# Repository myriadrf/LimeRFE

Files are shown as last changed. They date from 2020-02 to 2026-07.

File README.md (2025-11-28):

# LimeRFE

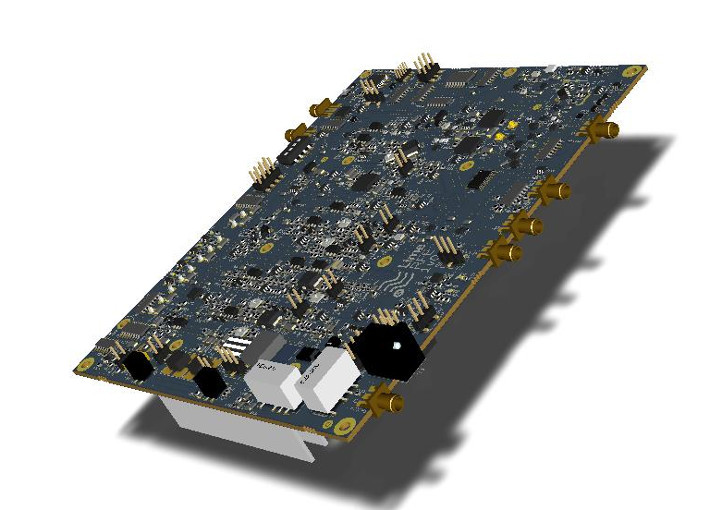
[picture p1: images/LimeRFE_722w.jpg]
LimeRFE board


The [LimeRFE](https://www.crowdsupply.com/lime-micro/limerfe) is an open hardware power amplifier (PA) module with appropriate filtering and support circuitry to augment the LimeSDR, LimeSDR Mini, and LimeNET Micro platforms, providing a complete solution that addresses real life applications ranging from HAM radio to standards-compliant cellular network implementations.

## Contents

The directory structure is as follows:

      /archived/<version>/           - Archived versions
          firmware/                  - Corresponding firmware
                                     - Remaining structure as below

      /firmware/                     - Firmware sources

      /hardware/<version>/
          docs/                      - Documentation
          hardware/
              BOM/                   - Bill of materials
              Gerbers/               - Manufacturing files
              KiCAD/                 - KiCAD schematic and layout files
              PDF/                   - Schematic and layout PDFs

## Notes on hardware versions

The resources for all production builds will be located in versioned folders in the repository root. The files located under `/archived/` correspond to pre-production designs used in validation and with the beta tester community.

### Production boards

* 1v31. This is the first version to go into full production.

### Pre-production boards

Pre-production boards are not officially supported. However, design materials and firmware sources are made available in the hope that this will assist those who may wish to make their own modifications and repairs etc. 

* 1v2. This features a number of minor improvements to the 1v0 design, mainly in
connection with cellular bands.
* 1v0. This design featured the full complement of bands following [update of the specifications](https://www.crowdsupply.com/lime-micro/limerfe/updates/performance-of-the-final-production-board). A small number of boards were made available to application developers to facilitate software integration.
* 0v3. This version was the first made available to the beta tester community and it has a reduced number of branches/bands, which corresponds to the original published specifications. 

## Software

Software support is provided by [Lime Suite](https://github.com/myriadrf/LimeSuite).

## Licensing

The hardware designs are licensed under Solderpad Hardware License v2.1.

Hardware designs 0v3, 1v0 and 1v2 are also available under a Creative Commons
Attribution 3.0 Unported licence.

Firmware sources are licensed under the Apache License Version 2.0.

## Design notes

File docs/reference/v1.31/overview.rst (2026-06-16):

Overview
########

The scope of this chapter is in detailed explanation of the block diagram of the LimeRFE board. The above mentioned block diagram is shown in Figure 3. Please keep in mind that this block diagram depicts only RF part of the board. 

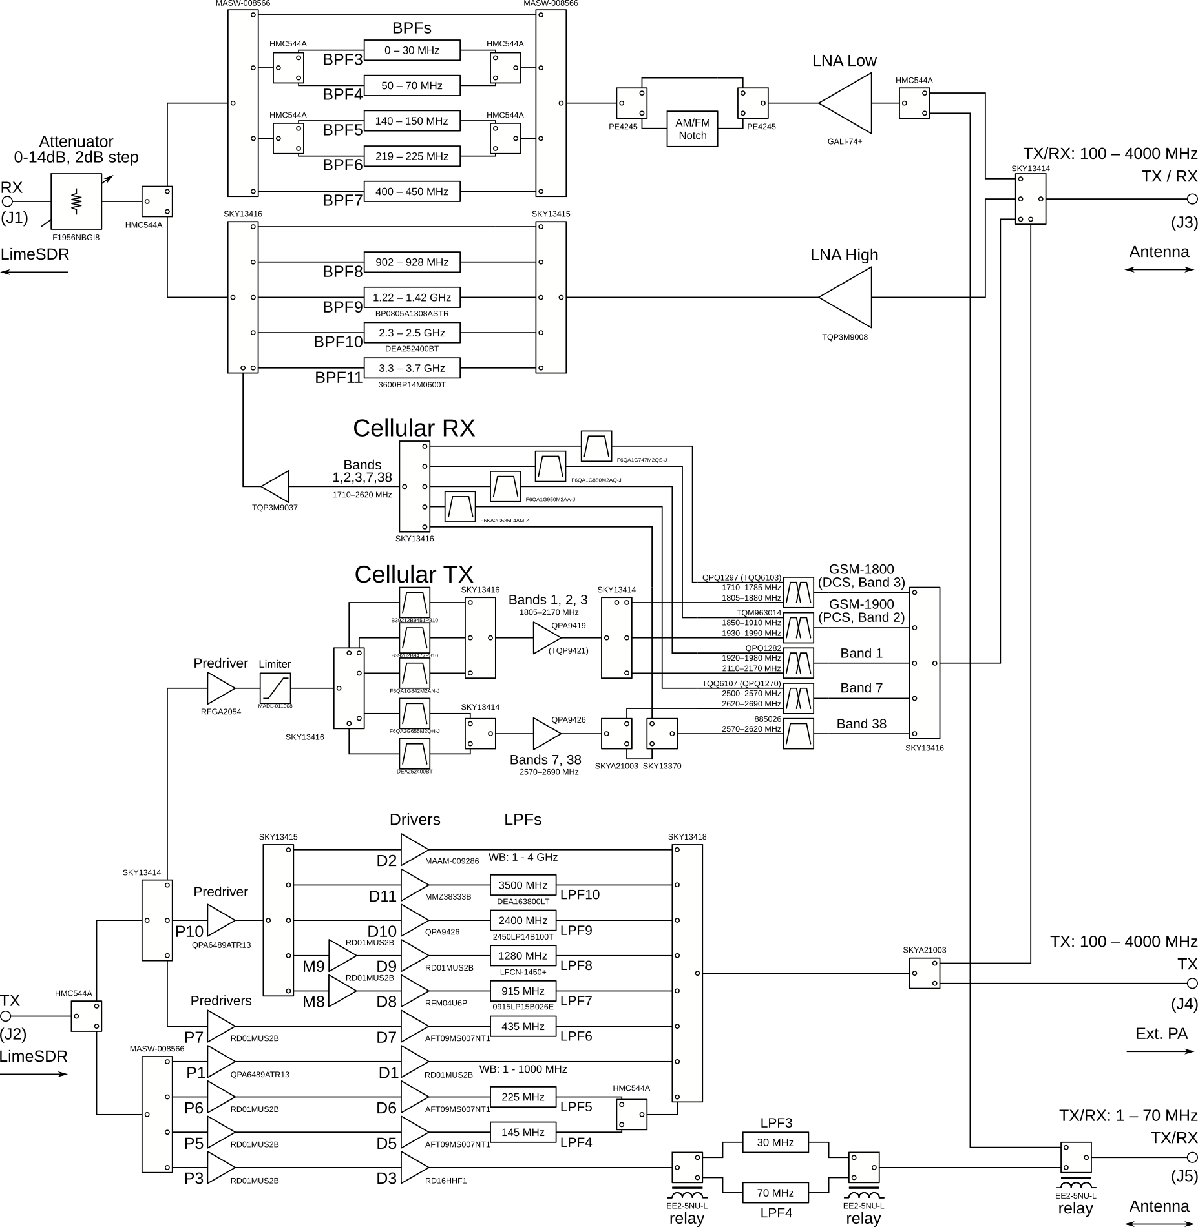
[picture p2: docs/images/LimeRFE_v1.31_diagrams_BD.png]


  Figure 3: LimeRFE v1.31 board block diagram

Basically, the board comprises receiver and transmitter blocks, where both of them have Wideband, HAM and Cellular sub-blocks. These sub-blocks are not strictly divided and separated, for example HAM and Wideband have been realised under the same hardware. Photo of the LimeRFE board, with marked most important RF blocks is shown in Figure 4 and in Figure 5. 

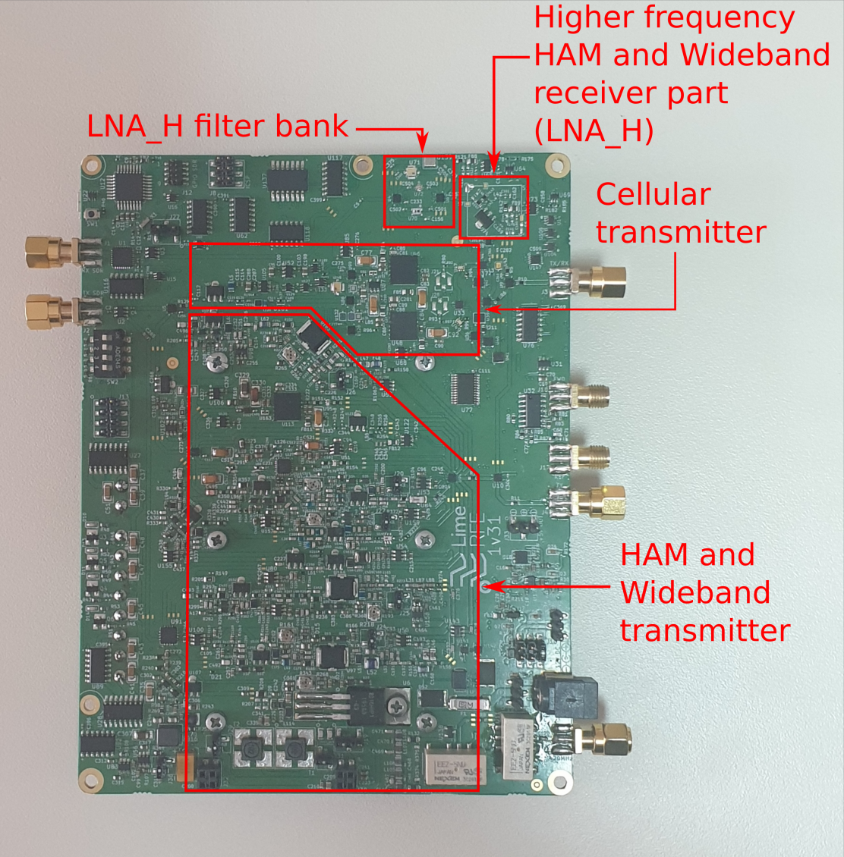
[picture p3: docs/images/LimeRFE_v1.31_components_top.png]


  Figure 4: Receiver and transmitter sub-blocks – Top view

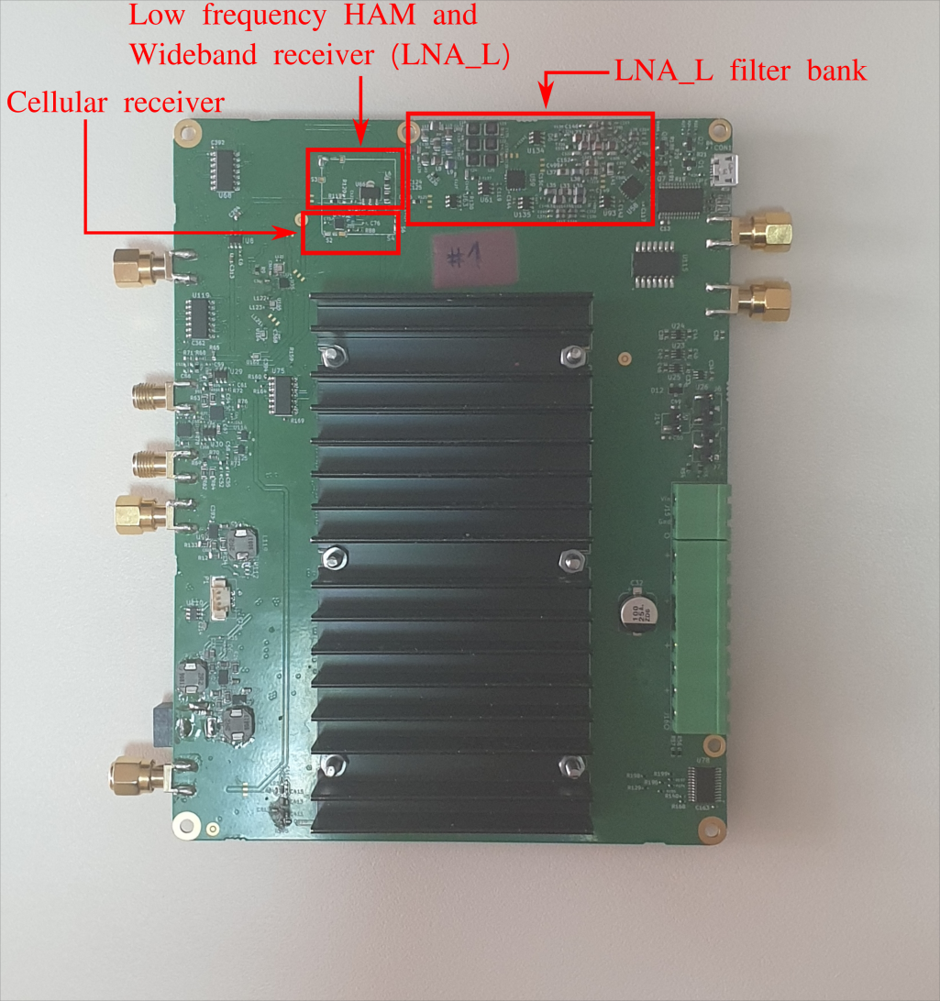
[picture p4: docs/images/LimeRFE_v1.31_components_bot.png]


  Figure 5: Receiver and transmitter sub-blocks – Bottom view
    
.. table:: Table 1. Board components

  +-----------------------+--------------------------------------+-----------------------------------------------------------------------------------------------------+
  | **Board Reference**   | **Type**                             | **Description**                                                                                     |
  +=======================+======================================+=====================================================================================================+
  | **DC Supply Block**                                                                                                                                                |
  +-----------------------+--------------------------------------+-----------------------------------------------------------------------------------------------------+
  | J9                    | 3 pin header                         | 12V DC input                                                                                        |
  +-----------------------+--------------------------------------+-----------------------------------------------------------------------------------------------------+
  | J23                   | Power Barrel Connector Jack          | 12V DC input                                                                                        |
  +-----------------------+--------------------------------------+-----------------------------------------------------------------------------------------------------+
  | J10                   | 3 pin header                         | 5V DC input                                                                                         |
  +-----------------------+--------------------------------------+-----------------------------------------------------------------------------------------------------+
  | J11                   | 3x2 pin header                       | 5V input selector                                                                                   |
  +-----------------------+--------------------------------------+-----------------------------------------------------------------------------------------------------+
  | J33                   | 3 pin header                         | 5V DC output                                                                                        |
  +-----------------------+--------------------------------------+-----------------------------------------------------------------------------------------------------+
  | U17                   | LDO 3V                               | Provides a stable 3V DC                                                                             |
  +-----------------------+--------------------------------------+-----------------------------------------------------------------------------------------------------+
  | U18                   | LDO 2.5V                             | Provides a stable 2.5V DC                                                                           |
  +-----------------------+--------------------------------------+-----------------------------------------------------------------------------------------------------+
  | U19                   | DC-DC converter                      | Converts 12V to internal 5V                                                                         |
  +-----------------------+--------------------------------------+-----------------------------------------------------------------------------------------------------+
  | U20                   | 5V input protection                  | Monitors and protects 5V input                                                                      |
  +-----------------------+--------------------------------------+-----------------------------------------------------------------------------------------------------+
  | U21                   | DC-DC converter                      | Converts 12V to internal 7.5V                                                                       |
  +-----------------------+--------------------------------------+-----------------------------------------------------------------------------------------------------+
  | U90                   | DC-DC converter                      | Converts 12V to external 5V                                                                         |
  +-----------------------+--------------------------------------+-----------------------------------------------------------------------------------------------------+
  | U112                  | LDO 2.5V                             | Provides a stable 2.5V DC                                                                           |
  +-----------------------+--------------------------------------+-----------------------------------------------------------------------------------------------------+
  | D3                    | LED                                  | +3V indicator                                                                                       |
  +-----------------------+--------------------------------------+-----------------------------------------------------------------------------------------------------+
  | D7                    | LED                                  | +5V indicator                                                                                       |
  +-----------------------+--------------------------------------+-----------------------------------------------------------------------------------------------------+
  | D8                    | LED                                  | +5V_MCU indicator                                                                                   |
  +-----------------------+--------------------------------------+-----------------------------------------------------------------------------------------------------+
  | D9                    | LED                                  | +7.5V indicator                                                                                     |
  +-----------------------+--------------------------------------+-----------------------------------------------------------------------------------------------------+
  | D36                   | LED                                  | +2.5V indicator                                                                                     |
  +-----------------------+--------------------------------------+-----------------------------------------------------------------------------------------------------+
  | U110                  | Power switch                         | Switches +5V DC voltage for external fan.                                                           |
  +-----------------------+--------------------------------------+-----------------------------------------------------------------------------------------------------+
  | U83                   | Power switch                         | Switches +12V supply for the DA (driver) for HAM30 and HAM70                                        |
  +-----------------------+--------------------------------------+-----------------------------------------------------------------------------------------------------+
  | U56                   | Power switch                         | Switches +12V supply for the PA (power amplifier) for HAM30 and HAM70                               |
  +-----------------------+--------------------------------------+-----------------------------------------------------------------------------------------------------+
  | U100                  | Power switch                         | Switches +7.5V supply for the DA for HAM145                                                         |
  +-----------------------+--------------------------------------+-----------------------------------------------------------------------------------------------------+
  | U50                   | Power switch                         | Switches +7.5V supply for the PA for HAM145                                                         |
  +-----------------------+--------------------------------------+-----------------------------------------------------------------------------------------------------+
  | U153                  | Power switch                         | Switches +7.5V supply for the DA for HAM220                                                         |
  +-----------------------+--------------------------------------+-----------------------------------------------------------------------------------------------------+
  | U158                  | Power switch                         | Switches +7.5V supply for the PA for HAM220                                                         |
  +-----------------------+--------------------------------------+-----------------------------------------------------------------------------------------------------+
  | U80                   | Power switch                         | Switches +5V supply for the DA for WB1000                                                           |
  +-----------------------+--------------------------------------+-----------------------------------------------------------------------------------------------------+
  | U54                   | Power switch                         | Switches +5V supply for the PA for WB1000                                                           |
  +-----------------------+--------------------------------------+-----------------------------------------------------------------------------------------------------+
  | U155                  | Power switch                         | Switches +12V supply for the DA for HAM920                                                          |
  +-----------------------+--------------------------------------+-----------------------------------------------------------------------------------------------------+
  | U159                  | Power switch                         | Switches +7.5V supply for the PA for HAM920                                                         |
  +-----------------------+--------------------------------------+-----------------------------------------------------------------------------------------------------+
  | U157                  | Power switch                         | Switches +12V supply for the DA for HAM1280                                                         |
  +-----------------------+--------------------------------------+-----------------------------------------------------------------------------------------------------+
  | U53                   | Power switch                         | Switches +12V supply for the PA for HAM1280                                                         |
  +-----------------------+--------------------------------------+-----------------------------------------------------------------------------------------------------+
  | U51                   | Power switch                         | Switches +5V supply for the PA for HAM3500                                                          |
  +-----------------------+--------------------------------------+-----------------------------------------------------------------------------------------------------+
  | U122                  | Power switch                         | Switches +5V supply for the PA for WB4000                                                           |
  +-----------------------+--------------------------------------+-----------------------------------------------------------------------------------------------------+
  | U120                  | Power switch                         | Switches +5V supply for the PA for HAM2400                                                          |
  +-----------------------+--------------------------------------+-----------------------------------------------------------------------------------------------------+
  | U106                  | LDO 2.8V                             | LDO for PA supply for the HAM2400, (U113)                                                           |
  +-----------------------+--------------------------------------+-----------------------------------------------------------------------------------------------------+
  | U96                   | Power switch                         | Switches +7.5V supply for the DA for HAM435                                                         |
  +-----------------------+--------------------------------------+-----------------------------------------------------------------------------------------------------+
  | U55                   | Power switch                         | Switches +7.5V supply for the PA for HAM435                                                         |
  +-----------------------+--------------------------------------+-----------------------------------------------------------------------------------------------------+
  | U102                  | Power switch                         | Switches +7.5V supply for the DA for HAM920, HAM1280, HAM3500, HAM2400 and WB4000                   |
  +-----------------------+--------------------------------------+-----------------------------------------------------------------------------------------------------+
  | U105                  | Power switch                         | Switches +5V supply for the DA for Cellular bands 1, 2, 3, 7 and 38                                 |
  +-----------------------+--------------------------------------+-----------------------------------------------------------------------------------------------------+
  | U87                   | LDO 2.8V                             | LDO for PA supply for the Cellular bands 1, 2 and 3, (U48)                                          |
  +-----------------------+--------------------------------------+-----------------------------------------------------------------------------------------------------+
  | U88                   | Power switch                         | Switches +5V supply for the PA Cellular bands 1, 2 and 3 (U48)                                      |
  +-----------------------+--------------------------------------+-----------------------------------------------------------------------------------------------------+
  | U52                   | LDO 2.8V                             | LDO for PA supply for the Cellular bands 7 and 38, (U46)                                            |
  +-----------------------+--------------------------------------+-----------------------------------------------------------------------------------------------------+
  | U85                   | Power switch                         | Switches +5V supply for the PA Cellular bands 7 and 38 (U46)                                        |
  +-----------------------+--------------------------------------+-----------------------------------------------------------------------------------------------------+
  | U130                  | DC switch                            | Switches +3V supply for the PA Cellular bands 7 and 38 (U46)                                        |
  +-----------------------+--------------------------------------+-----------------------------------------------------------------------------------------------------+
  | U133                  | Buffer                               | Switches +3V supply for the PA Cellular bands 7 and 38 (U46)                                        |
  +-----------------------+--------------------------------------+-----------------------------------------------------------------------------------------------------+
  | U73                   | Power switch                         | Switches +5V supply for the LNA for higher frequency bands (HAM1280, HAM3500,                       |
  |                       |                                      |                                                                                                     |
  |                       |                                      | HAM2400, HAM920 and WB4000)                                                                         |
  +-----------------------+--------------------------------------+-----------------------------------------------------------------------------------------------------+
  | U65                   | Power switch                         | Switches +5V supply for the LNA for lower frequency bands (HAM30, HAM70, HAM145,                    |
  |                       |                                      |                                                                                                     |
  |                       |                                      | HAM220, HAM435 and WB1000)                                                                          |
  +-----------------------+--------------------------------------+-----------------------------------------------------------------------------------------------------+
  | U31                   | Power switch                         | Switches +5V supply for the SWR section                                                             |
  +-----------------------+--------------------------------------+-----------------------------------------------------------------------------------------------------+
  | **MCU and Digital Block**                                                                                                                                          |
  +-----------------------+--------------------------------------+-----------------------------------------------------------------------------------------------------+
  | U12                   | MCU                                  | ATMEGA 328P microcontroller                                                                         |
  +-----------------------+--------------------------------------+-----------------------------------------------------------------------------------------------------+
  | U13                   | USB-to-serial chip                   | Converts USB to MCU serial communication and vice versa                                             |
  +-----------------------+--------------------------------------+-----------------------------------------------------------------------------------------------------+
  | J8                    | ICSP connector                       | SPI bus to MCU                                                                                      |
  +-----------------------+--------------------------------------+-----------------------------------------------------------------------------------------------------+
  | D1, D2                | LED                                  | USB to Serial communication indicator                                                               |
  +-----------------------+--------------------------------------+-----------------------------------------------------------------------------------------------------+
  | CON1                  | USB mini-B connector                 | USB connector for the LimeRFE board                                                                 |
  +-----------------------+--------------------------------------+-----------------------------------------------------------------------------------------------------+
  | U22                   | USB protection                       | Protects USB lines from over-voltages                                                               |
  +-----------------------+--------------------------------------+-----------------------------------------------------------------------------------------------------+
  | U60, U62, U68, U75,   | Shift registers                      | Saves the current state of the LimeRFE                                                              |
  |                       |                                      |                                                                                                     |
  | U76, U89, U92, U116,  |                                      |                                                                                                     |
  |                       |                                      |                                                                                                     |
  | U117, U118, U119      |                                      |                                                                                                     |
  +-----------------------+--------------------------------------+-----------------------------------------------------------------------------------------------------+
  | J12                   | GPIO and I2C connector               | PINS:                                                                                               |
  |                       |                                      |                                                                                                     |
  |                       |                                      | GPIO0, GPIO1, GPIO2, GPIO3_CONN, GPIO4,                                                             |
  |                       |                                      |                                                                                                     |
  |                       |                                      | GPIO5, SCL, SDA, GND, VDD_CON                                                                       |
  +-----------------------+--------------------------------------+-----------------------------------------------------------------------------------------------------+
  | J13                   | Level Shifted GPIO and ADC connector | PINS:                                                                                               |
  |                       |                                      |                                                                                                     |
  |                       |                                      | GPIO0_LS, GPIO2_LS, ADC1, GND,                                                                      |
  |                       |                                      |                                                                                                     |
  |                       |                                      | VDDA, ADC2, GPIO3_LS, GPIO1_LS                                                                      |
  +-----------------------+--------------------------------------+-----------------------------------------------------------------------------------------------------+
  | U23, U24, U25, U26    | Level Shifters                       | Converts voltage levels of GPIO signals;                                                            |
  |                       |                                      |                                                                                                     |
  |                       |                                      | between VDD_CON (GPIO) and VDDA (GPIO_LS)                                                           |
  +-----------------------+--------------------------------------+-----------------------------------------------------------------------------------------------------+
  | SW2                   | Switch                               | Sets directions of U23-26, for GPIO signals (between GPIO and GPIO_LS)                              |
  +-----------------------+--------------------------------------+-----------------------------------------------------------------------------------------------------+
  | J14                   | 2 pin header                         | In a case VDD_CON = VDDA connects these two voltages                                                |
  +-----------------------+--------------------------------------+-----------------------------------------------------------------------------------------------------+
  | J22                   | 3 pin header                         | Selects GPIO3 source, either GPIO3_CONN or GPIO5                                                    |
  +-----------------------+--------------------------------------+-----------------------------------------------------------------------------------------------------+
  | D10, D11, D12, D13    | LED                                  | Indicators for GPIO0, GPIO2, GPIO1, GPIO3 respectively                                              |
  +-----------------------+--------------------------------------+-----------------------------------------------------------------------------------------------------+
  | Q3, Q4, Q5, Q6        | BJT NPN                              | Drivers for D10-13, for GPIO0, GPIO2, GPIO1, GPIO3 respectively                                     |
  +-----------------------+--------------------------------------+-----------------------------------------------------------------------------------------------------+
  | U27, U28              | Relay drivers                        | Drivers for RELAY_0, RELAY_1, RELAY_2, RELAY_3 signals                                              |
  +-----------------------+--------------------------------------+-----------------------------------------------------------------------------------------------------+
  | J16                   | 8 position header                    | Connects LimeRFE to the external relays                                                             |
  +-----------------------+--------------------------------------+-----------------------------------------------------------------------------------------------------+
  | J15                   | 2 position header                    | DC voltage for drivers for relays                                                                   |
  +-----------------------+--------------------------------------+-----------------------------------------------------------------------------------------------------+
  | U115                  | Inverter                             | It is used as 2.5V – 3.0V level shifter for digital signals obtained from U116 and U117,            |
  |                       |                                      |                                                                                                     |
  |                       |                                      | from the LimeRFE shift register                                                                     |
  +-----------------------+--------------------------------------+-----------------------------------------------------------------------------------------------------+
  | U77, U78              | Level shifter                        | Level shifter for digital signals which control TX HAM and WB sub-blocks                            |
  +-----------------------+--------------------------------------+-----------------------------------------------------------------------------------------------------+
  | U127, U129            | Inverter                             | Controls digital signals for TDD TX/RX RF switch (U128 )                                            |
  +-----------------------+--------------------------------------+-----------------------------------------------------------------------------------------------------+
  | U141, U142            | Inverter                             | Controls digital signals for RF switch for TX HAM145 and HAM220 (U143)                              |
  +-----------------------+--------------------------------------+-----------------------------------------------------------------------------------------------------+
  | U69                   | Logical AND                          | Generates control signals for LNA_EN for LNA in higher frequency bands (HAM1280,                    |
  |                       |                                      |                                                                                                     |
  |                       |                                      | HAM3500, HAM2400, HAM920 and WB4000)                                                                |
  +-----------------------+--------------------------------------+-----------------------------------------------------------------------------------------------------+
  | U137                  | Inverter                             | Generates control signals for RF switches in RX lower frequency section.                            |
  |                       |                                      |                                                                                                     |
  |                       |                                      | (U38, U134, U93 and U135)                                                                           |
  +-----------------------+--------------------------------------+-----------------------------------------------------------------------------------------------------+
  | U64                   | Logical AND                          | Generates control signals for LNA_EN for LNA for lower frequency bands                              |
  |                       |                                      |                                                                                                     |
  |                       |                                      | (HAM30, HAM70, HAM435, HAM220, HAM145, WB1000)                                                      |
  +-----------------------+--------------------------------------+-----------------------------------------------------------------------------------------------------+
  | U7                    | Relay driver                         | Generates control signal for RF switch U11                                                          |
  +-----------------------+--------------------------------------+-----------------------------------------------------------------------------------------------------+
  | U114, U125            | Inverter                             | Generates control signal for RF switches U29 and U30 in SWR section.                                |
  +-----------------------+--------------------------------------+-----------------------------------------------------------------------------------------------------+
  | U32                   | OP amp                               | Operational amplifier in SWR section                                                                |
  +-----------------------+--------------------------------------+-----------------------------------------------------------------------------------------------------+
  | **RF Block**                                                                                                                                                       |
  +-----------------------+--------------------------------------+-----------------------------------------------------------------------------------------------------+
  | J1                    | SMA                                  | RX connector                                                                                        |
  +-----------------------+--------------------------------------+-----------------------------------------------------------------------------------------------------+
  | J2                    | SMA                                  | TX connector                                                                                        |
  +-----------------------+--------------------------------------+-----------------------------------------------------------------------------------------------------+
  | J3                    | SMA                                  | TX/RX antenna connector                                                                             |
  +-----------------------+--------------------------------------+-----------------------------------------------------------------------------------------------------+
  | J4                    | SMA                                  | TX antenna connector                                                                                |
  +-----------------------+--------------------------------------+-----------------------------------------------------------------------------------------------------+
  | J5                    | SMA                                  | Mostly for TX/RX antenna connector for 30 MHz and 70 MHz bands.                                     |
  +-----------------------+--------------------------------------+-----------------------------------------------------------------------------------------------------+
  | J17                   | SMA                                  | Reverse power RF input (for SWR operation)                                                          |
  +-----------------------+--------------------------------------+-----------------------------------------------------------------------------------------------------+
  | J18                   | SMA                                  | Forward power RF input (for SWR operation)                                                          |
  +-----------------------+--------------------------------------+-----------------------------------------------------------------------------------------------------+
  | U11                   | RF switch – relay                    | TX/RX switch for HAM30 and HAM70 bands                                                              |
  +-----------------------+--------------------------------------+-----------------------------------------------------------------------------------------------------+
  | U1                    | Digital step attenuator              | Attenuates RX RF signal going to J1                                                                 |
  +-----------------------+--------------------------------------+-----------------------------------------------------------------------------------------------------+
  | U2                    | RF switch                            | RF switch in TX path                                                                                |
  +-----------------------+--------------------------------------+-----------------------------------------------------------------------------------------------------+
  | U3                    | RF switch                            | RF switch in RX path                                                                                |
  +-----------------------+--------------------------------------+-----------------------------------------------------------------------------------------------------+
  | U4                    | RF switch                            | RF switch in RX path                                                                                |
  +-----------------------+--------------------------------------+-----------------------------------------------------------------------------------------------------+
  | U5                    | RF switch                            | RF switch in TX path                                                                                |
  +-----------------------+--------------------------------------+-----------------------------------------------------------------------------------------------------+
  | U8                    | RF switch                            | RF switch in RX path                                                                                |
  +-----------------------+--------------------------------------+-----------------------------------------------------------------------------------------------------+
  | U9                    | RF switch                            | RF switch in TX/RX path                                                                             |
  +-----------------------+--------------------------------------+-----------------------------------------------------------------------------------------------------+
  | U10                   | RF switch                            | RF switch in TX/RX path                                                                             |
  +-----------------------+--------------------------------------+-----------------------------------------------------------------------------------------------------+
  | U91                   | RF switch                            | RF switch for TX lower frequency bands (HAM30, HAM70, HAM145, HAM220, WB1000)                       |
  +-----------------------+--------------------------------------+-----------------------------------------------------------------------------------------------------+
  | U94                   | RF switch                            | RF switch for TX                                                                                    |
  +-----------------------+--------------------------------------+-----------------------------------------------------------------------------------------------------+
  | U140                  | RF switch                            | RF switch for TX higher frequency bands (HAM920, HAM1280, HAM3500, HAM2400,                         |
  |                       |                                      |                                                                                                     |
  |                       |                                      | HAM435 and WB4000)                                                                                  |
  +-----------------------+--------------------------------------+-----------------------------------------------------------------------------------------------------+
  | U143                  | RF switch                            | RF switch for TX bands HAM145 and HAM220                                                            |
  +-----------------------+--------------------------------------+-----------------------------------------------------------------------------------------------------+
  | U160                  | RF limiter                           | RF limiter in TX Cellular section                                                                   |
  +-----------------------+--------------------------------------+-----------------------------------------------------------------------------------------------------+
  | U161                  | RF attenuator                        | RF attenuator in TX Cellular section                                                                |
  +-----------------------+--------------------------------------+-----------------------------------------------------------------------------------------------------+
  | U86, U36              | RF switch                            | RF switch for TX Cellular section, for bands 1, 2, 3, 7 and 38                                      |
  +-----------------------+--------------------------------------+-----------------------------------------------------------------------------------------------------+
  | U99, U37              | RF switch                            | RF switch for TX Cellular section, for bands 7 and 38                                               |
  +-----------------------+--------------------------------------+-----------------------------------------------------------------------------------------------------+
  | U126                  | RF switch                            | RF switch for TX Cellular section, for bands 1, 2 and 3                                             |
  +-----------------------+--------------------------------------+-----------------------------------------------------------------------------------------------------+
  | U44                   | RF switch                            | RF switch for TX/RX Cellular section, for bands 1, 2, 3, 7 and 38                                   |
  +-----------------------+--------------------------------------+-----------------------------------------------------------------------------------------------------+
  | U35                   | RF switch                            | RF switch for RX Cellular section, for bands 1, 2, 3, 7 and 38                                      |
  +-----------------------+--------------------------------------+-----------------------------------------------------------------------------------------------------+
  | U33                   | RF switch                            | RF switch in TX Cellular section for bands 1, 2, 3, 7 and 38, for RF signals coupled to amplifiers  |
  |                       |                                      |                                                                                                     |
  |                       |                                      | outputs.                                                                                            |
  +-----------------------+--------------------------------------+-----------------------------------------------------------------------------------------------------+
  | U128                  | RF switch                            | TX/RX RF switch for TDD band 38                                                                     |
  +-----------------------+--------------------------------------+-----------------------------------------------------------------------------------------------------+
  | U132                  | RF filter                            | RF filter for TX Cellular section, band 1, downlink                                                 |
  +-----------------------+--------------------------------------+-----------------------------------------------------------------------------------------------------+
  | U34                   | RF filter                            | RF filter for TX Cellular section, band 2, downlink                                                 |
  +-----------------------+--------------------------------------+-----------------------------------------------------------------------------------------------------+
  | U31                   | RF filter                            | RF filter for TX Cellular section, band 3, downlink                                                 |
  +-----------------------+--------------------------------------+-----------------------------------------------------------------------------------------------------+
  | U136                  | RF filter                            | RF filter for TX Cellular section, band 7, downlink                                                 |
  +-----------------------+--------------------------------------+-----------------------------------------------------------------------------------------------------+
  | U41                   | RF diplexer                          | RF diplexer for TX/RX Cellular section, band 1                                                      |
  +-----------------------+--------------------------------------+-----------------------------------------------------------------------------------------------------+
  | U40                   | RF diplexer                          | RF diplexer for TX/RX Cellular section, band 2                                                      |
  +-----------------------+--------------------------------------+-----------------------------------------------------------------------------------------------------+
  | U39                   | RF diplexer                          | RF diplexer for TX/RX Cellular section, band 3                                                      |
  +-----------------------+--------------------------------------+-----------------------------------------------------------------------------------------------------+
  | U42                   | RF diplexer                          | RF diplexer for TX/RX Cellular section, band 7                                                      |
  +-----------------------+--------------------------------------+-----------------------------------------------------------------------------------------------------+
  | U43                   | RF filter                            | RF filter for TX/RX Cellular section, band 38                                                       |
  +-----------------------+--------------------------------------+-----------------------------------------------------------------------------------------------------+
  | U67                   | RF switch                            | RF switch for RX higher frequency bands (HAM920, HAM1280, HAM3500, HAM2400 and                      |
  |                       |                                      |                                                                                                     |
  |                       |                                      | WB4000)                                                                                             |
  +-----------------------+--------------------------------------+-----------------------------------------------------------------------------------------------------+
  | U59, U58              | RF switch                            | RF switches for RX lower frequency bands (HAM145, HAM220, HAM435, HAM30, HAM70 and                  |
  |                       |                                      |                                                                                                     |
  |                       |                                      | WB1000)                                                                                             |
  +-----------------------+--------------------------------------+-----------------------------------------------------------------------------------------------------+
  | U38, U134             | RF switch                            | RF switches for RX lower frequency bands (HAM30 and HAM70)                                          |
  +-----------------------+--------------------------------------+-----------------------------------------------------------------------------------------------------+
  | U93, U135             | RF switch                            | RF switches for RX lower frequency bands (HAM145 and HAM220)                                        |
  +-----------------------+--------------------------------------+-----------------------------------------------------------------------------------------------------+
  | U61, U63              | RF switch                            | RF switches for RX lower frequency bands (HAM920, HAM1280, HAM3500, HAM2400 and                     |
  |                       |                                      |                                                                                                     |
  |                       |                                      | WB4000) for notch filter which suppresses FM bands                                                  |
  +-----------------------+--------------------------------------+-----------------------------------------------------------------------------------------------------+
  | U107                  | RF transistor                        | DA (driver) for HAM30 and HAM70                                                                     |
  +-----------------------+--------------------------------------+-----------------------------------------------------------------------------------------------------+
  | U6                    | RF transistor                        | PA (power amplifier) for HAM30 and HAM70                                                            |
  +-----------------------+--------------------------------------+-----------------------------------------------------------------------------------------------------+
  | U111                  | RF transistor                        | DA for HAM145                                                                                       |
  +-----------------------+--------------------------------------+-----------------------------------------------------------------------------------------------------+
  | U97                   | RF transistor                        | PA for HAM145                                                                                       |
  +-----------------------+--------------------------------------+-----------------------------------------------------------------------------------------------------+
  | U152                  | RF transistor                        | DA for HAM220                                                                                       |
  +-----------------------+--------------------------------------+-----------------------------------------------------------------------------------------------------+
  | U144                  | RF transistor                        | PA for HAM220                                                                                       |
  +-----------------------+--------------------------------------+-----------------------------------------------------------------------------------------------------+
  | U79                   | RF transistor                        | DA for WB1000                                                                                       |
  +-----------------------+--------------------------------------+-----------------------------------------------------------------------------------------------------+
  | U101                  | RF transistor                        | PA for WB1000                                                                                       |
  +-----------------------+--------------------------------------+-----------------------------------------------------------------------------------------------------+
  | U154                  | RF transistor                        | DA for HAM920                                                                                       |
  +-----------------------+--------------------------------------+-----------------------------------------------------------------------------------------------------+
  | U145                  | RF transistor                        | PA for HAM920                                                                                       |
  +-----------------------+--------------------------------------+-----------------------------------------------------------------------------------------------------+
  | U156                  | RF transistor                        | DA for HAM1280                                                                                      |
  +-----------------------+--------------------------------------+-----------------------------------------------------------------------------------------------------+
  | U124                  | RF transistor                        | PA for HAM1280                                                                                      |
  +-----------------------+--------------------------------------+-----------------------------------------------------------------------------------------------------+
  | U82                   | RF chip                              | PA for HAM3500                                                                                      |
  +-----------------------+--------------------------------------+-----------------------------------------------------------------------------------------------------+
  | U123                  | RF chip                              | PA for WB4000                                                                                       |
  +-----------------------+--------------------------------------+-----------------------------------------------------------------------------------------------------+
  | U113                  | RF chip                              | PA for HAM2400                                                                                      |
  +-----------------------+--------------------------------------+-----------------------------------------------------------------------------------------------------+
  | U162                  | RF limiter                           | RF limiter for HAM2400                                                                              |
  +-----------------------+--------------------------------------+-----------------------------------------------------------------------------------------------------+
  | U163                  | RF attenuator                        | RF attenuator for HAM2400                                                                           |
  +-----------------------+--------------------------------------+-----------------------------------------------------------------------------------------------------+
  | U109                  | RF transistor                        | DA for HAM435                                                                                       |
  +-----------------------+--------------------------------------+-----------------------------------------------------------------------------------------------------+
  | U103                  | RF transistor                        | PA for HAM435                                                                                       |
  +-----------------------+--------------------------------------+-----------------------------------------------------------------------------------------------------+
  | U81                   | RF chip                              | DA for HAM920, HAM1280, HAM3500, HAM2400 and WB4000                                                 |
  +-----------------------+--------------------------------------+-----------------------------------------------------------------------------------------------------+
  | U57                   | RF chip                              | DA for Cellular bands 1, 2, 3, 7 and 38                                                             |
  +-----------------------+--------------------------------------+-----------------------------------------------------------------------------------------------------+
  | U48                   | RF chip                              | PA for Cellular bands 1, 2 and 3                                                                    |
  +-----------------------+--------------------------------------+-----------------------------------------------------------------------------------------------------+
  | U49                   | RF coupler                           | Couples the output of the PA in Cellular bands 1, 2 and 3, (U48)                                    |
  +-----------------------+--------------------------------------+-----------------------------------------------------------------------------------------------------+
  | U46                   | RF chip                              | PA for Cellular bands 7 and 38                                                                      |
  +-----------------------+--------------------------------------+-----------------------------------------------------------------------------------------------------+
  | U47                   | RF coupler                           | Couples the output of the PA in Cellular bands 7 and 38, (U46)                                      |
  +-----------------------+--------------------------------------+-----------------------------------------------------------------------------------------------------+
  | U45                   | RF chip                              | LNA for Cellular bands 1, 2, 3, 7 and 38                                                            |
  +-----------------------+--------------------------------------+-----------------------------------------------------------------------------------------------------+
  | U74                   | RF chip                              | LNA for higher frequency bands (HAM1280, HAM3500, HAM2400, HAM920 and WB4000)                       |
  +-----------------------+--------------------------------------+-----------------------------------------------------------------------------------------------------+
  | U66                   | RF chip                              | LNA for lower frequency bands (HAM30, HAM70, HAM145, HAM220, HAM435 and WB1000)                     |
  +-----------------------+--------------------------------------+-----------------------------------------------------------------------------------------------------+
  | U29                   | RF switch                            | RF switch for forward RF signal in SWR section                                                      |
  +-----------------------+--------------------------------------+-----------------------------------------------------------------------------------------------------+
  | U30                   | RF switch                            | RF switch for reflected RF signal in SWR section                                                    |
  +-----------------------+--------------------------------------+-----------------------------------------------------------------------------------------------------+
  | IC1                   | RF detector                          | RF detector in forward RF signal in SWR section                                                     |
  +-----------------------+--------------------------------------+-----------------------------------------------------------------------------------------------------+
  | IC2                   | RF detector                          | RF detector in reflected RF signal in SWR section                                                   |
  +-----------------------+--------------------------------------+-----------------------------------------------------------------------------------------------------+
  | U70                   | RF filter                            | RF filter in RX higher frequency band HAM1280 band                                                  |
  +-----------------------+--------------------------------------+-----------------------------------------------------------------------------------------------------+
  | U72                   | RF filter                            | RF filter in RX higher frequency band HAM3500 band                                                  |
  +-----------------------+--------------------------------------+-----------------------------------------------------------------------------------------------------+
  | U71                   | RF filter                            | RF filter in RX higher frequency band HAM2400 band                                                  |
  +-----------------------+--------------------------------------+-----------------------------------------------------------------------------------------------------+
  | U139                  | RF filter                            | RF filter in RX higher frequency band HAM920 band                                                   |
  +-----------------------+--------------------------------------+-----------------------------------------------------------------------------------------------------+
  | U95                   | RF filter                            | RF filter in TX higher frequency band HAM2400 band                                                  |
  +-----------------------+--------------------------------------+-----------------------------------------------------------------------------------------------------+
  | U96                   | RF filter                            | RF filter in TX higher frequency band HAM3500 band                                                  |
  +-----------------------+--------------------------------------+-----------------------------------------------------------------------------------------------------+
  | U84                   | RF filter                            | RF filter in TX higher frequency band HAM1280 band                                                  |
  +-----------------------+--------------------------------------+-----------------------------------------------------------------------------------------------------+
  | U146                  | RF filter                            | RF filter in TX higher frequency band HAM920 band                                                   |
  +-----------------------+--------------------------------------+-----------------------------------------------------------------------------------------------------+
  | **Mechanical Block**                                                                                                                                               |
  +-----------------------+--------------------------------------+-----------------------------------------------------------------------------------------------------+
  | H1                    | Heat sink                            | Aluminum black anodized heat sink                                                                   |
  +-----------------------+--------------------------------------+-----------------------------------------------------------------------------------------------------+
  | P1                    | 3 pin FAN connector                  | Connects an external fan                                                                            |
  +-----------------------+--------------------------------------+-----------------------------------------------------------------------------------------------------+

A more detailed description is provided in the following sections.

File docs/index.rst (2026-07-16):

Introduction
############

.. toctree::
   :maxdepth: 3
   :hidden:
   
   Introduction <self>
   user/index
   reference/index
   developer/index
   advanced/index



Lime RF Front-End (LimeRFE) is an open hardware RF front-end module with support circuitry to augment the LimeSDR family of boards and LimeNET Micro, providing a complete solution that addresses applications ranging from amateur radio to standards-compliant cellular networks.

A single LimeRFE covers three very different sets of bands: cellular, amateur radio and wideband. The exact band used at any given time is software selectable. By making the RF front-end definable in software, LimeRFE is the next step in the evolution of software-defined radio.

LimeRFE provides not only transmit and receive amplification, but also band-specific filtering and integrates duplexers for cellular band FDD operation. In addition to which it provides power and VSWR (requires external directional coupler) metering, and configuration is possible via either USB or direct connection to a LimeSDR board.

Specifications
**************

RX
==
.. table:: Maximum input signals for RX
      
   +------------------+-------------------------+------------------------------------+------------------------------------+-------------+
   | **Channel**      | **Channel Description** | **RF Input Power [dBm]**           | **RF Input Power [dBm]**           | **Comment** |
   |                  |                         |                                    |                                    |             |  
   |                  |                         | **LimeRFE 1v0**                    | **LimeRFE 1v31**                   |             |
   +==================+=========================+====================================+====================================+=============+
   | HAM 30           | HF                      | 10                                 | 10                                 |             |
   +------------------+-------------------------+                                    |                                    |             |
   | HAM 50 and 70    | 6 and 4 m               |                                    |                                    |             |
   +------------------+-------------------------+                                    |                                    |             |
   | HAM 145          | 2 m                     |                                    |                                    |             |
   +------------------+-------------------------+                                    |                                    |             |
   | HAM 220          | 1.25 m                  |                                    |                                    |             |
   +------------------+-------------------------+                                    |                                    |             |
   | HAM 435          | 70 cm                   |                                    |                                    |             |
   +------------------+-------------------------+                                    |                                    |             |
   | Wideband 1000    | 1 – 1000 MHz            |                                    |                                    |             |
   +------------------+-------------------------+------------------------------------+------------------------------------+-------------+
   | HAM 915          | 33 cm                   | 20                                 | 20                                 |             |
   +------------------+-------------------------+                                    |                                    |             |
   | HAM 1280         | 23 cm                   |                                    |                                    |             |
   +------------------+-------------------------+                                    |                                    |             |
   | HAM 2400         | 13 cm                   |                                    |                                    |             |
   +------------------+-------------------------+                                    |                                    |             |
   | HAM 3500         | /                       |                                    |                                    |             |
   +------------------+-------------------------+                                    |                                    |             |
   | Wideband 4000    | 1 – 4 GHz               |                                    |                                    |             |
   +------------------+-------------------------+------------------------------------+------------------------------------+-------------+
   | Cellular Band 1  | LTE Band 1              | 20                                 | 20                                 |             |
   +------------------+-------------------------+                                    |                                    |             |
   | Cellular Band 2  | LTE Band 2/ PCS-1900    |                                    |                                    |             |
   +------------------+-------------------------+                                    |                                    |             |
   | Cellular Band 3  | LTE Band 3/ DCS-1800    |                                    |                                    |             |
   +------------------+-------------------------+                                    |                                    |             |
   | Cellular Band 7  | LTE Band 7              |                                    |                                    |             |
   +------------------+-------------------------+                                    |                                    |             |
   | Cellular Band 38 | LTE Band 38             |                                    |                                    |             |
   +------------------+-------------------------+------------------------------------+------------------------------------+-------------+

.. note::
   The received signal will be amplified at the connector SDR RX (J1), care must be taken about that the maximum input RF power of the SDR connected is not exceeded.

TX
==

.. table:: Maximum input signals for TX

   +------------------+-------------------------+----------------------------------+------------------------------------+-------------+
   | **Channel**      | **Channel Description** | **RF Input Power [dBm]**         | **RF Input Power [dBm]**           | **Comment** |
   |                  |                         |                                  |                                    |             |
   |                  |                         | **LimeRFE 1v0**                  | **LimeRFE 1v31**                   |             |
   +==================+=========================+==================================+====================================+=============+
   | HAM 30           | HF                      | 13                               | 13                                 |             |
   +------------------+-------------------------+----------------------------------+------------------------------------+-------------+
   | HAM 50 and 70    | 6 and 4 m               | 13                               | 13                                 |             |
   +------------------+-------------------------+----------------------------------+------------------------------------+-------------+
   | HAM 145          | 2 m                     | 15                               | 15                                 |             |
   +------------------+-------------------------+----------------------------------+------------------------------------+-------------+
   | HAM 435          | 70 cm                   | 13                               | 13                                 |             |
   +------------------+-------------------------+----------------------------------+------------------------------------+-------------+
   | Wideband 1000    | 1 – 1000 MHz            | 0                                | 0                                  |             |
   +------------------+-------------------------+----------------------------------+------------------------------------+-------------+
   | HAM 1280         | 23 cm                   | 5                                | 5                                  |             |
   +------------------+-------------------------+----------------------------------+------------------------------------+-------------+
   | HAM 2400         | 13 cm                   | 10                               | -10                                |             |
   +------------------+-------------------------+----------------------------------+------------------------------------+-------------+
   | HAM 3500         | 9 cm                    | 5                                | -10                                |             |
   +------------------+-------------------------+----------------------------------+------------------------------------+-------------+
   | Wideband 4000    | 1 – 4 GHz               | 5                                | 5                                  |             |
   +------------------+-------------------------+----------------------------------+------------------------------------+-------------+
   | Cellular Band 1  | LTE Band 1              | 10                               | 10                                 |             |
   +------------------+-------------------------+----------------------------------+------------------------------------+-------------+
   | Cellular Band 2  | LTE Band 2/             | 10                               | 10                                 |             |
   |                  | PCS-1900                |                                  |                                    |             |
   +------------------+-------------------------+----------------------------------+------------------------------------+-------------+
   | Cellular Band 3  | LTE Band 3/             | 10                               | 10                                 |             |
   |                  | DCS-1800                |                                  |                                    |             |
   +------------------+-------------------------+----------------------------------+------------------------------------+-------------+
   | Cellular Band 7  | LTE Band 7              | 10                               | 10                                 |             |
   +------------------+-------------------------+----------------------------------+------------------------------------+-------------+
   | Cellular Band 38 | LTE Band 38             | 10                               | 10                                 |             |
   +------------------+-------------------------+----------------------------------+------------------------------------+-------------+

Digital Interface
=================

I2C, USB 2.0

Power Supply
============

.. list-table::
   :header-rows: 1
   
   * - Connector
     - Description
     - Max. recommended value
   * - J9
     - External 12 V connection – GND (PINs 1, 3), 12 V (PIN 2)
     - 14 V
   * - J10
     - External 5 V connection – GND (PINs 1, 3), 5 V (PIN 2)
     - 5.5 V
   * - J11
     - 5 V source selection:
       
       5 V is obtained from DC-DC connector supplied from external 12 V (PIN connection 1-2, jumper position – right);
       
       5 V is obtained from USB (PIN connection 3-4, jumper position – center);
       
       5 V is obtained from external 5 V supply unit (PIN connection 5-6, jumper position – left).
     - 
   * - J23
     - External 12 V connection
     - 14 V

Environmental
=============

.. list-table:: 
   :header-rows: 1
   :stub-columns: 1

   * - Parameter
     - Value
     - Notes
   * - Operating Temperature
     - -20 °C to +70 °C
     - Commercial-grade
   * - Storage Temperature
     - -40 °C to +85 °C
     - N/A
   * - Operating Humidity
     - 10% to 90% RH  
     - Non-condensing

Mechanical
==========

Board size 125.12mm x 162.51mm and weight 260g

Features
********

Devices
=======
* Cellular transmit power amplifiers:
 
  * TQP9421 (bands: 1, 2, 3) 
  * QPA9421 (bands: 7, 38) 
  
* Cellular receive low noise amplifier TQP3M9037
* Wideband transmit amplifiers:
  
  * RD01MUS2B (1 - 1000 MHz)
  * MMZ38333 (1000 - 4000 MHz)

* HAM transmit power amplifiers:

  * RD16HHF1 (30 MHz, 50 - 70 MHZ)
  * AFT09MS007NT1 (145 MHz, 225 MHz , 435 MHz)
  * RFM04U6P (915 MHz)
  * RD01MUS2B (1280 MHz)
  * QPA9426 (2400 MHz)

* Wideband/HAM receive low noise amplifiers:
  
  * GALI-74+ (up to 1000 MHz)
  * TQP3M9008 (up to 4000 MHz)

* ATMEGA328P-AU	Microcontroller
* FT232RL	USB controller

Integrated filtering and switching
==================================

* Cellular bands filter bank
* HAM low pass filter bank
* AM/FM Notch filter
* Integrated ferrite core output matching network with option to bypass it

Integrated SWR meter
====================

* Transmitted cellular signal power measurements
* External RF signal direct and reflected power measurements
* Possibility to correct calculated values.

General user inputs/outputs
===========================

* 3x Headers with GPIOs, I2C, ADC input and controls for external relays
* 4x general purpose LEDs

Connectors
===========

* USB Mini-B socket
* ICSP header for MCU SPI
* 2-pin and 4-pin FAN headers (5V default or 3.3V or VCC_INT voltage)
* 7x SMAs for RF front-end:
  
  * 2x for SDR RF (RX and TX) 
  * 2x for external antennas (TDD)
  * 1x for TX output
  * 2x for SWR measurements operation
  
Purchasing
**********

Please see the  `Lime Micro website`_ for purchasing options.

Regulatory
**********

RoHS
====

This product is RoHS compliant and does not contain hazardous substances as defined by Directive 2011/65/EU.

WEEE
====

This product must be disposed of properly according to local regulations. Do not dispose of with general household waste.

RF Transmission Notice
======================

.. warning::
   Operating RF transmitting equipment may require appropriate licensing. Users are responsible for ensuring compliance with local regulations. Unauthorised transmission may result in legal penalties.

.. _Lime Micro Website: https://limemicro.com/sdr/limerfe/

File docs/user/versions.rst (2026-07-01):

Board Versions
##############

There are currently two versions of the LimeRFE board: v1.0 and v1.31. 

v1.0 and v1.31 boards should be treated the same in terms of hardware functionality and software support. 

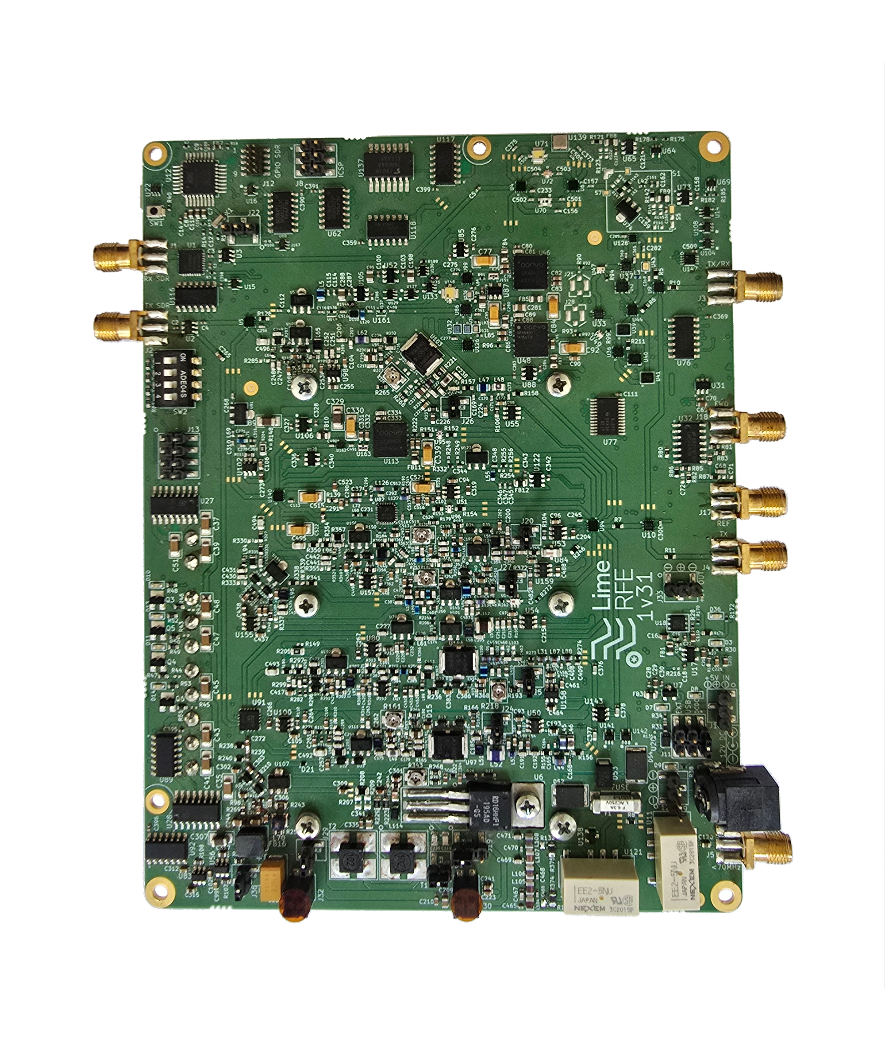
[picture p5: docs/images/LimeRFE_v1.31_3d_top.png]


  Figure 1: LimeRFE v1.31 board top view



  Figure 2: LimeRFE v1.0 board top view

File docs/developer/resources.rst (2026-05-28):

Resources
#########

Please refer to the following projects for the PCB design and manufacturing files and host software for LimeRFE:

* `Hardware Design`_ (Altium project and Gerbers etc.)
* :external+suite:ref:`Classic Lime Suite <index:introduction>` (host driver, plug-ins and engineering GUI)

.. _Hardware Design: https://github.com/myriadrf/LimeRFE

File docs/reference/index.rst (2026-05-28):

Hardware Reference
##################

The LimeRFE Hardware Reference manual is organised into separate sections for each board revision. 

Please ensure to select the correct version for your hardware and see the changelog for details of changes between revisions.

.. toctree::
   :maxdepth: 1

   v1.31 <v1.31/index>
   v1.0 <v1.0/index>
   changelog

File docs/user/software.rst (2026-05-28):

Software
########

Installing
**********

LimeRFE is supported by the :external+suite:ref:`Classic Lime Suite software <index:introduction>`, which provides drivers, command line utilities, plug-ins for popular ecosystem applications, and a graphical user interface (GUI) application for advanced engineering/debugging tasks.

.. warning::
   LimeRFE is not supported by LimeSuite NG

For a guide to getting up and running with Lime Suite, please refer to the :external+quickstart:ref:`SDR Quick Start <index:introduction>`.

Basic Setup
***********

1. Open Lime Suite GUI and then go to Modules/LimeRFE, Figure 6. 

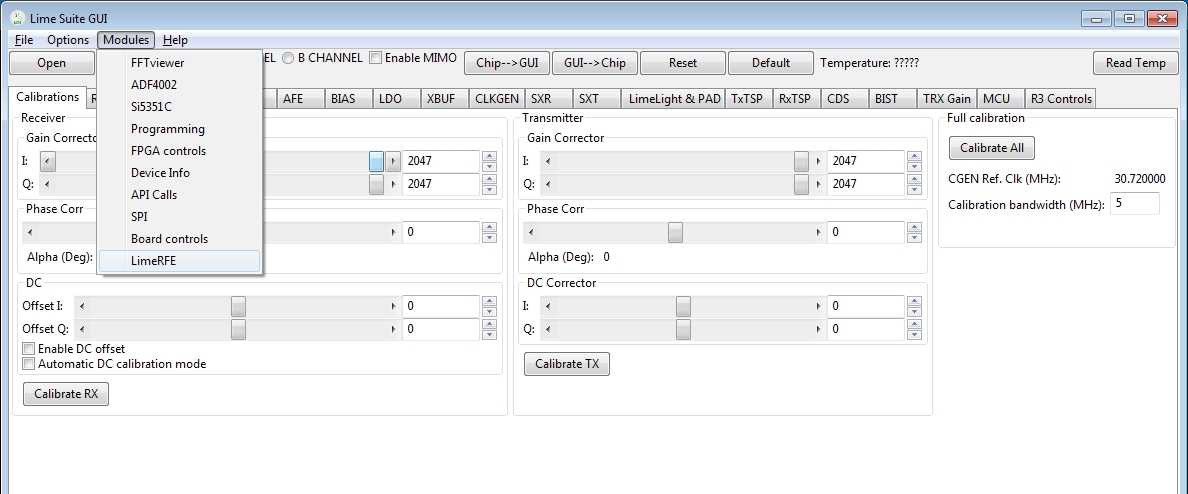
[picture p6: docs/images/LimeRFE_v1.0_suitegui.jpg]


  Figure 4: Lime Suite GUI window

2. LimeRFE Controls window should appear, Figure 7. This window consists of several panels: Communication, Configuration, Synchronize, RX Channel, TX Channel, Mode, SWR (to display this pannel go to View/Power Meter) and Message Display panel.

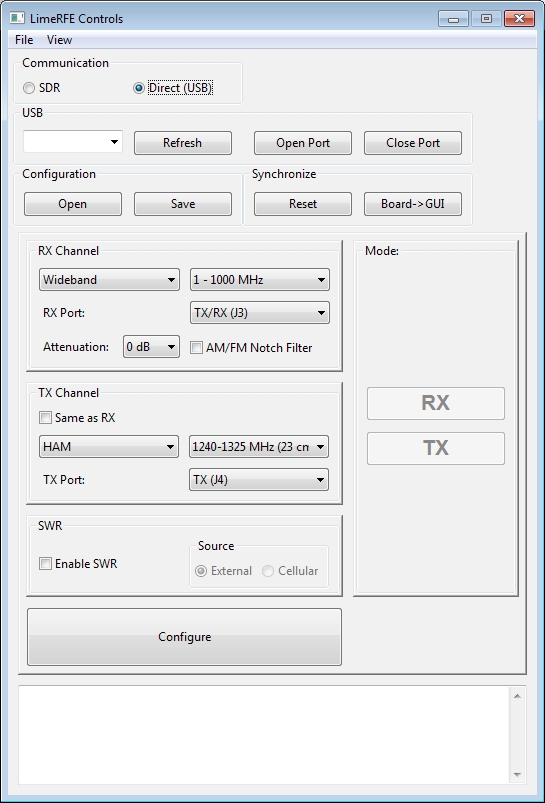
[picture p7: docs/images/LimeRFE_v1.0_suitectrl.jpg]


  Figure 5: LimeRFE Controls window (To display SWR pannel go to View/Power Meter)

3. In Communication panels, chose one of two possible options, SDR (this is standard I2C communication) or USB. 
   Keep in mind that for SDR (I2C) communication, an additional LimeSDR board must be connected. For SDR (I2C), a default LimeRFE board address is 0x51. If any other device on SDR (I2C) bus has the same address one of these two devices should change its address. LimeRFE address can be changed in its firmware. After connection the board on I2C bus, button Open Port enables communication. Button Close Port terminates SDR (I2C) communication.
   For  USB communication an appropriate COM port should be chosen. In USB panel, by clicking Refresh button, LimeRFE Controls software will automatically display available COM ports. Also, all available COM ports (under Windows OS) can be checked in the Windows Device Manager tool.

4. From a drop menu select appropriate COM port and click Open Port button to open communication between the LimeRFE board and PC. Text message in Message Display panel will be shown after a successful port opening. 
5. In Configuration panel, current configuration can be saved into the `*`.ini file (Save button) and previously saved configuration can be loaded from the `*`.ini file (Open button).
6. In Synchronize panel, any current configuration can be changed to default, by clicking Reset button. Button Board→GUI is used to sinhronize Lime RFE Controls  software parameters with current board configuration.
7. In RX Channel panel, in Type sub-panel there are three different options (in Figure 7 an option “Wideband” is shown) . 
   
   Depending of selected type, different Channel/Band options will appear (in Figure 7 an option “1 – 1000 MHz” is shown). 

   The third sub-panel shows selected input port for receiver mode (in Figure 7 an option “TX/RX (J3)” is shown). RX signal get out from the board at connector J1.

   All possible states are given in Table 3 bellow. 

   In the same panel, from Attenuation drop menu, attenuation level can be changed for signal in receive mode. Given attenuation values are: 0, 2, 4, 6, 8, 10, 12 and 14 dB (in Figure 7, 0 dB is selected attenuation level).

   In the same panel, AM/FM Notch filter can be enabled or bypassed in check in box. (in Figure 7 this AM/FM Notch filter has been bypassed, box is not checked). 

   Keep in mind that after choosing one of options, button Configure must be pressed to apply all changes in configuration.
8. In TX Channel panel, in Type sub-panel there are three different options (in Figure 7 an option “HAM” is shown). 

   Depending of selected type, different Channel/Band options will appear (in Figure 7 an option “1240 – 1325 MHz” is shown). 

   The third sub-panel shows selected input port for receiver mode (in Figure 7 an option “TX (J4)” is shown). TX signal get in into the board at connector J2.

   All possible states are given in Table 3, bellow. 

   In the same panel, check in box same as RX can be checked. If it is checked than Type and Channel/Band options will be the same as it was chosen in RX menu, but TX must be selected manually.

   Keep in mind that after choosing one of options, button Configure must be pressed to apply all changes in configuration.
9. In Mode panel the board can be configured to operates in RX or TX mode, but for some bands it can be in both modes at the same time or both modes turned off at the same time. All possible states are given in table bellow.

.. table:: Table 3. All possible states of the LimeSDR board (Type, Band/Channel, Rx and Tx connectors, Modes)

   +----------+------------------+-------------------------+-------------------------+---------------------+
   | **Type** | **Channel/Band** | **RX Port**             | **TX port**             | **Mode**            |
   +==========+==================+=========================+=========================+=====================+
   | Wideband | 1 – 1000 MHz     | TX/RX (J3)              | TX/RX (J3)              | None, RX, TX        |
   |          |                  |                         +-------------------------+---------------------+
   |          |                  |                         | TX (J4)                 | None, RX, TX, RX&TX |
   |          |                  +-------------------------+-------------------------+---------------------+
   |          |                  | TX to 30 MHz TX/RX (J5) | TX/RX (J3)              | None, RX, TX, RX&TX |
   |          |                  |                         +-------------------------+---------------------+
   |          |                  |                         | TX (J4)                 | None, RX, TX, RX&TX |
   |          +------------------+-------------------------+-------------------------+---------------------+
   |          | 1000 – 4000 MHz  | TX/RX (J3)              | TX/RX (J3)              | None, RX, TX        |
   |          |                  |                         +-------------------------+---------------------+
   |          |                  |                         | TX (J4)                 | None, RX, TX, RX&TX |
   +----------+------------------+-------------------------+-------------------------+---------------------+
   | HAM      | 30 MHz (HF)      | TX/RX (J3)              | TX to 30 MHz TX/RX (J5) | None, RX, TX, RX&TX |
   |          |                  +-------------------------+                         +---------------------+
   |          |                  | TX to 30 MHz TX/RX (J5) |                         | None, RX, TX        |
   |          +------------------+-------------------------+-------------------------+---------------------+
   |          | 50 – 70 MHz      | TX/RX (J3)              | TX to 30 MHz TX/RX (J5) | None, RX, TX, RX&TX |
   |          |                  +-------------------------+                         +---------------------+
   |          | (6 & 4m)         | TX to 30 MHz TX/RX (J5) |                         | None, RX, TX        |
   |          +------------------+-------------------------+-------------------------+---------------------+
   |          | 144 – 146 MHz    | TX/RX (J3)              | TX/RX (J3)              | None, RX, TX        |
   |          |                  |                         +-------------------------+---------------------+
   |          | (2m)             |                         | TX (J4)                 | None, RX, TX, RX&TX |
   |          |                  +-------------------------+-------------------------+---------------------+
   |          |                  | TX to 30 MHz TX/RX (J5) | TX/RX (J3)              | None, RX, TX, RX&TX |
   |          |                  |                         +-------------------------+---------------------+
   |          |                  |                         | TX (J4)                 | None, RX, TX, RX&TX |
   |          +------------------+-------------------------+-------------------------+---------------------+
   |          | 220 – 225 MHz    | TX to 30 MHz TX/RX (J5) | TX/RX (J3)              | None, RX, TX, RX&TX |
   |          |                  |                         +-------------------------+---------------------+
   |          | (1.25m)          |                         | TX (J4)                 | None, RX, TX, RX&TX |
   |          |                  +-------------------------+-------------------------+---------------------+
   |          |                  | TX/RX (J3)              | TX/RX (J3)              | None, RX, TX        |
   |          |                  |                         +-------------------------+---------------------+
   |          |                  |                         | TX (J4)                 | None, RX, TX, RX&TX |
   |          +------------------+-------------------------+-------------------------+---------------------+
   |          | 430 – 440 MHz    | TX to 30 MHz TX/RX (J5) | TX/RX (J3)              | None, RX, TX, RX&TX |
   |          |                  |                         +-------------------------+---------------------+
   |          | (70cm)           |                         | TX (J4)                 | None, RX, TX, RX&TX |
   |          |                  +-------------------------+-------------------------+---------------------+
   |          |                  | TX/RX (J3)              | TX/RX (J3)              | None, RX, TX        |
   |          |                  |                         +-------------------------+---------------------+
   |          |                  |                         | TX (J4)                 | None, RX, TX, RX&TX |
   |          +------------------+-------------------------+-------------------------+---------------------+
   |          | 902 – 928 MHz    | TX/RX (J3)              | TX/RX (J3)              | None, RX, TX        |
   |          |                  |                         +-------------------------+---------------------+
   |          | (33cm)           |                         | TX (J4)                 | None, RX, TX, RX&TX |
   |          +------------------+-------------------------+-------------------------+---------------------+
   |          | 1240 – 1325 MHz  | TX/RX (J3)              | TX/RX (J3)              | None, RX, TX        |
   |          |                  |                         +-------------------------+---------------------+
   |          | (23cm)           |                         | TX (J4)                 | None, RX, TX, RX&TX |
   |          +------------------+-------------------------+-------------------------+---------------------+
   |          | 2300 – 2450 MHz  | TX/RX (J3)              | TX/RX (J3)              | None, RX, TX        |
   |          |                  |                         +-------------------------+---------------------+
   |          | (13cm)           |                         | TX (J4)                 | None, RX, TX, RX&TX |
   |          +------------------+-------------------------+-------------------------+---------------------+
   |          | 3300 – 3500 MHz  | TX/RX (J3)              | TX/RX (J3)              | None, RX, TX        |
   |          |                  |                         +-------------------------+---------------------+
   |          |                  |                         | TX (J4)                 | None, RX, TX, RX&TX |
   +----------+------------------+-------------------------+-------------------------+---------------------+
   | Cellular | Band 1           | TX/RX (J3)              | TX/RX (J3)              | RX&TX               |
   |          +------------------+-------------------------+-------------------------+---------------------+
   |          | Band 2/          | TX/RX (J3)              | TX/RX (J3)              | RX&TX               |
   |          |                  |                         |                         |                     |
   |          | PCS – 1900       |                         |                         |                     |
   |          +------------------+-------------------------+-------------------------+---------------------+
   |          | Band3/           | TX/RX (J3)              | TX/RX (J3)              | RX&TX               |
   |          |                  |                         |                         |                     |
   |          | DCS – 1800       |                         |                         |                     |
   |          +------------------+-------------------------+-------------------------+---------------------+
   |          | Band 7           | TX/RX (J3)              | TX/RX (J3)              | RX&TX               |
   |          +------------------+-------------------------+-------------------------+---------------------+
   |          | Band 38          | TX/RX (J3)              | TX/RX (J3)              | RX, TX              |
   +----------+------------------+-------------------------+-------------------------+---------------------+

10. When the LimeRFE Controls GUI is opened, its default view doesn’t show SWR panel. To display SWR panel go to View/Power Meter. 
      
    In its basic configuration, SWR panel gives signal powers measured at SMA connectors J17 and J18. Source sub-panel gives two options. Cellular option enables ability to measure forward power at the output of currently active power amplifier, from cellular block of the board. In External option, RF output of LimeRFE board (conectors J3, J4 or J5) can be connected to antenna or other amplifier device through a directional coupler. Forward and reverse ports of the directional coupler are connected back to LimeSDR board to connectors J18 (forward) and J17 (reverse), where RF powers are measured and displayed in the Power Meter panel.

    It is possible to correct the values by a constant coefficient, by performing calibration. Namely, if the exact value for the power and/or reflection coefficient (gamma) is known, it can be entered in the fields Calibration Power and Calibration Gamma. By clicking Calibrate button, coefficients are calculated, and will be used in subsequent calculations. These coefficients are included in the configuration file, and can be saved/loaded.
11. Message Display panel prints all important information related to the communication with the LimeRFE board (displays info massages if port is opened, closed, if the board is configured for specific band, if there was an error in communication…)
    
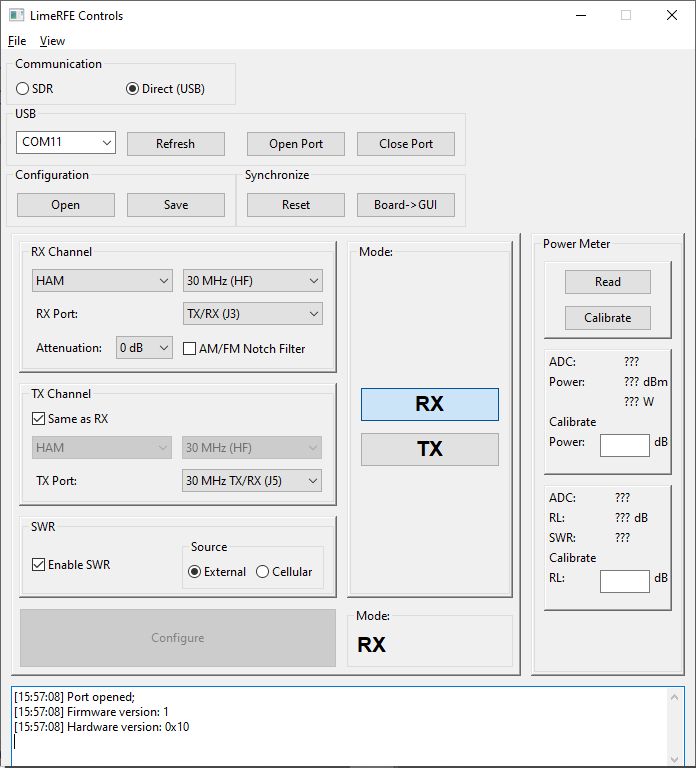
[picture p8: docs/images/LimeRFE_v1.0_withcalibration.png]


  Figure 6: LimeRFE Controls window with opened SWR pannel and enabled SWR

.. note::
   It is important to keep the impedance controlled on all output connectors (J3, J4, and J5, see the next Section for detailed description of the connectors). In the very unlikely situations that the impedance on those ports is very reflective, the power amplifier oscillations might occur, which may damage the board. Hence, it is recommended to connect  50 Ω matched loads/sources, and to terminate the unused ports with 50 Ω terminations.

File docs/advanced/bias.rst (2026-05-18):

PA Biasing
##########

All LimeRFE boards arrive in already preset power amplifier bias currents. Some deviation in bias currents might be possible due to different ambient temperature, some minor changes during the transport, etc.

However, it is possible to change bias current of four power amplifiers on LimeRFE board. The user must pay attention for any further change of these values and do it on his/her own responsibility. The list of these amplifiers with their default bias currents is given in Table 8.

.. list-table:: Default power amplifier bias currents which can be changed
   :header-rows: 1

   * - Channel/Band
     - Bias current
     - Jumper
     - Trimmer
   * - 30 MHz (HF) and 50 – 70 MHz (6 & 4 m)
     - 500 mA
     - J36 *
     - R343
   * - 144 – 146 MHz (2 m)
     - 200 mA
     - J24
     - R161
   * - 220 – 225 MHz (1.25 m)
     - 200 mA
     - J25
     - R218
   * - 430 – 440 MHz (70 cm)
     - 200 mA
     - J26
     - R226
   * - 902 – 928 MHz (33 cm)
     - 100 mA
     - J27
     - R253
   * - 1240 – 1325 MHz (23 cm)
     - 40 mA
     - J20
     - R176

`*` Jumpers on connectors J29, J31 and J19 (J32 and J30) must be properly placed (for detail description about all these jumpers look at in Table 5)

Figure 5 shows possitions of all connectors and trimmers necessary to change power amplifier bias currents.

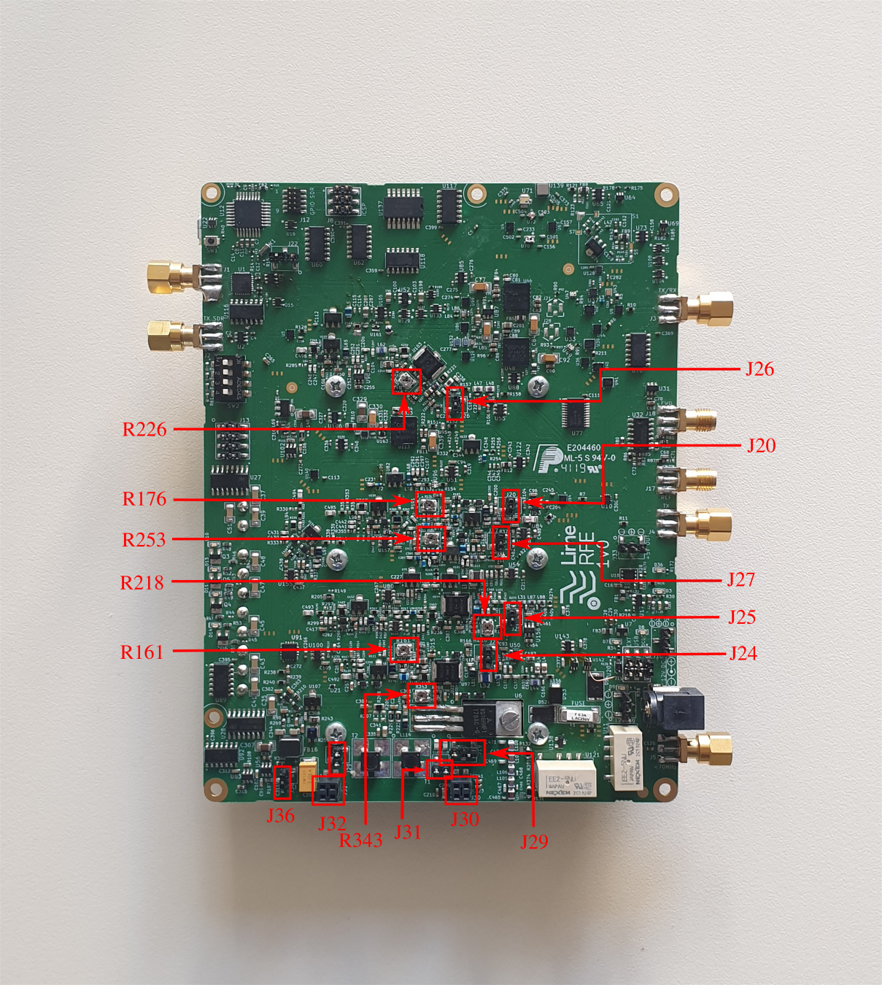
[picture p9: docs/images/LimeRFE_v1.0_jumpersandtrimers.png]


  Figure 5: Positions of all necessary connectors and trimmers for bias currents changes

HAM 30 MHz (HF) and 50-70 MHz (6 & 4m)
**************************************

1. Choose external DC power supply of 12 V and 5 V from on board DC-DC convertor by connecting pin 1 and pin 2 of connector J11 on the board (jumper position – right). Connect external DC supply unit to J9, but do not turn on 12 V from DC supply unit.
2. Terminate J1, J2, J3 and J4 SMA connectors with 50 Ohm terminations
3. J5 SMA connector (30 MHz out) connect to termination or high attenuation (> 10 dB) capable to endure  10 W of RF power (in our setup we used 40 dB / 10 W attenuator)
4. Connect USB cable from computer to the LimeRFE board
5. Before external DC supply is turned on, turn around all of trimmers, which are not already set, in counter clockwise directions (R161, R176, R218, R226, R253, R343).
6. Connect J36 connector pins through ammeter (set 10 A range in ammeter)
7. Also, jumpers on connectors J29, J31 and J19 (J32 and J30) must be properly placed (for all these jumpers look at Table 5 for more detail description)
8. Turn on 12 V from external DC supply unit (setup maximum current of 800 mA in external DC supply unit if desired bias current is 500 mA)
9. In software, setup the board for HAM, 30 MHz (HF) band.
10. Turn off Receiver/Turn on Transmitter mode.
11. Turn around trimmer R343 in clockwise direction until ammeter shows 0.5 A

HAM 144-146 MHz (2 m)
*********************

1. Choose external DC power supply of 12 V and 5 V from on board DC-DC convertor by connecting pin 1 and pin 2 of connector J11 on the board  (jumper position – right). Connect external DC supply unit to J9, but do not turn on 12 V from DC supply unit.
2. Terminate J1, J2, J3 and J5 SMA connectors with 50 Ohm terminations
3. J4 SMA connector connect to termination or high attenuation (> 10 dB) capable to endure 5 W of RF power (in our setup we used 40 dB / 50 W attenuator)
4. Connect USB cable from computer to the LimeRFE board
5. Before external DC supply is turned on, turn around all of trimmers, which are not already set, in counter clockwise directions (R161, R176, R218, R226, R253, R343) 
6. Connect J24 connector pins through ammeter (set 10 A range in ammeter)
7. Turn on 12 V from external DC supply unit (setup maximum current of 400 mA in external DC supply unit if desired bias current is 200 mA)
8. In software, setup the board for HAM, 144 – 146 MHz (2 m) band, with TX (J4).
9. Turn off Receiver and Turn on Transmitter
10. Turn around trimmer R161 in clockwise direction until ammeter shows 0.2 A

HAM 220-225 MHz (1.25 m)
************************

1. Choose external DC power supply of 12 V and 5 V from on board DC-DC convertor by connecting pin 1 and pin 2 of connector J11 on the board  (jumper position – right). Connect external DC supply unit to J9, but do not turn on 12 V from DC supply unit.
2. Terminate J1, J2, J3 and J5 SMA connectors with 50 Ohm terminations
3. J4 SMA connector connect to termination or high attenuation (> 10 dB) capable to endure 5 W of RF power (in our setup we used 40 dB / 50 W attenuator)
4. Connect USB cable from computer to the LimeRFE board
5. Before external DC supply is turned on, turn around all of trimmers, which are not already set, in counter clockwise directions (R161, R176, R218, R226, R253, R343) 
6. Connect J25 connector pins through ammeter (set 10 A range in ammeter)
7. Turn on 12 V from external DC supply unit (setup maximum current of 400 mA in external DC supply unit if desired bias current is 200 mA)
8. In software, setup the board for HAM, 220 – 225 MHz (1.25 m) band, with TX Connector (J4).
9. Turn off Receiver and Turn on Transmitter
10. Turn around trimmer R218 in clockwise direction until ammeter shows 0.2 A

HAM 430-440 MHz (70 cm)
***********************

1. Choose external DC power supply of 12 V and 5 V from on board DC-DC convertor by connecting pin 1 and pin 2 of connector J11 on the board (jumper position – right). Connect external DC supply unit to J9, but do not turn on 12 V from DC supply unit.
2. Terminate J1, J2, J3 and J5 SMA connectors with 50 Ohm terminations.
3. J4 SMA connector connect to termination or high attenuation (> 10 dB) capable to endure 5 W of RF power (in our setup we used 40 dB / 50 W attenuator).
4. Connect USB cable from computer to the LimeRFE board.
5. Before external DC supply is turned on, turn around all of trimmers, which are not already set, in counter clockwise directions (R161, R176, R218, R226, R253, R343).
6. Connect J26 connector pins through ammeter (set 10 A range in ammeter).
7. Turn on 12 V from external DC supply unit (setup maximum current of 400 mA in external DC supply unit if desired bias current is 200mA).
8. In software, setup the board for HAM, 430 – 440 MHz (70 cm) band, with TX Connector (J4).
9. Turn off Receiver and Turn on Transmitter.
10. Turn around trimmer R226 in clockwise direction until ammeter shows 0.2 A.
  
HAM 902-928 MHz (33 cm)
***********************
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

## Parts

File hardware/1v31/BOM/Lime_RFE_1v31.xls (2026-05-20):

Lime_RFE_1v31
Component | QTY | Reference | Footprint | Supplier | Supplier Part Number | Manufacturer | Manu Part Number | Description | Assemble | Comment
47nF | 14 | C1, C2, C3, C4, C5, C6, C59, C61, C62, C63, C64, C65, C66, C117 | SMD0402 | Mouser | 81-GCM155R71H473KE2D | Murata Electronics | GCM155R71H473KE02D | Multilayer Ceramic Capacitors MLCC - SMD/SMT 0402 0.047uF 50volts X7R 10%
1uF | 33 | C7, C10, C11, C13, C33, C34, C36, C38, C40, C42, C44, C46, C49, C50, C193, C203, C204, C215, C226, C255, C266, C267, C273, C315, C317, C319, C427, C438, C449, C450, C455, C464, C488 | SMD0603 | Mouser | 963-TMK107BJ105KA-T | Taiyo Yuden | TMK107BJ105KA-T | Multilayer Ceramic Capacitors MLCC - SMD/SMT 1uF 25V X5R +/-10% 0603 Gen Purp
4.7uF | 1 | C8 | SMD0402 | Mouser | 81-GRM155R60J475ME8D | Murata Electronics | GRM155R60J475ME87D | Multilayer Ceramic Capacitors MLCC - SMD/SMT 0402 4.7uF 6.3volts *Derate Voltage/Temp
100nF | 32 | C9, C12, C14, C27, C28, C107, C111, C121, C123, C125, C158, C160, C161, C163, C189, C232, C316, C342, C343, C345, C359, C362, C369, C390, C391, C392, C394, C395, C396, C398, C399, C509 | SMD0402 | Mouser | 81-GRM155R71C104KA8J | Murata Electronics | GRM155R71C104KA88J | Multilayer Ceramic Capacitors MLCC - SMD/SMT 0.1uF 16 volts 10%
1uF | 3 | C15, C18, C30 | SMD0402 | Mouser | 603-CC402ZRY5V5BB105 | Yageo | CC0402ZRY5V5BB105 | Multilayer Ceramic Capacitors MLCC - SMD/SMT 1.0uF 6.3V Y5V -20/+80%
10uF | 11 | C16, C20, C21, C23, C25, C26, C29, C69, C110, C507, C508 | SMD0603 | Mouser | 81-GRM188R61E106KA3J | Murata Electronics | GRM188R61E106KA73J | Multilayer Ceramic Capacitors MLCC - SMD/SMT
2.2nF | 3 | C17, C24, C393 | SMD0402 | Mouser | 81-GRM155R71E222KA1D | Murata Electronics | GRM155R71E222KA01D | Multilayer Ceramic Capacitors MLCC - SMD/SMT RECOMMENDED ALT 81-GRM033R71E222KA2D
0.1uF | 20 | C19, C22, C70, C73, C75, C76, C100, C103, C275, C276, C279, C280, C283, C284, C286, C287, C327, C328, C336, C340 | SMD0402 | Mouser | 81-GRM155R71C104JA8J | Murata Electronics | GRM155R71C104JA88J | Multilayer Ceramic Capacitors MLCC - SMD/SMT .1uF 16Volts 5%
3.9nF | 1 | C31 | SMD0402 | Mouser | 581-04025C392JAT2A | AVX | 04025C392JAT2A | Multilayer Ceramic Capacitors MLCC - SMD/SMT 50V 3900pF X7R 0402 5%
100uF | 1 | C32 | EEE-HC1E101P | Mouser | 667-EEE-1EA101UP | Panasonic | EEE-1EA101UP | Aluminium Electrolytic Capacitors - SMD 100UF 25V VS SMD
100nF | 9 | C35, C37, C39, C41, C43, C45, C47, C48, C51 | SMD1206 | Mouser | 80-C1206C104K5R7800 | KEMET | C1206C104K5RAC7800 | MLCC - SMD/SMT 50V 0.1uF X7R 1206 10%
NF | 8 | C52, C53, C54, C55, C56, C57, C71, C72 | SMD0603 |  |  |  |  |  | NF
1uF | 17 | C58, C60, C74, C118, C119, C122, C124, C126, C141, C142, C143, C144, C358, C497, C498, C499, C500 | SMD0402 | Mouser | 81-GCM155C71A105KE8D | Murata Electronics | GCM155C71A105KE38D | Multilayer Ceramic Capacitors MLCC - SMD/SMT 0402 1uF 10volts X7S 10%
1nF | 2 | C67, C68 | SMD0603 | Mouser | 81-GRM1885C1H102JA1J | Murata | GRM1885C1H102JA01J | Multilayer Ceramic Capacitors MLCC - SMD/SMT 1000pF 50Volts 5%
10uF | 9 | C77, C84, C85, C92, C330, C339, C515, C521, C522 | SMD1206_TANTAL | Mouser | 80-T491A106K016 | Kemet | T491A106K016AT | Tantalum Capacitors - Solid SMD 16V 10uF 1206 10% ESR=3Ohms
0.1uF | 6 | C78, C83, C86, C91, C331, C338 | SMD0603 | Mouser | 81-GCM188R91E104JA7D | Murata Electronics | GCM188R91E104JA37D | Multilayer Ceramic Capacitors MLCC - SMD/SMT 0603 0.1uF 25volts X8R 5%
1nF | 6 | C79, C82, C87, C90, C332, C337 | SMD0603 | Mouser | 81-GCJ188R71H102KA1D | Murata | GCJ188R71H102KA01D | Multilayer Ceramic Capacitors MLCC - SMD/SMT 0603 50volts 1000pF X7R 10% Soft Term
0.01uF | 3 | C80, C88, C333 | SMD0402 | Mouser | 81-GRM155R71H103KA8D | Murata Electronics | GRM155R71H103KA88D | Multilayer Ceramic Capacitors MLCC - SMD/SMT 0402 0.01uF 50volts X7R 10%
100pF | 3 | C81, C89, C334 | SMD0603 | Mouser | 81-GCM1885C2A101FA6D | Murata Electronics | GCM1885C2A101FA16D | Multilayer Ceramic Capacitors MLCC - SMD/SMT 0603 100pF 100volts C0G 1%
1nF | 33 | C93, C94, C96, C97, C98, C99, C101, C102, C104, C105, C106, C187, C202, C213, C214, C224, C225, C228, C253, C264, C297, C311, C312, C425, C426, C436, C437, C447, C448, C458, C461, C482, C486 | SMD0603 | Mouser | 581-06035C102K | AVX | 06035C102KAT2A | Multilayer Ceramic Capacitors MLCC - SMD/SMT 50V 1nF X7R 0603 10%TOL
10uF | 4 | C95, C198, C278, C281 | SMD0805 | Mouser | 963-TMK212BBJ106KG-T | Taiyo Yuden | TMK212BBJ106KG-T | Multilayer Ceramic Capacitors MLCC - SMD/SMT 10uF 25V X5R +/-10% 0805 Gen Purp
100nF | 47 | C108, C109, C177, C180, C184, C194, C195, C199, C210, C216, C221, C223, C241, C242, C246, C250, C257, C261, C265, C272, C294, C299, C301, C302, C303, C304, C305, C308, C309, C313, C335, C383, C386, C388, C397, C402, C417, C418, C421, C428, C429, C432, C439, C440, C443, C454, C477 | SMD0603 | Mouser | 80-C0603C104M5R | KEMET | C0603C104M5RACTU | Multilayer Ceramic Capacitors MLCC - SMD/SMT 50V 0.1uF 0603 X7R 20%
1nF | 6 | C112, C114, C116, C282, C285, C360 | SMD0402 | Mouser | 81-GCM1555C1H102JA6J | Murata Electronics | GCM1555C1H102JA16J | Multilayer Ceramic Capacitors MLCC - SMD/SMT 0402 1000pF 50volts C0G 5%
100pF | 21 | C113, C233, C245, C256, C274, C277, C300, C318, C361, C363, C364, C365, C368, C489, C490, C491, C510, C511, C370, C115, C346 | SMD0402 | Mouser | 81-GCM1555C1H101JA6D | Murata Electronics | GCM1555C1H101JA16D | Multilayer Ceramic Capacitors MLCC - SMD/SMT 0402 100pF 50volts C0G 5%
1uF | 1 | C120 | SMD0603 | Mouser | 603-CC603KRX7R9BB105 | Yageo | CC0603KRX7R9BB105 | Multilayer Ceramic Capacitors MLCC - SMD/SMT 1uF 10% 50V
15pF | 2 | C127, C133 | SMD0402 | Mouser | 81-GJM1555C1H150FB1D | Murata | GJM1555C1H150FB01D | Multilayer Ceramic Capacitors MLCC - SMD/SMT 0402 15pF 50Volts C0G 1%
56pF | 2 | C128, C132 | SMD0402 | Mouser | 81-GRM1555C1H560GA1D | Murata | GRM1555C1H560GA01D | Multilayer Ceramic Capacitors MLCC - SMD/SMT 0402 56pF 50volts C0G 2%
27pF | 2 | C129, C131 | SMD0402 | Mouser | 581-04025U270GAT2A | Murata | 04025U270GAT2A | Multilayer Ceramic Capacitors MLCC - SMD/SMT 50V 27pF C0G 0402 2% Tol
51pF | 1 | C130 | SMD0402 | Mouser | 81-GRM1555C1H510JA1D | Murata | GRM1555C1H510JA01D | Multilayer Ceramic Capacitors MLCC - SMD/SMT 0402 51pF 50volts C0G 5%
2200pF | 1 | C134 | SMD0603 | Mouser | 81-GRM1885C1H222GA1D | Murata | GRM1885C1H222GA01D | Multilayer Ceramic Capacitors MLCC - SMD/SMT 2200pF 50Volts 2%
4700pF | 1 | C135 | SMD0603 | Mouser | 81-GRM1887U1H472JA1D | Murata | GRM1887U1H472JA01D | Multilayer Ceramic Capacitors MLCC - SMD/SMT 0603 4700pF 50volts 5%
1000pF | 11 | C136, C138, C156, C157, C159, C501, C502, C503, C504, C505, C506 | SMD0402 | Mouser | 81-GRM1555C1H102GA1D | Murata | GRM1555C1H102GA01D | Multilayer Ceramic Capacitors MLCC - SMD/SMT 0.001uF 50Volts 2%
3300pF | 1 | C137 | SMD0402 | Mouser | 81-GRM155R71H332JA1D | Murata | GRM155R71H332JA01D | Multilayer Ceramic Capacitors MLCC - SMD/SMT 0402 50volts 3300pF X7R 5%
15000pF | 1 | C139 | SMD0603 | Mouser | 581-06035C153K | AVX Corporation | 06035C153KAT2A | Multilayer Ceramic Capacitors MLCC - SMD/SMT 50V .015uF X7R 0603 10%
1500pF | 8 | C140, C192, C306, C376, C377, C378, C451, C456 | SMD0603 | Mouser | 81-GRM1885C1H152JA01 | Murata | GRM1885C1H152JA01D | Multilayer Ceramic Capacitors MLCC - SMD/SMT 0603 1500pF 50volts C0G 5%
6.4pF | 1 | C145 | SMD0402 | Mouser | 81-GRM1555C1H6R4BA1D | Murata | GRM1555C1H6R4BA01D | Multilayer Ceramic Capacitors MLCC - SMD/SMT 0402 6.4pF 50volts C0G +/-0.1pF
33pF | 2 | C146, C254 | SMD0402 | Mouser | 81-GCM1555C1H330FA6J | Murata Electronics | GCM1555C1H330FA16J | Multilayer Ceramic Capacitors MLCC - SMD/SMT 0402 33pF 50volts C0G 1%
120pF | 1 | C147 | SMD0402 | Mouser | 81-GCM1555C1H121FA6D | Murata Electronics | GCM1555C1H121FA16D | Multilayer Ceramic Capacitors MLCC - SMD/SMT 0402 120pF 50volts C0G 1%
3.6pF | 3 | C148, C151, C167 | SMD0402 | Mouser | 81-GJM1555C1H3R6WB1D | Murata | GJM1555C1H3R6WB01D | Multilayer Ceramic Capacitors MLCC - SMD/SMT 0402 3.6pF 50Volts C0G +/-0.05pF
43pF | 1 | C149 | SMD0402 | Mouser | 81-GRM1555C1H430GA1D | Murata | GRM1555C1H430GA01D | Multilayer Ceramic Capacitors MLCC - SMD/SMT 0402 43pF 50volts C0G 2%
22pF | 2 | C150, C353 | SMD0402 | Mouser | 81-GCM1555C1H220GA6D | Murata | GCM1555C1H220GA16D | Multilayer Ceramic Capacitors MLCC - SMD/SMT 0402 22pF 50volts C0G 2%
18pF | 1 | C152 | SMD0402 | Mouser | 81-GRM1555C1H180JA1D | Murata Electronics | GRM1555C1H180JA01D | Multilayer Ceramic Capacitors MLCC - SMD/SMT RECOMMENDED ALT 81-GRM0335C1H180JA1D
6.7pF | 1 | C153 | SMD0402 | Mouser | 81-GRM1555C1H6R7DA1D | Murata Electronics | GRM1555C1H6R7DA01D | Multilayer Ceramic Capacitors MLCC - SMD/SMT 0402 6.7pF 50volts C0G
6.6pF | 1 | C154 | SMD0402 | Mouser | 81-GRM1555C1H6R6BA1D | Murata Electronics | GRM1555C1H6R6BA01D | Multilayer Ceramic Capacitors MLCC - SMD/SMT 0402 6.6pF 50volts C0G
33pF | 1 | C155 | SMD0402 | Mouser | 81-GRM1555C1H330GA1J | Murata | GRM1555C1H330GA01J | Multilayer Ceramic Capacitors MLCC - SMD/SMT 0402 33pF 50volts C0G 2%
30pF | 1 | C162 | SMD0402 | Mouser | 81-GJM1555C1H300FB1D | Murata Electronics North America | GJM1555C1H300FB01D | Multilayer Ceramic Capacitors MLCC - SMD/SMT
7pF | 1 | C164 | SMD0402 | Mouser | 81-GJM1555C1H7R0WB1D | Murata | GJM1555C1H7R0WB01D | Multilayer Ceramic Capacitors MLCC - SMD/SMT 0402 7.0pF 50Volts C0G +/-0.05pF
12pF | 2 | C165, C168 | SMD0402 | Mouser | 81-GCQ1555C1H120GB1D | Murata | GCQ1555C1H120GB01D | Multilayer Ceramic Capacitors MLCC - SMD/SMT 0402 50VDC 12pF 2% AEC-Q200
20pF | 1 | C166 | SMD0402 | Mouser | 81-GJM1555C1H200FB1D | Murata | GJM1555C1H200FB01D | Multilayer Ceramic Capacitors MLCC - SMD/SMT 0402 20pF 50Volts C0G 1%
3pF | 1 | C169 | SMD0402 | Mouser | 81-GJM1555C1H3R0BB01 | Murata | GJM1555C1H3R0BB01D | Multilayer Ceramic Capacitors MLCC - SMD/SMT 0402 3.0pF 50Volts C0G +/-0.1pF |  | basket
4.7pF | 2 | C170, C173 | SMD0402 | Mouser | 81-GJM1555C1H4R7CB1D | Murata | GJM1555C1H4R7CB01D | Multilayer Ceramic Capacitors MLCC - SMD/SMT 0402 4.7pF 50Volts C0G +/-0.25pF |  | basket
8pF | 1 | C171 | SMD0402 | Mouser | 81-GCM1555C1H8R0BA6D | Murata | GCM1555C1H8R0BA16D | Multilayer Ceramic Capacitors MLCC - SMD/SMT 0402 8.0pF 50volts C0G 0.1pF
1.5pF | 1 | C172 | SMD0402 | Mouser | 81-GJM1555C1H1R5CB01 | Murata | GJM1555C1H1R5CB01D | Multilayer Ceramic Capacitors MLCC - SMD/SMT 0402 1.5pF 50Volts C0G +/-0.25pF
100pF | 6 | C174, C205, C227, C229, C230, C234 | SMD0603 | Mouser | 81-GRM39C101J50J | Murata Electronics | GRM1885C1H101JA01J | Multilayer Ceramic Capacitors MLCC - SMD/SMT RECOMMENDED ALT 81-GRM0335C1H101JA1J
82pF | 3 | C175, C326, C471 | SMD0603 | Mouser | 81-GRM39C820J50 | Murata Electronics | GRM1885C1H820JA01D | Multilayer Ceramic Capacitors MLCC - SMD/SMT 0603 82pF 50volts C0G 5%
15pF | 7 | C176, C206, C207, C239, C240, C384, C401 | SMD0603 | Mouser | 80-C0603C150J5G | KEMET | C0603C150J5GACTU | Multilayer Ceramic Capacitors MLCC - SMD/SMT 50V 15pF 0603 C0G 0.05
10pF | 1 | C178 | SMD0603 | Mouser | 81-GRM185C1H100JA01J | Murata Electronics | GRM1885C1H100JA01J | Multilayer Ceramic Capacitors MLCC - SMD/SMT 0603 10pF 50volts C0G 5%
27pF | 15 | C179, C197, C201, C212, C238, C248, C252, C259, C263, C420, C424, C431, C435, C442, C446 | SMD0603 | Mouser | 80-C0603C270J5GAC | Kemet | C0603C270J5GAC | Multilayer Ceramic Capacitors MLCC - SMD/SMT 50V 27pF 0603 C0G 5%
100pF | 17 | C181, C185, C196, C200, C211, C218, C222, C247, C251, C258, C262, C419, C423, C430, C434, C441, C445 | SMD0603 | Mouser | 81-GRM1885C2A101JA01 | Murata Electronics | GRM1885C2A101JA01D | Multilayer Ceramic Capacitors MLCC - SMD/SMT RECOMMENDED ALT 81-GRM0335C2A101JA1D
470nF | 4 | C182, C186, C235, C237 | SMD0805 | Mouser | 963-UMK212B7474KG-T | Taiyo Yuden | UMK212B7474KG-T | MLCC-SMD/SMT 0805 50V 0.47uF 10% X7R
47pF | 6 | C183, C249, C260, C422, C433, C444 | SMD0603 | Mouser | 81-GRM1885C2A470JA1J | Murata Electronics | GRM1885C2A470JA01J | Multilayer Ceramic Capacitors MLCC - SMD/SMT 47pF 100Volts C0G 5%
68pF | 2 | C188, C191 | SMD0603 | Mouser | 81-GRM39C680J50 | Murata Electronics | GRM1885C1H680JA01D | Multilayer Ceramic Capacitors MLCC - SMD/SMT RECOMMENDED ALT 81-GRM0335C1H680JA1D
39pF | 1 | C190 | SMD0603 | Mouser | 81-GRM39C390J50 | Murata Electronics | GRM1885C1H390JA01D | Multilayer Ceramic Capacitors MLCC - SMD/SMT 0603 39pF 50volts C0G 5%
100uF | 1 | C208 | TAJE107M025SNJV | Mouser | 581-TAJE107M025SNJV | AVX | TAJE107M025SNJV | Tantalum Capacitors - Solid SMD 25V 100uF 20% 2917 ESR = .3 Ohms
1uF | 4 | C209, C244, C298, C341 | SMD0805 | Mouser | 77-VJ805Y105KXXTW1BC | Vishay / Vitramon | VJ0805Y105KXXTW1BC | Multilayer Ceramic Capacitors MLCC - SMD/SMT 1uF 25volts 10%
NF_100nF | 1 | C217 | SMD0603 | Mouser | 80-C0603C104M5R | KEMET | C0603C104M5RACTU | Multilayer Ceramic Capacitors MLCC - SMD/SMT 50V 0.1uF 0603 X7R 20% | NF
91pF | 2 | C219, C220 | SMD0805 | Mouser | 80-C0805C910K4HACTU | KEMET | C0805C910K4HACTU | Multilayer Ceramic Capacitors MLCC - SMD/SMT 16V 91pF X8R 0805 10%
5.6pF | 3 | C231, C512, C520 | SMD0402 | Mouser | 581-04023J5R6BBW | AVX | 04023J5R6BBWTR | Silicon RF Capacitors / Thin Film 25V 5.6pF .1pFTol ThinFilm 0402
47pF | 1 | C236 | SMD0603 | Mouser | 80-C0603C470J5G | KEMET | C0603C470J5GACTU | Multilayer Ceramic Capacitors MLCC - SMD/SMT 50V 47pF 0603 C0G 5%
100nF | 1 | C243 | SMD0805 | Mouser | 581-08055C104K | AVX | 08055C104KAT2A | Multilayer Ceramic Capacitors MLCC - SMD/SMT 50V .1uF X7R 0805 10%TOL
56pF | 4 | C268, C269, C310, C412 | SMD0402 | Mouser | 81-GCM1555C1H560JA6D | Yageo | GCM1555C1H560JA16D | CAP CER, 56PF, 50V, 5%, NPO, 0402,
22pF | 3 | C270, C411, C371 | SMD0402 | Mouser | 603-CC402JRNPO9BN220 | Yageo | CC0402JRNPO9BN220 | CAP CER, 22PF, 50V, 5%, NPO, 0402,
500fF | 1 | C271 | SMD0402 | Mouser | 81-GRM1555C2AR50BA1D | Murata_Electronics | GRM1555C2AR50BA01D | CAP CER 0.5PF 100V C0G/NP0 0402
10uF | 1 | C288 | SMD0805 | Mouser | 963-TMK212BBJ106MG-T | Taiyo Yuden | TMK212BBJ106MG-T | Multilayer Ceramic Capacitors MLCC - SMD/SMT 10uF 25V X5R 20% 0805
10uF | 3 | C289, C307, C329 | SMD1206 | Mouser | 963-TMK316BJ106KL-T | Taiyo Yuden | TMK316BJ106KL-T | Multilayer Ceramic Capacitors MLCC - SMD/SMT 10uF 25V X5R +/-10% 1206 Gen Purp
1nF | 4 | C290, C296, C513, C517 | SMD0402 | Mouser | 603-CC402KRX7R9BB102 | Yageo | CC0402KRX7R9BB102 | CAP CER 1000PF 50V 10% X7R 0402
10nF | 1 | C291 | SMD0603 | Mouser | 80-C0603C103J5RAC | KEMET | C0603C103J5RAC | Multilayer Ceramic Capacitors MLCC - SMD/SMT 50V 0.01uF 0603 X7R 0.05
1uF | 2 | C293, C374 | SMD0603 | Digi-Key | 490-3897-1-ND | Murata | GRM188R61E105KA12D | CAP_CER_1UF_25V_X5R_0603
18pF | 1 | C295 | SMD0402 | Mouser | 81-GCQ1555C1H180FB1D | Murata Electronics | GCQ1555C1H180FB01D | Multilayer Ceramic Capacitors MLCC - SMD/SMT 0402 50VDC 18pF 1%
330pF | 1 | C314 | SMD0402 | Mouser | 81-GCM1555C1H331FA6D | Murata Electronics | GCM1555C1H331FA16D | Multilayer Ceramic Capacitors MLCC - SMD/SMT 0402 330pF 50volts C0G 1%
68pF | 2 | C320, C465 | SMD0402 | Mouser | 81-GCM1555C1H680JA6J | Murata Electronics | GCM1555C1H680JA16J | Multilayer Ceramic Capacitors MLCC - SMD/SMT 0402 68pF 50volts C0G 5%
15pF | 2 | C321, C466 | SMD0402 | Mouser | 81-GJM1555C1H150JB1D | Murata Electronics | GJM1555C1H150JB01D | Multilayer Ceramic Capacitors MLCC - SMD/SMT 0402 15pF 50Volts C0G 5%
120pF | 4 | C322, C324, C467, C469 | SMD0603 | Mouser | 81-GRM1885C2A121JA01 | Murata Electronics | GRM1885C2A121JA01D | Multilayer Ceramic Capacitors MLCC - SMD/SMT 0603 120pF 100volts C0G 5%
20pF | 2 | C323, C468 | SMD0402 | Mouser | 81-GJM1555C1H200GB01 | Murata Electronics | GJM1555C1H200GB01D | Multilayer Ceramic Capacitors MLCC - SMD/SMT 0402 20pF 50Volts C0G 2%
4.3pF | 2 | C325, C470 | SMD0402 | Mouser | 81-GCM1555C1H4R3CA6D | Murata Electronics | GCM1555C1H4R3CA16D | Multilayer Ceramic Capacitors MLCC - SMD/SMT 0402 4.3pF 50volts C0G
15pF | 3 | C344, C347, C348 | SMD0402 | Mouser | 81-GCM1555C1H150JA6J | Murata Electronics | GCM1555C1H150JA16J | Multilayer Ceramic Capacitors MLCC - SMD/SMT 0402 15pF 50volts C0G 5%
2.7pF | 1 | C349 | SMD0603 | Mouser | 80-CBR06C279B5G | KEMET | CBR06C279B5GAC | Multilayer Ceramic Capacitors MLCC - SMD/SMT 50V 2.7pF C0G 0603 0.1pF
3.9pF | 2 | C350, C352 | SMD0603 | Mouser | 80-CBR06C399B5G | KEMET | CBR06C399B5GAC | Multilayer Ceramic Capacitors MLCC - SMD/SMT 50V 3.9pF C0G 0603 0.1pF
120pF | 2 | C351, C381 | SMD0603 | Mouser | 80-C0603C121J5G | KEMET | C0603C121J5GACTU | Multilayer Ceramic Capacitors MLCC - SMD/SMT 50V 120pF 0603 C0G 5%
1.5pF | 1 | C354 | SMD0603 | Mouser | 80-CBR06C159B5G | KEMET | CBR06C159B5GAC | Multilayer Ceramic Capacitors MLCC - SMD/SMT 50V 1.5pF C0G 0603 0.1pF
330pF | 1 | C355 | SMD0603 | Mouser | 81-GCM1885C2A331FA6D | Murata Electronics | GCM1885C2A331FA16D | Multilayer Ceramic Capacitors MLCC - SMD/SMT 0603 330pF 100volts C0G 1%
5.6pF | 1 | C356 | SMD0603 | Mouser | 80-CBR06C569D5GAC | KEMET | CBR06C569D5GAC | Multilayer Ceramic Capacitors MLCC - SMD/SMT 50V 5.6pF C0G 0603 0.5pF
1pF | 1 | C357 | SMD0603 | Mouser | 80-CBR06C109B5GAC | KEMET | CBR06C109B5GAC | Multilayer Ceramic Capacitors MLCC - SMD/SMT 50V 1pF C0G 0603 0.1pF
56pF | 1 | C366 | SMD0402 | Mouser | 81-GCM1555C1H560FA6D | Murata Electronics | GCM1555C1H560FA16D | Multilayer Ceramic Capacitors MLCC - SMD/SMT 0402 56pF 50volts C0G 1%
27pF | 3 | C367, C410, C413 | SMD0402 | Mouser | 81-GCM1555C1H270FA6D | Murata Electronics | GCM1555C1H270FA16D | Multilayer Ceramic Capacitors MLCC - SMD/SMT 0402 27pF 50volts C0G 1%
7.3pF | 1 | C372 | SMD0402 | Mouser | 81-GJM1555C1H7R3BB1D | Murata | GJM1555C1H7R3BB01D | Multilayer Ceramic Capacitors MLCC - SMD/SMT 0402 7.4pF 50volts C0G +/-0.1pF
1000pF | 2 | C373, C375 | SMD0402 | Mouser | 81-GRM1555C1H102FA1D | Murata Electronics | GRM1555C1H102FA01D | Multilayer Ceramic Capacitors MLCC - SMD/SMT 0.001uF 50Volts 1%
47nF | 4 | C379, C380, C473, C479 | SMD0603 | Mouser | 80-C0603C473J3R | KEMET | C0603C473J3RACTU | Multilayer Ceramic Capacitors MLCC - SMD/SMT 25V 0.047uF 0603 X7R 5%
18pF | 1 | C382 | SMD0603_gap05 | Mouser | 80-C0603C180J5G | KEMET | C0603C180J5GACTU | Multilayer Ceramic Capacitors MLCC - SMD/SMT 50V 18pF 0603 C0G 5%
8.2pF | 1 | C385 | SMD0603_gap05 | Mouser | 80-CBR06C829D5GAC | Kemet | CBR06C829D5GAC | Multilayer Ceramic Capacitors MLCC - SMD/SMT 50V 8.2pF C0G 0603 0.5pF
4pF | 1 | C387 | SMD0603_gap05 | Mouser | 80-CBR06C409B5GAC | KEMET | CBR06C409B5GAC | Multilayer Ceramic Capacitors MLCC - SMD/SMT 50V 4pF C0G 0603 0.1pF
3.1pF | 1 | C389 | SMD0603_gap05 | Mouser | 80-CBR06C319B5GAC | KEMET | CBR06C319B5GAC | Multilayer Ceramic Capacitors MLCC - SMD/SMT 50V 3.1pF C0G 0603 0.1pF
7pF | 1 | C400 | SMD0603 | Mouser | 80-CBR06C709C5GAC | KEMET | CBR06C709C5GAC | Multilayer Ceramic Capacitors MLCC - SMD/SMT 50V 7pF C0G 0603 0.25pF
9.2pF | 1 | C403 | SMD0402 | Mouser | 81-GJM1555C1H9R2BB1D | Murata Electronics | GJM1555C1H9R2BB01D | Multilayer Ceramic Capacitors MLCC - SMD/SMT 0402 9.2pF 50Volts C0G +/-0.1pF
5.7pF | 1 | C404 | SMD0402 | Mouser | 81-GRM1555C1H5R7BA1D | Murata Electronics | GRM1555C1H5R7BA01D | Multilayer Ceramic Capacitors MLCC - SMD/SMT 0402 5.7pF 50volts C0G +/-0.1pF
12pF | 1 | C405 | SMD0402 | Mouser | 81-GCQ1555C1H120FB1D | Murata Electronics | GCQ1555C1H120FB01D | Multilayer Ceramic Capacitors MLCC - SMD/SMT 0402 50VDC 12pF 1% AEC-Q200
7.8pF | 1 | C406 | SMD0402 | Mouser | 81-GRM0225C1E7R8DA3L | Murata Electronics | GRM0225C1E7R8DA03L | Multilayer Ceramic Capacitors MLCC - SMD/SMT 7.8PF 25V .5PF 01005
15pF | 1 | C407 | SMD0402 | Mouser | 81-GCQ1555C1H150FB1D | Murata Electronics | GCQ1555C1H150FB01D | Multilayer Ceramic Capacitors MLCC - SMD/SMT 0402 50VDC 15pF 1% AEC-Q200
1pF | 1 | C408 | SMD0402 | Mouser | 81-GCQ1555C1H1R0BB1D | Murata Electronics | 81-GCQ1555C1H1R0BB1D | Multilayer Ceramic Capacitors MLCC - SMD/SMT 0402 50VDC 1.0pF 0.1pF AEC-Q200
9.6pF | 1 | C409 | SMD0402 | Mouser | 81-GCQ1555C1H9R6BB1D | Murata Electronics | GCQ1555C1H9R6BB01D | Multilayer Ceramic Capacitors MLCC - SMD/SMT 0402 50VDC 9.6pF 0.1pF AEC-Q200
68pF | 1 | C414 | SMD0402 | Mouser | 81-GCM1555C1H680FA6J | Murata Electronics | GCM1555C1H680FA16J | Multilayer Ceramic Capacitors MLCC - SMD/SMT 0402 68pF 50volts C0G 1%
8.1pF | 1 | C415 | SMD0402 | Mouser | 81-GJM1555C1H8R1BB1D | Murata Electronics | GJM1555C1H8R1BB01D | Multilayer Ceramic Capacitors MLCC - SMD/SMT 0402 8.1pF 50Volts C0G +/-0.1pF
47pF | 1 | C416 | SMD0402 | Mouser | 81-GCQ1555C1H470JB1D | Murata Electronics | GCQ1555C1H470JB01D | Multilayer Ceramic Capacitors MLCC - SMD/SMT 0402 50VDC 47pF 5% AEC-Q200
100pF | 4 | C452, C457, C474, C480 | SMD0603_gap05 | Mouser | 80-C0603C101J1G | Murata Electronics North America | C0603C101J1GACTU | Multilayer Ceramic Capacitors MLCC - SMD/SMT 100V 100pF 0603 C0G 0.05
47pF | 4 | C453, C459, C462, C463 | SMD0603_gap05 | Mouser | 80-C0603C470J4GACTU | KEMET | C0603C470J4GACTU | Multilayer Ceramic Capacitors MLCC - SMD/SMT 16V 47pF 0603 C0G 5%
1pF_NF | 1 | C460 | SMD0603_gap05 | Mouser | 80-CBR06C109B5GAC | KEMET | CBR06C109B5GAC | Multilayer Ceramic Capacitors MLCC - SMD/SMT 50V 1pF C0G 0603 0.1pF | NF
10uF | 2 | C472, C478 | SMD0603_gap05 | Mouser | 81-GRM188R61E106KA3D | Murata Electronics | GRM188R61E106KA73D | Multilayer Ceramic Capacitors MLCC - SMD/SMT
27pF | 3 | C475, C481, C487 | SMD0603_gap05 | Mouser | 80-C0603C270J8G | Kemet | C0603C270J8GACTU | Multilayer Ceramic Capacitors MLCC - SMD/SMT 10V 27pF 0603 C0G 5%
22pF | 2 | C476, C484 | SMD0603_gap05 | Mouser | 80-C0603C220J1G | KEMET | C0603C220J1GACTU | Multilayer Ceramic Capacitors MLCC - SMD/SMT 100V 22pF 0603 C0G 5%
12pF | 1 | C483 | SMD0603 | Mouser | 80-C0603C120J3G | Kemet | C0603C120J3GACTU | Multilayer Ceramic Capacitors MLCC - SMD/SMT 25V 12pF 0603 C0G 0.05
5pF | 1 | C485 | SMD0603_gap05 | Mouser | 80-CBR06C509B5GAC | KEMET | CBR06C509B5GAC | Multilayer Ceramic Capacitors MLCC - SMD/SMT 50V 5pF C0G 0603 0.1pF
150pF | 4 | C492, C493, C494, C495 | SMD0805 | Mouser | C0805C151J5RACTU | KEMET | 80-C0805C151J5RACTU | Multilayer Ceramic Capacitors MLCC - SMD/SMT 50V 150pF X7R 0805 5%
47pF | 1 | C496 | SMD0805 | Mouser | 80-C0805C470J5G | KEMET | C0805C470J5GACTU | Multilayer Ceramic Capacitors MLCC - SMD/SMT 50V 47pF C0G 0805 5%
470pF | 1 | C514 | SMD0402 | Mouser | 81-GRM1555C1H471JA01 | Murata Electronics | GRM1555C1H471JA01D | Multilayer Ceramic Capacitors MLCC - SMD/SMT 0402 470pF 50volts C0G 5%
4.7uF | 2 | C516, C523 | SMD0603 | Mouser | 81-GRM188R61E475ME1J | Murata | GRM188R61E475ME11J | CAP_CER_4.7UF_?V_0603
2pF | 1 | C518 | SMD0402 | Mouser | 81-GRM1555C2A2R0CA1D | Murata Electronics | GRM1555C2A2R0CA01D | Multilayer Ceramic Capacitors MLCC - SMD/SMT 0402 2pF 100volts C0G +/-0.25pF
0.6pF | 1 | C519 | SMD0402 | Mouser | 81-GRM1555C2AR60BA1D | Murata Electronics | GRM1555C2AR60BA01D | Multilayer Ceramic Capacitors MLCC - SMD/SMT 0402 0.6pF 100volts C0G +/-0.1pF
47346-0001 | 1 | CON1 | USB-MINI-B | Mouser | 538-47346-0001 | Manufacturer | 47346-0001 | MICRO USB B RECPT BTTM MOUNT ASSY
SML-D12U1WT86 | 1 | D1 | LED_0603 | Mouser | 755-SML-D12U1WT86 | Rohm Semiconductor | SML-D12U1WT86 | LED RED DIFFUSED 0603 SMD
SML-D12M1WT86 | 10 | D2, D3, D7, D8, D9, D10, D11, D13, D14, D36 | LED_0603 | Mouser | 755-SML-D12M1WT86 | Rohm Semiconductor | SML-D12M1WT86 | LED YLW/GREEN 2.2V DIFFUSED 0603 SMD
NSR20F30NXT5G | 2 | D4, D5 | NSR20F30NXT5G | Mouser | 863-NSR20F30NXT5G | Manufacturer | NSR20F30NXT5G | Schottky Diodes & Rectifiers 0603 FC SCHOTTKY DIODES
NSR20F30NXT5G_NF | 1 | D6 | NSR20F30NXT5G | Mouser | 863-NSR20F30NXT5G | Manufacturer | NSR20F30NXT5G | Schottky Diodes & Rectifiers 0603 FC SCHOTTKY DIODES | NF
GSOT03-E3-08 | 1 | D12 | GSOT03-E3-08 | Mouser | 78-GSOT03-E3-08 | Vishay Semiconductor | GSOT03-E3-08 | ESD Suppressors / TVS Diodes 3.3 Volt 300 Watt Single
5.09V | 11 | D15, D16, D20, D21, D22, D28, D37, D40, D43, D46, D49 | VMN2 | Mouser | 755-CDZFHT2RA5.1B | Rohm Semiconductor | CDZFHT2RA5.1B | Zener Diodes 4.98-5.2V 100mW SOD-923 5mA
Diode_BAS16HT1G | 22 | D17, D19, D23, D26, D27, D29, D30, D31, D32, D33, D34, D35, D38, D39, D41, D42, D44, D45, D47, D48, D50, D51 | BAS16HT1G | Mouser | 863-BAS16HT1G | ON Semiconductor | BAS16HT1G | Diodes - General Purpose, Power, Switching 75V 200mA
NF_5.09V | 1 | D18 | VMN2 | Mouser | 755-CDZFHT2RA5.1B | Rohm Semiconductor | CDZFHT2RA5.1B | Zener Diodes 4.98-5.2V 100mW SOD-923 5mA | NF
NF_Diode_BAS16HT1G | 2 | D24, D25 | BAS16HT1G | Mouser | 863-BAS16HT1G | ON Semiconductor | BAS16HT1G | Diodes - General Purpose, Power, Switching 75V 200mA | NF
0.4V | 2 | D52, D54 | PMEG045V100EPDZ | Mouser | 771-PMEG045V100EPDZ | Nexperia | PMEG045V100EPDZ | Schottky Diodes & Rectifiers 45V 10A low VF MEGA Schottky barrier rec
15.3V | 1 | D53 | P6SMB18CA | Mouser | 652-P6SMB18CA | Bourns | P6SMB18CA | ESD Suppressors / TVS Diodes 18V 600W BiDir
0R | 1 | F1 | 3405.0174.11 | Mouser | 693-3405.0174.11 | Schurter | 3405.0174.11 | Surface Mount Fuses UMF 250, 6.3A 250 VAC, 125 VDC
60 Ohm @100MHz, 1A | 1 | FB1 | SMD0805 | Mouser | 810-MMZ2012Y600BT000 | TDK | MMZ2012Y600BT000 | FERRITE CHIP, BEAD, 60 OHM, SMD,
10uH | 1 | FB2 | SMD0603 | Mouser | 810-MLZ1608E100MT | TDK | MLZ1608E100MT | Fixed Inductors 0603 10uH 20%
600_Ohm_@_100MHz_2A | 10 | FB3, FB4, FB5, FB6, FB7, FB8, FB9, FB10, FB11, FB12 | SMD0805 | Mouser | 810-MPZ2012S601AT000 | TDK | MPZ2012S601AT000 | Ferrite Beads 600ohms 2A 100mOhms 0805 Ferrite Chip
100uF | 1 | FB16 | SMD_1812FS-104JLC | Mouser | 994-1812FS-104JLC | Coilcraft | 1812FS-104JLC | Fixed Inductors 1812FS High L Filter 100uH 5% 2.5Ohms
HEAT_SINK_558-75AB | 1 | H1 | HEAT_SINK_558-75AB | Mouser | 567-558-75AB | Wakefield-Vette | 558-75AB | Heat Sinks Heatsink for DC/DC Converters, Full Brick, 61x116.8x19.1mm, Vertical, 16 Fins | NF
AD5513 | 2 | IC1, IC2 | ADL5513 | Mouser | 584-ADL5513ACPZ-R7 | Analog Devices | ADL5513ACPZ-R7 | RF Detector 1MHz-4GHz 80 dB
SMA_H | 7 | J1, J2, J3, J4, J5, J17, J18 | SMA_v2 | Digi-Key | CON-SMA-EDGE-S-ND | RF Solutions | CON-SMA-EDGE-S | CONN SMA JACK STR EDGE MNT
CONN_HEADER_TSM-103-04-L-SV | 4 | J6, J7, J19, J22 | TSM-103-04-L-SV | Mouser | 200-TSM10304LSV | Samtec | TSM-103-04-L-SV | Headers & Wire Housings .100" Surface Mount Terminal Strip
CONN_HEADER_TSM-103-04-F-DV | 2 | J8, J11 | TSM-103-04-F-DV | Mouser | 200-TSM10304FDV | Samtec | TSM-103-04-F-DV | Headers & Wire Housings .100" Surface Mount Terminal Strip
CONN_HEADER_M20-8770342 | 3 | J9, J10, J33 | M20-8770342 | Mouser | 855-M20-8770342 | FCI | M20-8770342 | CONN HEADER SMD 3POS 2.54MM
PIN_HEADER_2X5_M50-3600542 | 1 | J12 | PIN_HEADER_2X5 | Mouser | 855-M50-3600542 | Harwin | M50-3600542 | Headers & Wire Housings 5+5 DIL PIN HDR SMT Au/Sn
CONN_HEADER_TSM-104-04-T-DV | 1 | J13 | TSM-104-04-T-DV | Mouser | 200-TSM10404TDV | Harwin | TSM-104-04-T-DV | Headers & Wire Housings .100" Surface Mount Terminal Strip
CONN_HEADER_TSM-102-04-T-SV | 9 | J14, J20, J24, J25, J26, J27, J29, J31, J36 | TSM-102-04-T-SV | Mouser | TSM-102-04-T-SV | Samtec | 200-TSM10204TSV | Headers & Wire Housings .100" Surface Mount Terminal Strip
CONN_1757242 | 1 | J15 | CONN_1757242 | Mouser | 651-1757242 | Phoenix Contact | 1757242 | Pluggable Terminal Blocks 2 Pos 5.08mm pitch Through Hole Header
CONN_1757307 | 1 | J16 | CONN_1757307 | Mouser | 651-1757307 | Phoenix Contact | 1757307 | Pluggable Terminal Blocks 8 Pos 5.08mm pitch Through Hole Header
NF_UMC_SMD | 2 | J21, J28 | UMC_SMD | Mouser | 538-73412-0110 | Molex | 734120110 | RF Connectors / Coaxial Connectors MCX V PCB JACK SMT 1.25MM MNT HGT | NF
DC_POWER_CONN_RAPC712X | 1 | J23 | RAPC712X | Mouser | 502-RAPC712X | Switchcraft | RAPC712X | DC Power Connectors R/A POWER JACK
PIN_HEADER_2X2_SSM-102-L-DV-K-TR | 2 | J30, J32 | PIN_HEADER_2X2_SSM-102-L-DV-K-TR | Mouser | 200-SSM102LDVKTR | Samtec | SSM-102-L-DV-K-TR | Headers & Wire Housings .100" (2.54 mm) Tiger Claw Surface Mount Socket Strip
Jumper_SNM-100-BK-T | 13 | J34, J35, J37, J38, J39, J40, J41, J42, J43, J44, J46, J47, J48 | SNM-100-BK-T | Mouser | 200-SNM100BKT | Samtec | SNM-100-BK-T | Headers & Wire Housings .050" x .100" Shunt | NF
2.2uH | 3 | L1, L2, L119 | SPM6530T-2R2M | Mouser | 810-SPM6530T-2R2M | TDK Corporation | SPM6530T-2R2M | Fixed Inductors 2.2uH 0.0173ohms 7.1x6.5x3mm
10nH | 2 | L3, L121 | SMD0402 | Mouser | 81-LQW15AN10NG0ZD | Murata Electronics | LQW15AN10NG0ZD | Fixed Inductors 0402 10nH 0.17ohms 500mA +/-2%
18nH | 2 | L4, L71 | SMD0603 | Mouser | 81-LQW18AN18NG00D | Murata Electronics | LQW18AN18NG00D | Fixed Inductors 0603 18nH 2%, 550mA
82nH | 1 | L5 | SMD0805 | Mouser | 81-LQW2BAS82NJ00L | Murata Electronics | LQW2BAS82NJ00L | Fixed Inductors 0805, 82nH , 300mA SRF 1330MHz, 5%
10uH | 2 | L6, L7 | SMD0805 | Mouser | 810-MLZ2012M100WT000 | TDK Corporation | MLZ2012M100WT000 | FIXED IND 10UH 350MA 470 MOHM
180nH | 4 | L8, L15, L74, L105 | SMD0805 | Mouser | 994-0805HP-181XGRB | COILCRAFT | 0805HP-181XGRB | Fixed Inductors 180nH 2% 0.54A DCR=0.374Ohms
12nH | 3 | L9, L16, L34 | SMD0805 | Mouser | 994-0805HP-12NXGRB | COILCRAFT | 0805HP-12NXGRB | Fixed Inductors 12nH 2% 1.4A DCR=0.039Ohms
47nH | 2 | L10, L14 | SMD0805 | Mouser | 994-0805HP-47NXGRB | COILCRAFT | 0805HP-47NXGRB | Fixed Inductors 47nH 2% 1A DCR=0.093Ohms
100nH | 2 | L11, L13 | SMD0805 | Mouser | 994-0805HP-101XGRB | COILCRAFT | 0805HP-101XGRB | Fixed Inductors 100nH 2% 0.72A DCR=0.22Ohms
56nH | 3 | L12, L75, L106 | SMD0805 | Mouser | 994-0805HP-56NXGRB | COILCRAFT | 0805HP-56NXGRB | Fixed Inductors 56nH 2% 0.95A DCR=0.122Ohms
6.8nH | 1 | L17 | SMD0603_gap05 | Mouser | 81-LQW18AN6N8C80D | Murata Electronics | LQW18AN6N8C80D | Fixed Inductors 1.65x0.99mm 6.8nH 1900mA+/-0.2nH
1.8uH | 3 | L18, L21, L24 | SMD1008_inductor | Mouser | 994-1008LS-182XJLB | COILCRAFT | 1008LS-182XJLB | Fixed Inductors 1008LS AEC-Q200 1.8 uH 5 % 0.6 A
2.2uH | 2 | L19, L22 | SMD1008_inductor | Mouser | 994-1008LS-222XJLB | COILCRAFT | 1008LS-222XJLB | Fixed Inductors 1008LS AEC-Q200 2.2 uH 5 % 0.52 A
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

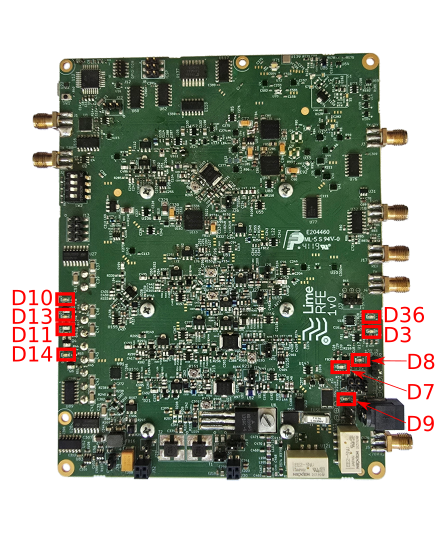
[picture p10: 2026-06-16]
docs/images/LimeRFE_v1.0_components_LEDs_top.png

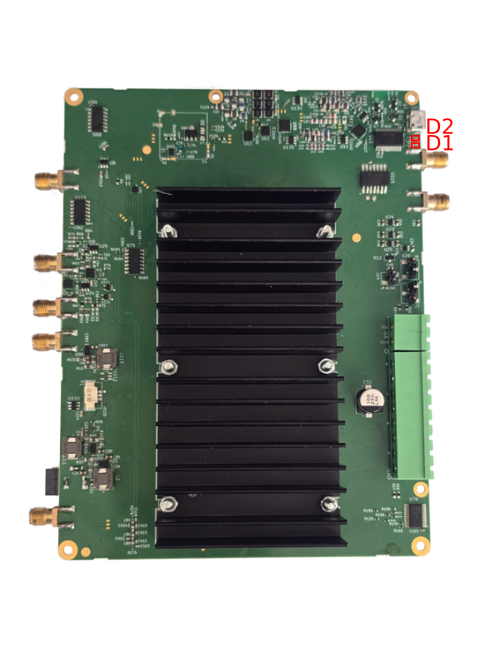
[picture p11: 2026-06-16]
docs/images/LimeRFE_v1.0_components_LEDs_bot.png

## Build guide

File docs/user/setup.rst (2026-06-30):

Hardware Setup
##############

Host Interface
**************

There are 2 possible ways to run the LimeRFE board:  

    * Through SDR board − Communication if established through the LimeSDR board using I2C. In this document this type of communication will be denoted SDR.
    * Directly through USB − Direct communication via USB.

Cooling
*******

The LimeRFE board ships with a pre-installed heatsink. Under normal ambient temperature conditions, passive cooling is sufficient to maintain stable and reliable board operation.

Default heatsink is `Wakefield Thermal 558-75AB`_:

  * Mounting Style:Screw.
  * Heat sink Material:Aluminum.
  * Fin Style:Rectangular Fin.
  * Thermal Resistance:1.8 C/W.
  * Power Dissipation @ Temperature Rise 12.0W @ 40°C.
  * Length:61 mm.
  * Width:116.8 mm.
  * Height:19.1 mm.

In environments with high ambient temperatures, an external 5V fan can be connected to the P1 connector to provide additional cooling.

.. note::
   In the event of errors, instability or reduced performance, check the board temperature to ensure that it is within the specified operating range.

RF Connections
**************


  
  Figure 3: LimeRFE board top with RF connector positions

.. list-table:: Table 1. RF Connectors
   :header-rows: 1

   * - Connector
     - Description
   * - J1
     - RF output – for RX mode (connect to SDR input)
   * - J2
     - RF input – for TX mode (connect to SDR output)
   * - J3
     - RF input – in RX mode, for all frequency bands
       
       RF output – in TX mode, for all frequency bands except 30 MHz (HF) band and 50–70 MHz (6 & 4 m) band
   * - J4
     - RF output – in TX mode, for all frequency bands except 30 MHz (HF) band, 50–70 MHz (6 & 4 m) band, 
      
       and all Cellular bands (Band 1, 2, 3, 7 and 38)
   * - J5
     - RF input – in RX mode, for 30 MHz (HF), 50–70 MHz (6 & 4 m),
       144–146 MHz (2 m), 220–225 MHz (1.25 m) and 430–440 MHz (70 cm) bands
       
       RF output – in TX mode, only for 30 MHz (HF) and 50–70 MHz (6 & 4 m) bands
   * - J17
     - Reverse power RF input (for SWR operation)
   * - J18
     - Forward power RF input (for SWR operation)
   * - J30
     - Connects external ferrite bead output matching circuit for 30 MHz and 70 MHz band transmitter.
   * - J32
     - Connects external ferrite bead output matching circuit for 30 MHz and 70 MHz band transmitter.

.. warning::
   Care should be taken when connecting external RF signals to the RX inputs, to ensure that the maximum safe input power of +10 dBm is not exceeded, as this may cause permanent damage to the device.

.. _Wakefield Thermal 558-75AB: https://wakefieldthermal.com/wakefield-thermal-heatsink-dc-dc-full-brick-558-75ab/

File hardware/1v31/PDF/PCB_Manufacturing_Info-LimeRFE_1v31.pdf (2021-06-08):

## PCB Manufacturing Info

PCB Layer Stack-Up

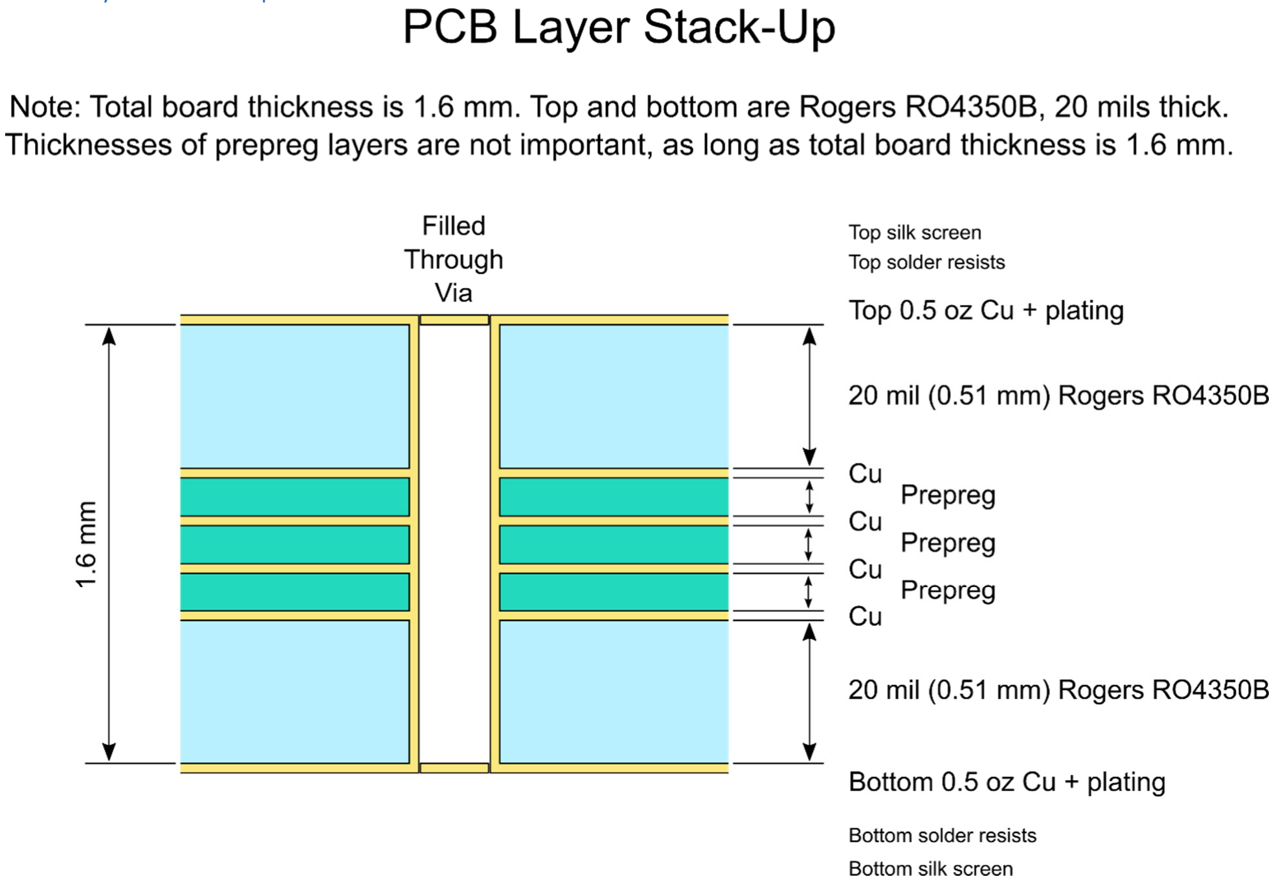
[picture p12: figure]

IMPORTANT: Top and bottom are 20mils Rogers RO4350B

Board Description

Designation: | LimeRFE_1v31
Version: | 1v31
Type: | Lead Free
Size: | 125 mm x 162.5 mm

Size with frame: 141 mm x 178.5 mm

Thickness: 1.6 mm +/- 10 %

Material: | Rogers RO4350B + FR4
Number of layers: | 6 (4 inner)

Top layer copper foil thickness: 0.5 oz (18 um)+plating

Dielectric thickness between Top layer and 2nd layer: 508 um (20 mils) – Rogers RO4350B

Dielectric between Top layer and 2nd layer relative permittivity (Er): 3.66 – Rogers RO4350B

Top layer copper foil thickness: 0.5 oz (18 um)+plating

Dielectric thickness between Bottom layer and 5th layer: 508 um (20 mils) – Rogers RO4350B

Dielectric between Bottom layer and 5th layer relative permittivity (Er): 3.66 – Rogers RO4350B

Minimum finished hole size: | 200 um
Minimum spacing: | 100 um
Minimum track width: | 100 um
Drill diameters: | finished hole
Plating finish (both sides): | Immersion gold
| 0.05-0.10 um of gold over
| 2.50-5.00 um of nickel
Top silkscreen: | Required
Bottom silkscreen: | Required

Board Stack-up

Solder Paste Front: | Lime_RFE-F.Paste.gtp
Silk Screen Front: | Lime_RFE-F.SilkS.gto
Solder Mask Front: | Lime_RFE-F.Mask.gts
1. Front Layer: | Lime_RFE-T.gtl (Top layer of top RO4350B)
2. Inner 1 - (GND): | Lime_RFE-GND.g2 (Bottom layer of top RO4350B)
3. Inner 2 - (SIG1): | Lime_RFE-SIG1.g3 (Top layer of inner FR4)
4. Inner 3 - (SIG2): | Lime_RFE-SIG2.g4 (Bottom layer of inner FR4)
5. Inner 4 - (PWR): | Lime_RFE-PWR.g5 (Top layer of bottom RO4350B)
6. Back Layer: | Lime_RFE-B.gbl (Bottom layer of bottom RO4350B)
Solder Mask Back: | Lime_RFE-B.Mask.gbs
Silk Screen Back: | Lime_RFE-B.SilkS.gbo
Solder Paste Back: | Lime_RFE-B.Paste.gbp

PCB edges: | Lime_RFE-Edge.Cuts.gm1
Drill map: | Lime_RFE-drl_map.gbr
| Lime_RFE-NPTH-drl_map.gbr

Important Notes

All vias must be resin filled with metal cap

DRCs must be run on Gerber files before building boards.

Solder mask: green, both sides, halogen free, glossy finish (NOT matte).

Silkscreen: white epoxy ink, halogen free, both sides. No silkscreen on pads.

Electrical test: 100 % netlist.

Boards are to be individually bagged.

Design software used: | KiCad Version: 4.0.7, release build

Controlled Impedance

- 50 Ohm uncoated RF GCPW lines (Top layer, RF) characteristics:

Track width for GCPW line 0.79 mm, gap 0.25 mm

Rogers 4350, 20.00 mil (between T and GND Layers), metal thickness 0.5 oz (18 um)+plating

- 50 Ohm uncoated RF GCPW lines (Bottom layer, RF) characteristics:

Track width for GCPW line 0.79 mm, gap 0.25 mm

Rogers 4350, 20.00 mil (between B and PWR Layers), metal thickness 0.5 oz (18 um)+plating

Contact Details

Lime Microsystems d.o.o.

Bulevar Mihaila Pupina 10A/I, stan 13

11070 Belgrade

Serbia

Contact person:

Milan Savic

Email: m.savic@limemicro.com

Phone: +381 64 1996 951

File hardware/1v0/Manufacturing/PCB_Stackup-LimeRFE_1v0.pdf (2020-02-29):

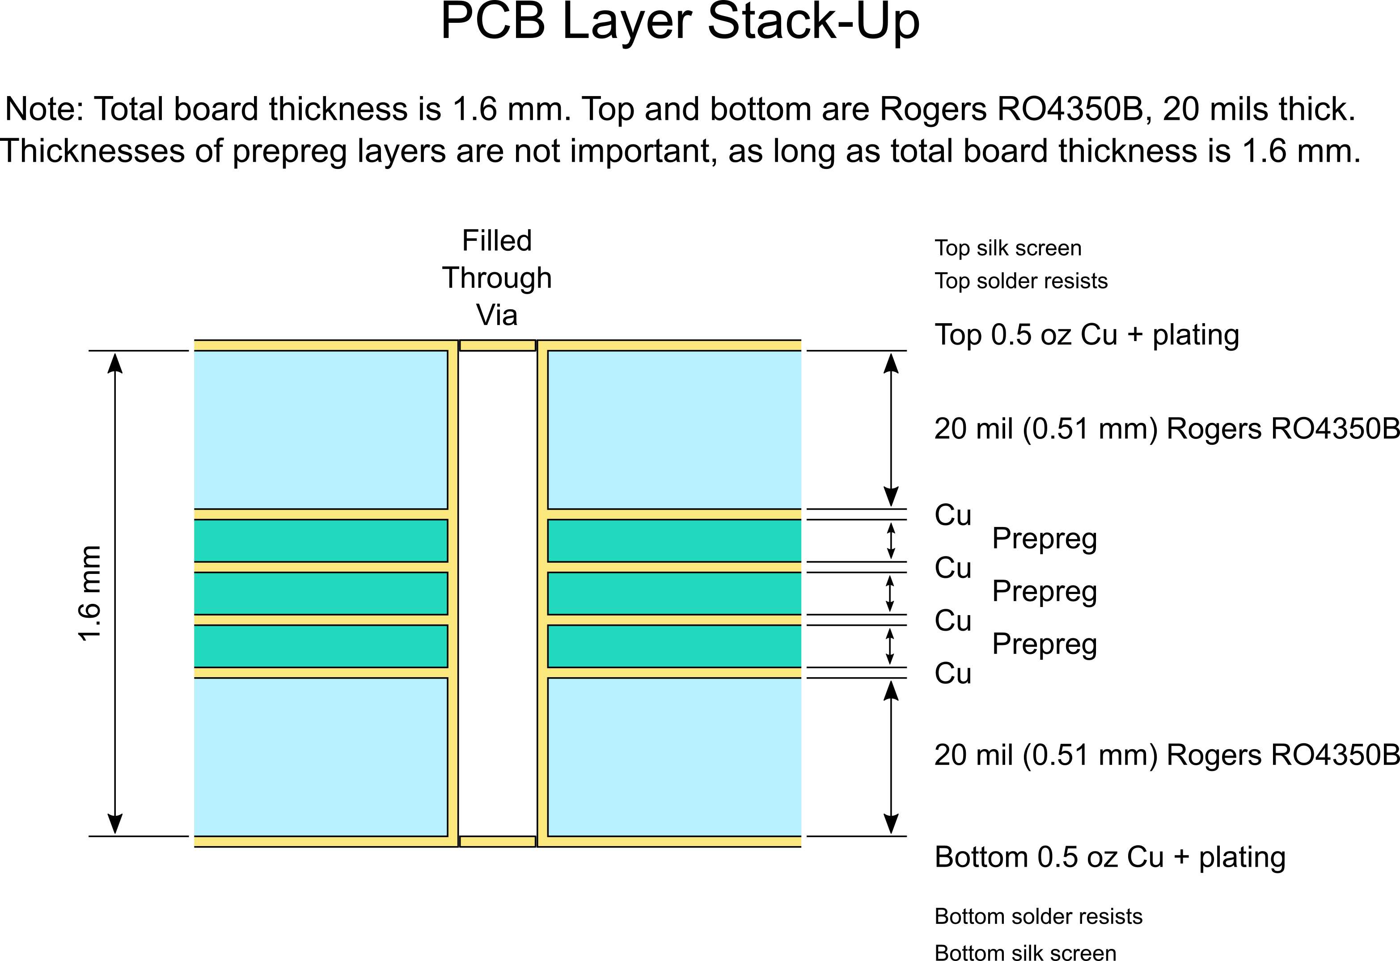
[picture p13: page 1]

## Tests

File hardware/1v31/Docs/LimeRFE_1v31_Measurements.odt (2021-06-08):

LimeRFE 1v31

Measurement Results

Version: 1.0

Revision: 6

Date: 12.03.2021

# LimeRFE 1v31 Performance Summary

Measured results of the several prototype boards are given in the table bellow.

No. | Band | TX | | | | | | RX
| | Gain [dB] | | | OP1dB [dBm] | | | Gain [dB] | | | NF [dB] | | | IIP3 [dBm]
| | Min | Nom | Max | Min | Nom | Max | Min | Nom | Max | Min | Nom | Max | Min | Nom | Max
1 | WB 1000 | 27 | | 45 | 22.5 | | 28.5 | 17 | | 21.8 | 3.4 | | 4.4 | 11.5 | | 18
2 | WB 4000 | 12 | | 33 | 14 | | 24 | 7.8 | | 18.4 | 2.7 | | 5.5 | 10 | | 23
3 | HAM 30
| 5 – 30 MHz | | 38 | | | 33 | | | 21 | | | 6 | | | 15
| 1 – 5 MHz | | | | | | | | | | | / | | 0 | | 14
4 | HAM 50-70 | | 37 | | | 32 | | | 19 | | | 3.5 | | | 14
5 | HAM 145 | | 31 | | | 34 | | | 18 | | | 3.7 | | | 12.6
6 | HAM 220 | | 33 | | | 34 | | | 18 | | | 3.7 | | | 14.8
7 | HAM 435 | | 33 | | | 34 | | | 15 | | | 4 | | | 10
8 | HAM 920 | | 35 | | | 30 | | | 17 | | | 2.8 | | | 16
9 | HAM 1280 | | 31 | | | 31 | | | 16 | | | 2.8 | | | 20
10 | HAM 2400 | | 41 | | | 28.5 | | | 13 | | | 3.8 | | | 15.5
11 | HAM 3500 | | 33 | | | 25 | | | 7.5 | | | 4.5 | | | 12.5
12 | Cell Band 1 | | 37 | | | 28 | | | 11 | | | 6.5 | | | 19
13 | Cell Band 2 | | 40 | | | 30.5 | | | 12 | | | 5.5 | | | 19.5
14 | Cell Band 3 | | 40 | | | 29.5 | | | 13 | | | 6 | | | 19
15 | Cell Band 7 | | 37 | | | 26 | | | 8 | | | 6 | | | 21
16 | Cell Band 38 | | 38 | | | 26 | | | 8 | | | 6 | | | 20

# Setup

Measurements results were corrected by 46 dB to account for the setup.

So, approximately, the additional setup contribution is:

@ 2.0 GHz approx. 0.8 dB

@ 2.5 GHz approx. 1.2 dB

@ 3.5 GHz approx. 1.5 dB

This additional setup contribution was not de-embedded from the results.

Figure 1: Setup gain

Measurement results are from the board #2.

# TX

## Wideband 1 – 1000 MHz

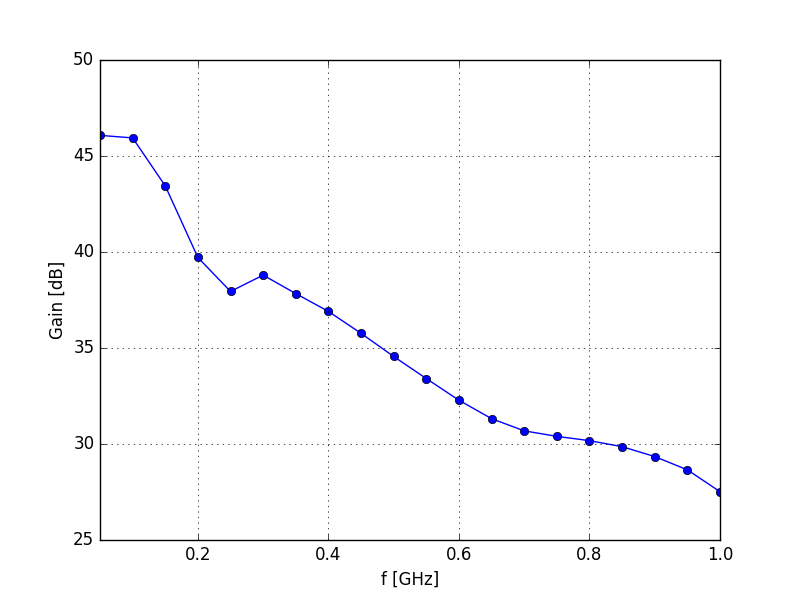
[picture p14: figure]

Figure 2: Gain | Figure 3: Output P1dB

HF Performance

The following graphs present the performance of the Wideband 1 – 1000 MHz channel for HF frequencies.

Figure 4: Gain (HF Band) | Figure 5: Output P1dB (HF Band)

## Wideband 1000 – 4000 MHz

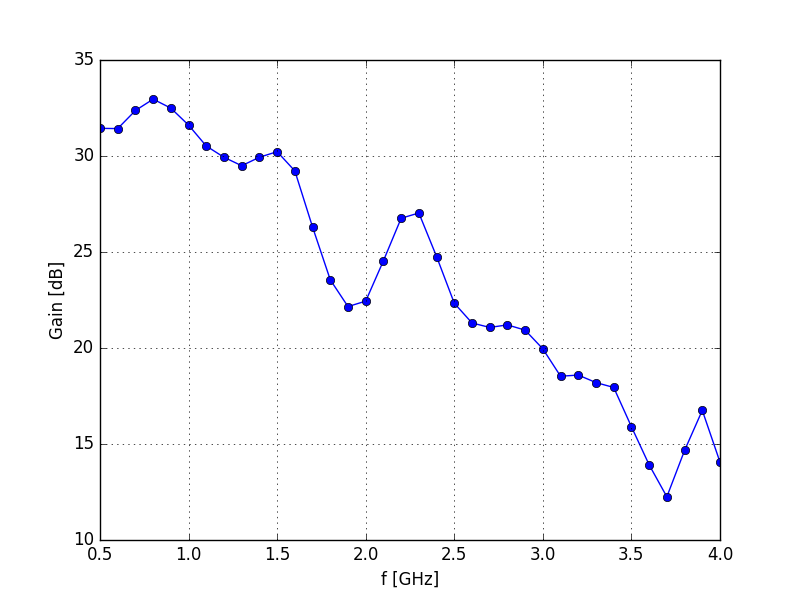
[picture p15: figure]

Figure 6: Gain | Figure 7: Output P1dB

## HAM 30 MHz (HF)

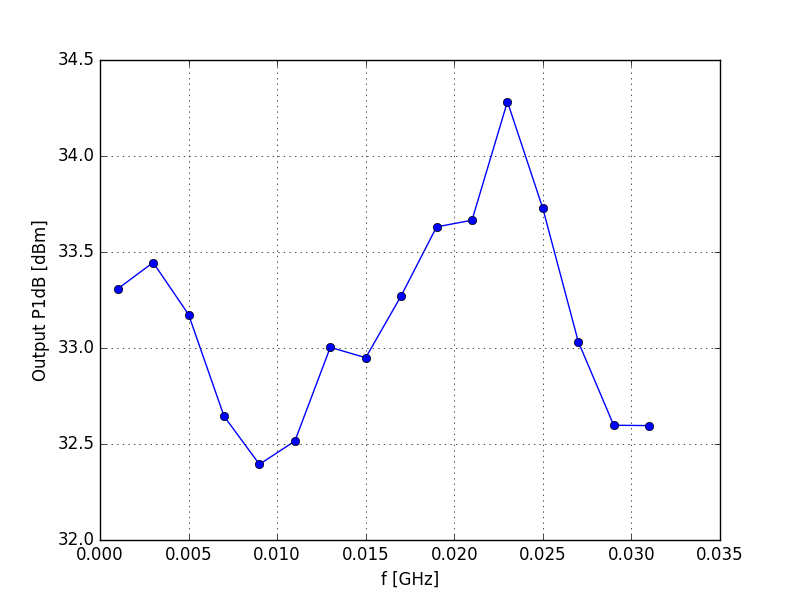
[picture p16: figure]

Figure 8: Gain | Figure 9: Output P1dB

## HAM 50 – 70 MHz (6 & 4 m)

Figure 10: Gain | Figure 11: Output P1dB

## HAM 144 – 146 MHz (2 m)

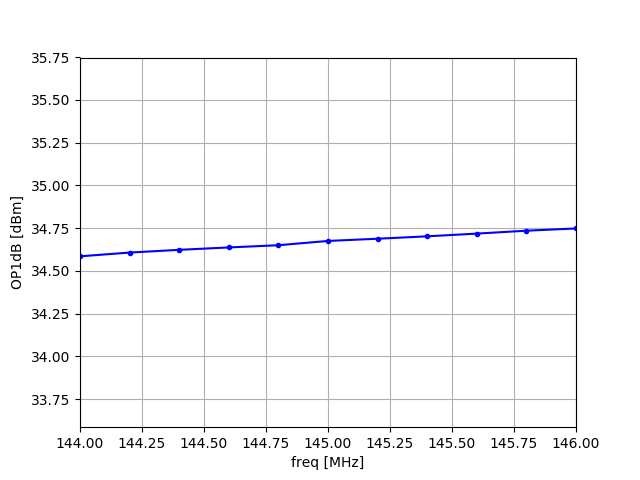
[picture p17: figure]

Figure 12: Gain | Figure 13: Output P1dB

## HAM 220 – 225 MHz (1.25 m)

Figure 14: Gain | Figure 15: Output P1dB

## HAM 430 – 440 MHz (70 cm)

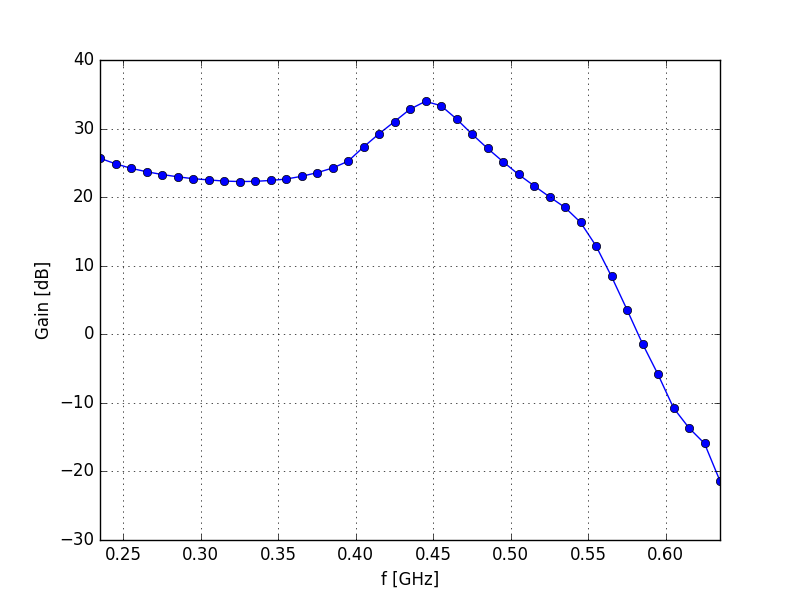
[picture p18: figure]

Figure 16: Gain | Figure 17: Output P1dB

## HAM 902 – 928 MHz (33 cm)

Figure 18: Gain | Figure 19: Output P1dB

## HAM 1240 – 1325 MHz (23 cm)

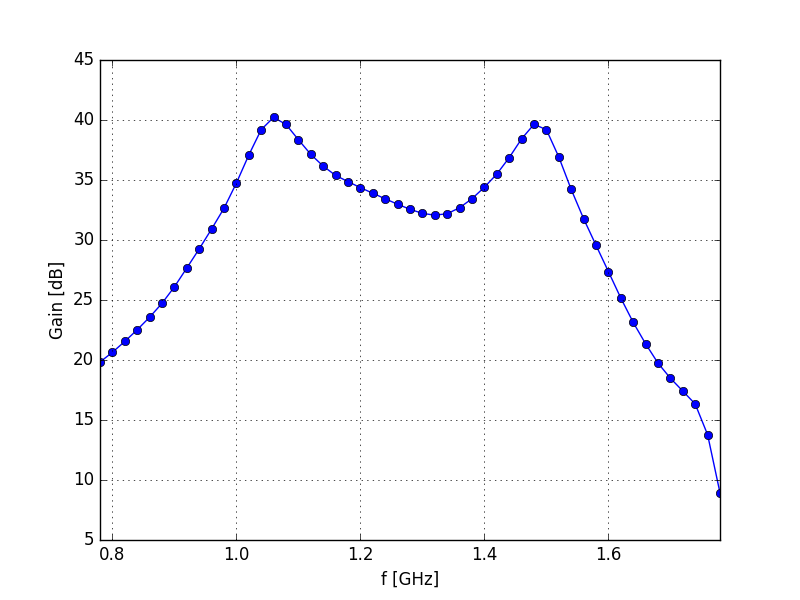
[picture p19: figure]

Figure 20: Gain | Figure 21: Output P1dB

## HAM 2300 – 2450 MHz (13 cm)

Figure 22: Gain | Figure 23: Output P1dB

## HAM 3300 – 3500 MHz (9 cm)

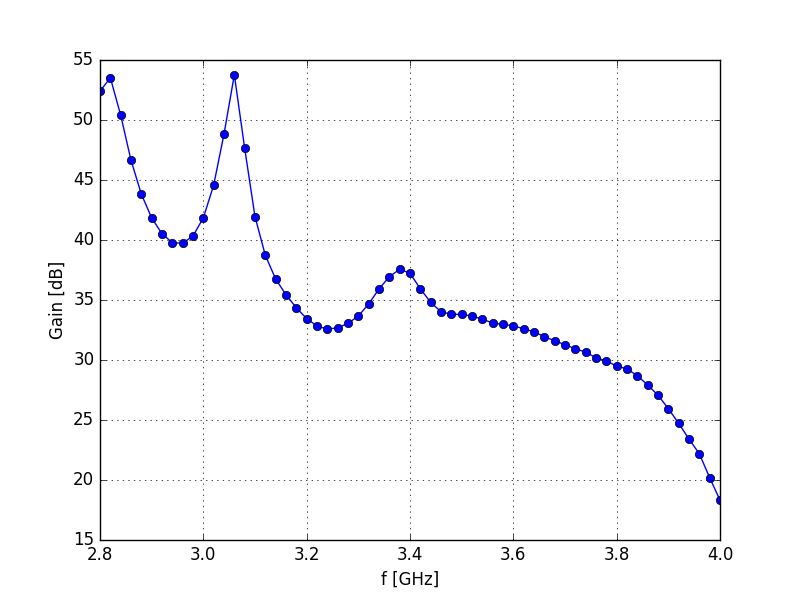
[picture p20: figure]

Figure 24: Gain | Figure 25: Output P1dB

## Cellular Band 1

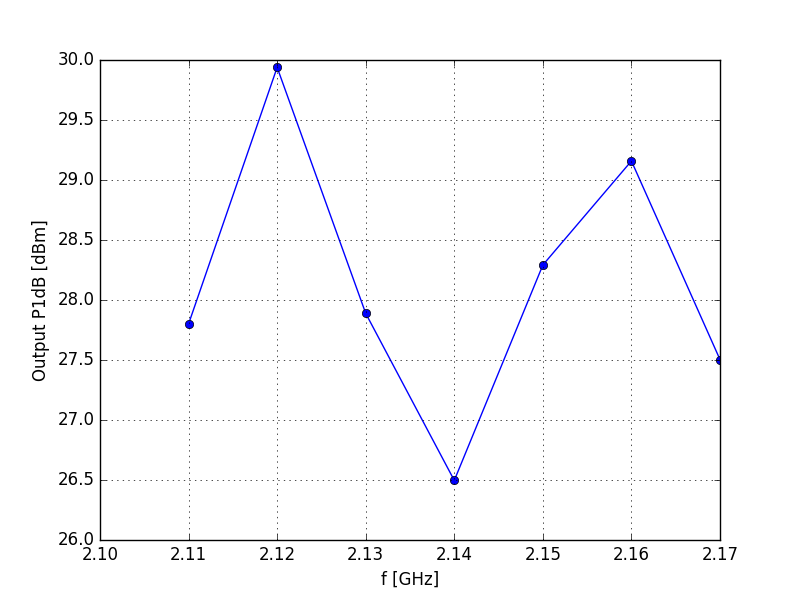
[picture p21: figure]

Figure 26: Gain | Figure 27: Output P1dB

## Cellular Band 2

Figure 28: Gain | Figure 29: Output P1dB

## Cellular Band 3

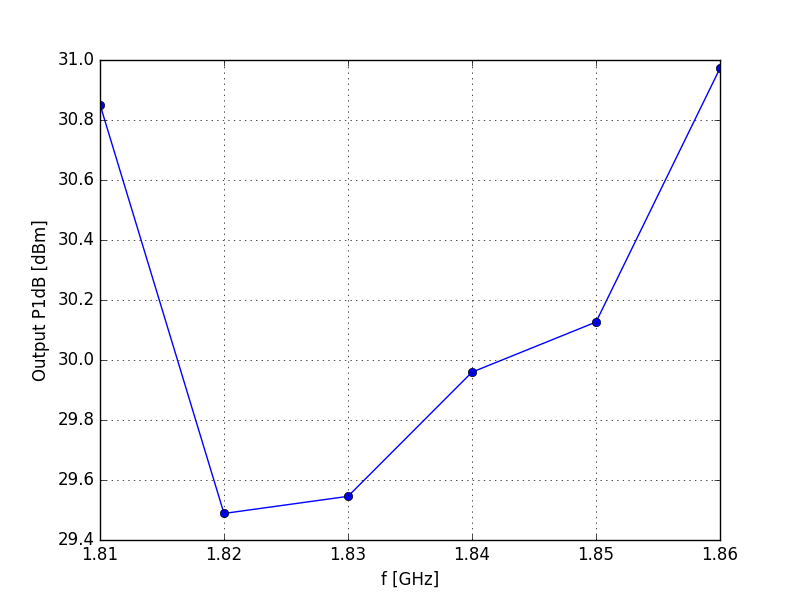
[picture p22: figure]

Figure 30: Gain | Figure 31: Output P1dB

## Cellular Band 7

Figure 32: Gain | Figure 33: Output P1dB

## Cellular Band 38

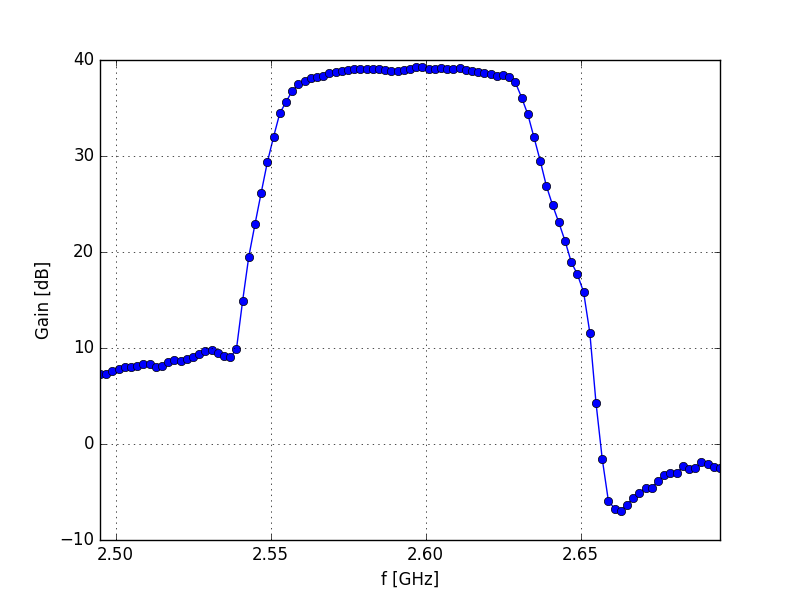
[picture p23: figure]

Figure 34: Gain | Figure 35: Output P1dB

# RX

## Wideband 1 – 1000 MHz

Figure 36: Gain | Figure 37: Noise Figure*

* Note: Extreme NF values resulted from inadequate EM isolation of the measured device. These values have not been taken into account in the Summary.


Figure 38: Input IP3

HF Performance

The following graphs present the performance of the Wideband 1 – 1000 MHz channel for HF frequencies.

Figure 39: Gain (HF Band) | Figure 40: Input IP3 (HF Band)

## Wideband 1000 – 4000 MHz


Figure 41: Gain | Figure 42: Noise Figure

Figure 43: Input IP3

## HAM 30 MHz (HF)


Figure 44: Gain | Figure 45: Noise Figure*

* Note: Extreme NF values resulted from inadequate EM isolation of the measured device. These values have not been taken into account in the Summary. NF measurements below 10 MHz are not valid, since the noise head used was not calibrated at these frequencies.

Figure 46: Input IP3**

** Note: Why does the IP3 deteriorates for frequencies below 5 MHz? This issues will be further investigated.

## HAM 50 – 70 MHz (6 & 4 m)


Figure 47: Gain | Figure 48: Noise Figure *

Figure 49: Input IP3

## HAM 144 – 146 MHz (2 m)

Figure 50: Gain | Figure 51: Noise Figure


Figure 52: Input IP3

## HAM 220 – 225 MHz (1.25 m)

Figure 53: Gain | Figure 54: Noise Figure


Figure 55: Input IP3

## HAM 430 – 440 MHz (70 cm)

Figure 56: Gain | Figure 57: Noise Figure

Figure 58: Input IP3

## HAM 902 – 928 MHz (33 cm)


Figure 59: Gain | Figure 60: Noise Figure

Figure 61: Input IP3

## HAM 1240 – 1325 MHz (23 cm)


Figure 62: Gain | Figure 63: Noise Figure *

* Note: Extreme NF values resulted from inadequate EM isolation of the measured device. These values have not been taken into account in the Summary.

Figure 64: Input IP3

## HAM 2300 – 2450 MHz (13 cm)


Figure 65: Gain | Figure 66: Noise Figure

Figure 67: Input IP3

## HAM 3300 – 3500 MHz (9 cm)

Figure 68: Gain | Figure 69: Noise Figure


Figure 70: Input IP3

## Cellular Band 1

Figure 71: Gain | Figure 72: Noise Figure*

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


Figure 73: Input IP3

## Cellular Band 2

Figure 74: Gain | Figure 75: Noise Figure *

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

Figure 76: Input IP3

## Cellular Band 3


Figure 77: Gain | Figure 78: Noise Figure

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

Figure 79: Input IP3

## Cellular Band 7


Figure 80: Gain | Figure 81: Noise Figure

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

Figure 82: Input IP3

## Cellular Band 38


Figure 83: Gain | Figure 84: Noise Figure *

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

Figure 85: Input IP3

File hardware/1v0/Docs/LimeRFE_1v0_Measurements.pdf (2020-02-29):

# LimeRFE 1v0

### Measurement Results

Version: 1.0
Revision: 5
Date: 28.02.2020

## Table of Contents

## LimeRFE 1v0 Performance Summary

Measured results of the several prototype boards are given in the table bellow.

No. | Band | TX | RX
Gain [dB] | OP1dB [dBm] | Gain [dB] | NF [dB] | IIP3 [dBm]
Min | Nom | Max | Min | Nom | Max | Min | Nom | Max | Min | Nom | Max | Min | Nom | Max
1 | WB 1000 | 26 | | 45 | 22.5 | | 28.5 | 16 | | 20.8 | 3.6 | | 4.3 | 12 | | 17.5
2 | WB 4000 | 10 | | 33 | 14 | | 24 | 7 | | 18 | 3 | | 6.5 | 11 | | 25
3 | HAM 30
| 5 – 30 MHz | | 35 | | | 32.5 | | | 20 | | | 6 | | | 15
| 1 – 5 MHz | | | | | | | | | | | / | | 8 | | 14
4 | HAM 50-70 | | 33 | | | 30 | | | 18 | | | 4 | | | 16
5 | HAM 145 | | 31 | | | 33 | | | 17 | | | 3.8 | | | 13.4
6 | HAM 220 | | 35 | | | 33.2 | | | 17 | | | 3.9 | | | 14.5
7 | HAM 435 | | 36 | | | 33.2 | | | 15 | | | 4.3 | | | 10.9
8 | HAM 920 | | 34 | | | 29.5 | | | 15 | | | 3 | | | 16
9 | HAM 1280 | | 30 | | | 29 | | | 15.5 | | | 3.5 | | | 21
10 | HAM 2400 | | 41 | | | 28.5 | | | 12.5 | | | 4 | | | 14.5
11 | HAM 3500 | | 17.5 | | | 20 | | | 7 | | | 5.5 | | | 12.5
12 | Cell Band 1 | | 37 | | | 28 | | | 11 | | | 5.8 | | | 17
13 | Cell Band 2 | | 40 | | | 30.5 | | | 11 | | | 8 | | | 17
14 | Cell Band 3 | | 40 | | | 28.5 | | | 13 | | | / | | | 16.5
15 | Cell Band 7 | | 37 | | | 26 | | | 8 | | | 6.5 | | | 18
16 | Cell Band 38 | | 38 | | | 26 | | | 7 | | | 6 | | | 18

## Setup

Measurements results were corrected by 46 dB to account for the setup. So, approximately, the additional setup contribution is:
@ 2.0 GHz approx. 0.8 dB
@ 2.5 GHz approx. 1.2 dB
@ 3.5 GHz approx. 1.5 dB
This additional setup contribution was not de-embedded from the results.


Figure 1: Setup gain
Measurement results are from the board #2.

TX

## Wideband 1 – 1000 MHz

Figure 2: Gain | Figure 3: Output P1dB

HF Performance
The following graphs present the performance of the Wideband 1 – 1000 MHz channel for HF frequencies.
Figure 4: Gain (HF Band) | Figure 5: Output P1dB (HF Band)

## Wideband 1000 – 4000 MHz


Figure 6: Gain | Figure 7: Output P1dB

## HAM 30 MHz (HF)

Figure 8: Gain | Figure 9: Output P1dB

## HAM 50 – 70 MHz (6 & 4 m)

Figure 10: Gain | Figure 11: Output P1dB

## HAM 144 – 146 MHz (2 m)


Figure 12: Gain | Figure 13: Output P1dB

## HAM 220 – 225 MHz (1.25 m)

Figure 14: Gain | Figure 15: Output P1dB

## HAM 430 – 440 MHz (70 cm)


Figure 16: Gain | Figure 17: Output P1dB

## HAM 902 – 928 MHz (33 cm)

Figure 18: Gain | Figure 19: Output P1dB

## HAM 1240 – 1325 MHz (23 cm)


Figure 20: Gain | Figure 21: Output P1dB

## HAM 2300 – 2450 MHz (13 cm)

Figure 22: Gain | Figure 23: Output P1dB

## HAM 3300 – 3500 MHz (9 cm)


Figure 24: Gain | Figure 25: Output P1dB

## Cellular Band 1

Figure 26: Gain | Figure 27: Output P1dB

## Cellular Band 2

Figure 28: Gain | Figure 29: Output P1dB

## Cellular Band 3

Figure 30: Gain | Figure 31: Output P1dB

## Cellular Band 7

Figure 32: Gain | Figure 33: Output P1dB

## Cellular Band 38


Figure 34: Gain | Figure 35: Output P1dB

RX

## Wideband 1 – 1000 MHz


Figure 36: Gain | Figure 37: Noise Figure*
* Note: Extreme NF values resulted from inadequate EM isolation of the measured device. These values have not been taken into account in the Summary.


Figure 38: Input IP3

HF Performance
The following graphs present the performance of the Wideband 1 – 1000 MHz channel for HF frequencies.


Figure 39: Gain (HF Band) | Figure 40: Input IP3 (HF Band)

## Wideband 1000 – 4000 MHz

Figure 41: Gain | Figure 42: Noise Figure


Figure 43: Input IP3

## HAM 30 MHz (HF)

Figure 44: Gain | Figure 45: Noise Figure*
* Note: Extreme NF values resulted from inadequate EM isolation of the measured device. These values have not been taken into account in the Summary. NF measurements below 10 MHz are not valid, since the noise head used was not calibrated at these frequencies.


Figure 46: Input IP3**
** Note: Why does the IP3 deteriorates for frequencies below 5 MHz? This issues will be further investigated.

## HAM 50 – 70 MHz (6 & 4 m)

Figure 47: Gain | Figure 48: Noise Figure *

Figure 49: Input IP3

## HAM 144 – 146 MHz (2 m)

Figure 50: Gain | Figure 51: Noise Figure


Figure 52: Input IP3

## HAM 220 – 225 MHz (1.25 m)

Figure 53: Gain | Figure 54: Noise Figure


Figure 55: Input IP3

## HAM 430 – 440 MHz (70 cm)

Figure 56: Gain | Figure 57: Noise Figure

Figure 58: Input IP3

## HAM 902 – 928 MHz (33 cm)

Figure 59: Gain | Figure 60: Noise Figure


Figure 61: Input IP3

## HAM 1240 – 1325 MHz (23 cm)

Figure 62: Gain | Figure 63: Noise Figure *
* Note: Extreme NF values resulted from inadequate EM isolation of the measured device. These values have not been taken into account in the Summary.


Figure 64: Input IP3

## HAM 2300 – 2450 MHz (13 cm)

Figure 65: Gain | Figure 66: Noise Figure


Figure 67: Input IP3

## HAM 3300 – 3500 MHz (9 cm)

Figure 68: Gain | Figure 69: Noise Figure

Figure 70: Input IP3

## Cellular Band 1

Figure 71: Gain | Figure 72: Noise Figure*
* Note: Extreme NF values resulted from inadequate EM isolation of the measured device. These values have not been taken into account in the Summary.


Figure 73: Input IP3

## Cellular Band 2

Figure 74: Gain | Figure 75: Noise Figure *
* Note: Extreme NF values resulted from inadequate EM isolation of the measured device. These values have not been taken into account in the Summary.


Figure 76: Input IP3

## Cellular Band 3

Figure 77: Gain | Figure 78: Noise Figure
* Note: Extreme NF values resulted from inadequate EM isolation of the measured device. These values have not been taken into account in the Summary.


Figure 79: Input IP3

## Cellular Band 7

Figure 80: Gain | Figure 81: Noise Figure

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

Figure 82: Input IP3

## Cellular Band 38

Figure 83: Gain | Figure 84: Noise Figure *
* Note: Extreme NF values resulted from inadequate EM isolation of the measured device. These values have not been taken into account in the Summary.


Figure 85: Input IP3

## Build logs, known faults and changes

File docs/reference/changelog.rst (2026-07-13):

Changelog
#########

The first production LimeRFE was revision v1.0 and so this changelog starts with changes from that point.

.. note::
   Details of internal-only versions which were never released are not included here.

v1.31
*****

Updates from LimeRFE v1.0 to LimeRFE v1.31

MCU 
===

GPIO pins have been modified so that GPIO0 and GPIO1 now support Arduino interrupt routines (IR).

LNA_EN and PA_ENn have been moved at the MCU from pins 1 and 32 to pins 14 and 13, respectively.

GPIO1_MCU and GPIO0_MCU are now connected to MCU interrupt pins INT1 and INT0 (pins 1 and 32), respectively.

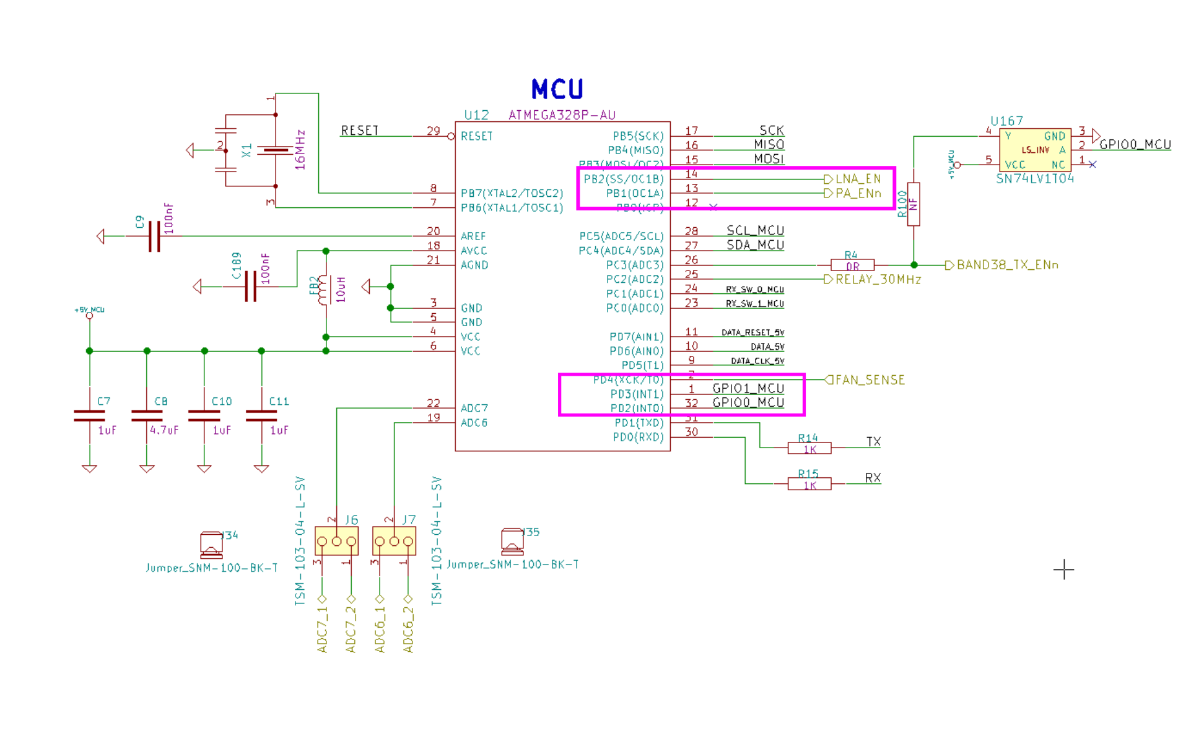
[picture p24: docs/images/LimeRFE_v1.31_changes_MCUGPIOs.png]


  Figure 1. MCU GPIO changes

To support TDD operation without an interrupt routine (IR), U167 has been added.
   
An inverter was also added to make BAND38_TX_ENn active low.

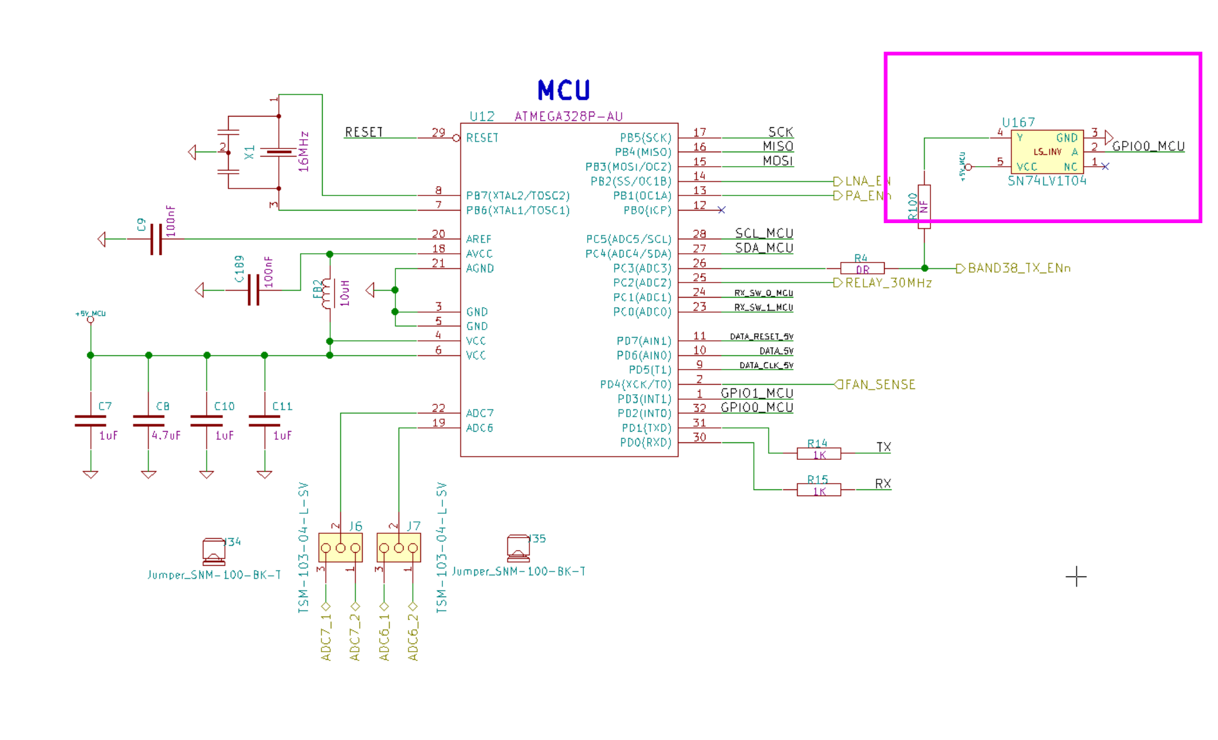
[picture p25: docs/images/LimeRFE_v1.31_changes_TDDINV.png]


  Figure 2. New TDD control inverter

R138 has been added so that the ICSP is directly connected to +5V_MCU node.

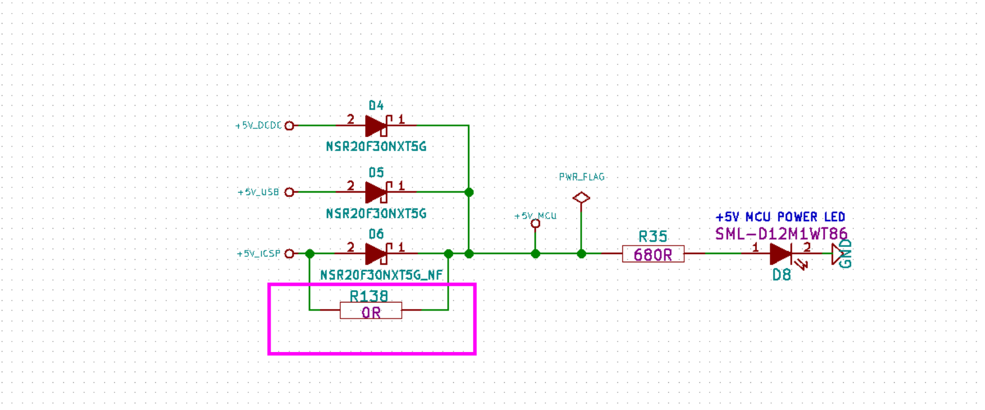
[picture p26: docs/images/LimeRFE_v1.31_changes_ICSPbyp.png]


  Figure 3. ICSP bypass

Cellular RF
===========

Additional SAW filters with matching networks have been added:

* Cell Band 01: U160
* Cell Band 02: U164, L121
* Cell Band 03: U165, L122, L123
* Cell Band 07: U166, L124, L125

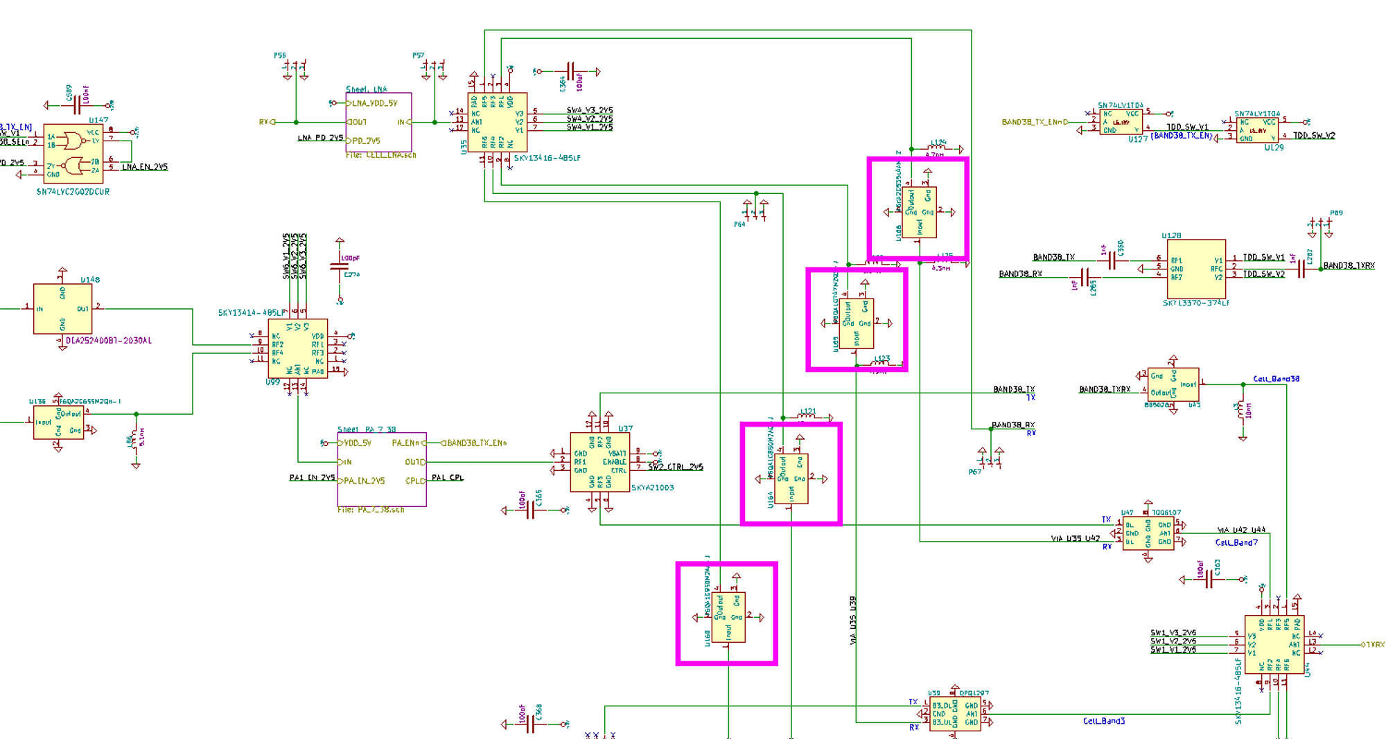
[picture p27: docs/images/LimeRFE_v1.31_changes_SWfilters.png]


  Figure 4. New band filters

The section between U57 (cellular predriver) and U86 (RF switch) has been changed from:

* MADL-011021-14150T (U160, limiter) 
* PAT1220-C-3DB-T5 (U161, attenuator)

to:

* PAT1220-C-3DB-T5 (U149, not fitted, attenuator)
* MADL-011008-14120T (U150, limiter)
* PAT1220-C-5DB-T5 (U161, not fitted, attenuator)
* Additionally, C150, C151, and L120 have been added.

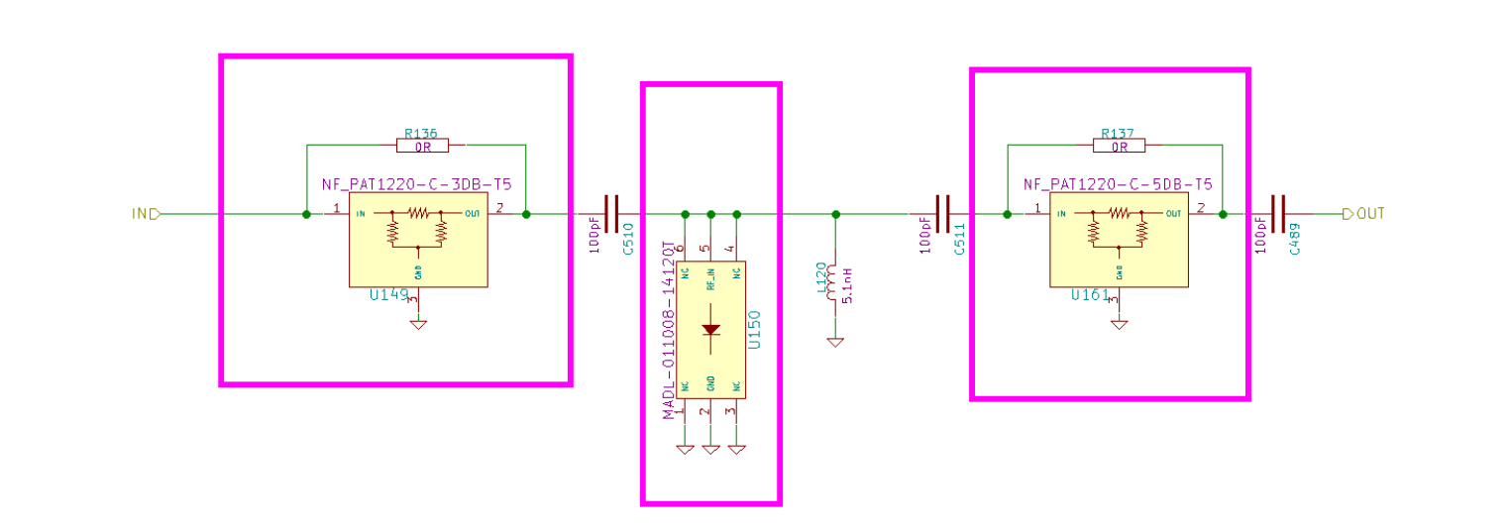
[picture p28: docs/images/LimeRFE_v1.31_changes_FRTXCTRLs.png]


  Figure 5. RF TX power controls

RF switch U86:

CELL band 7 connected RF4 changed to RF2

CELL band 38 connected to RF2 changed to RF6

Additionally, U99 swapped CELL band 7 and CELL band 38 on its pins RF2 and RF4

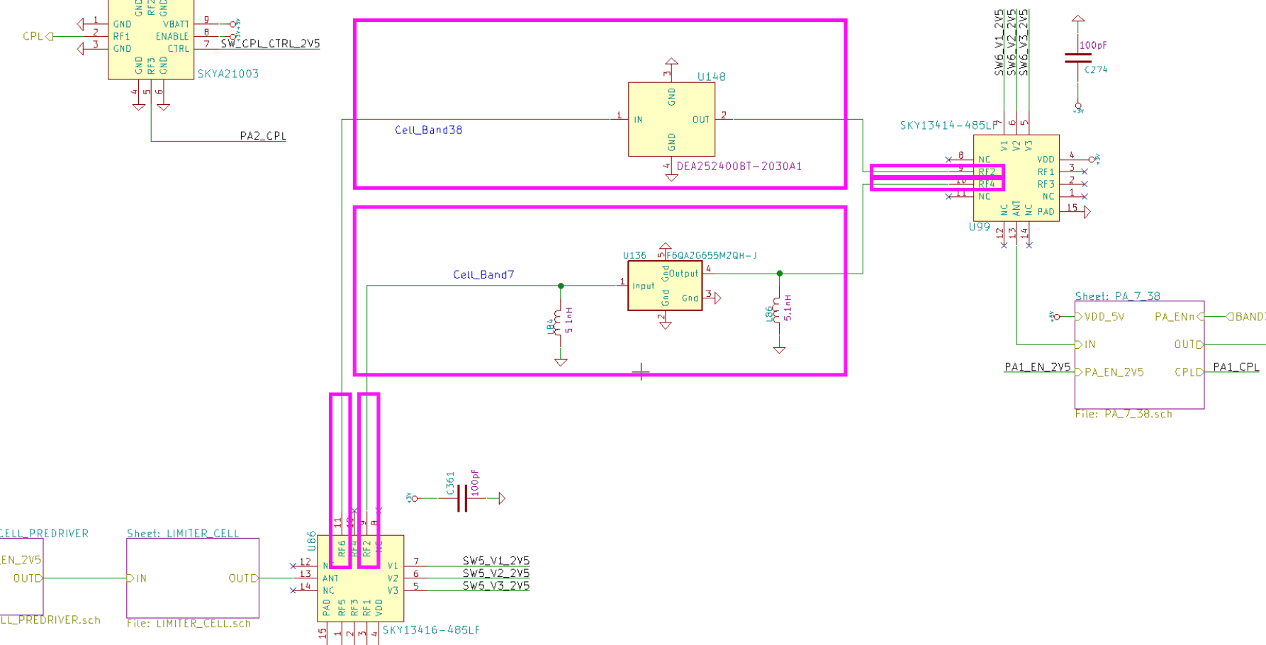
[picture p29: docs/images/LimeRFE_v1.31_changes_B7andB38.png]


  Figure 6. Cellular bands 7 and 38 connections

RF filter CELL band 38 in TX added

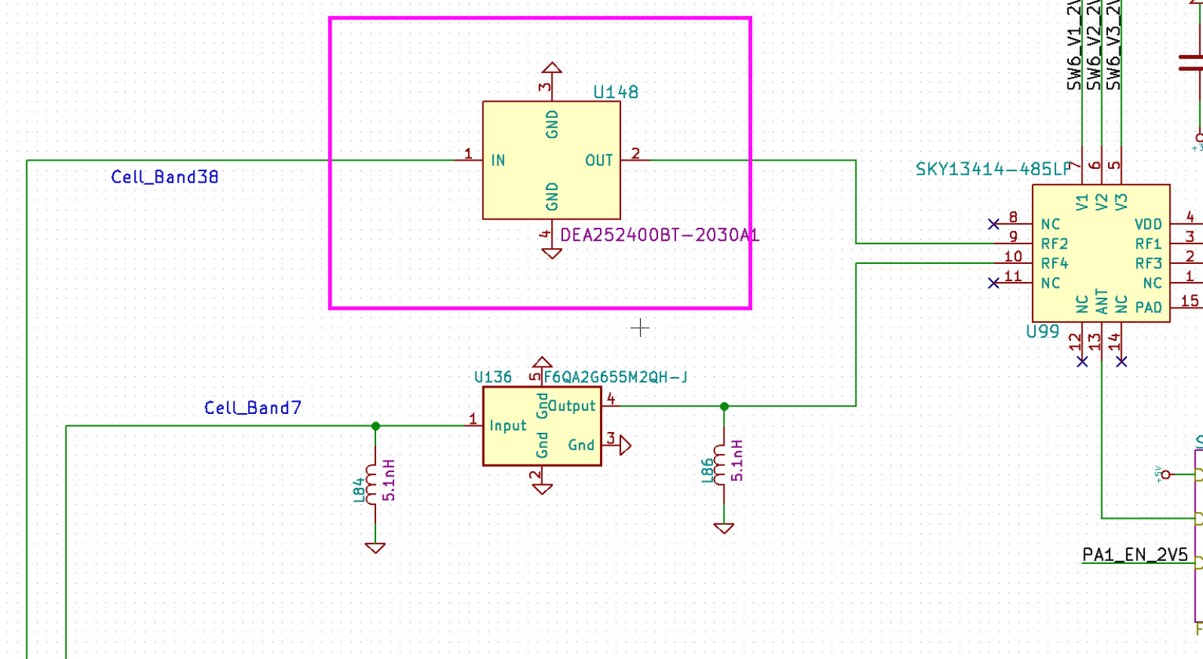
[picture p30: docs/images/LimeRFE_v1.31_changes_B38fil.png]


  Figure 7. New cellular bands 38 filter

Logical XOR circuit added for TDD contrlol for CELL band 38

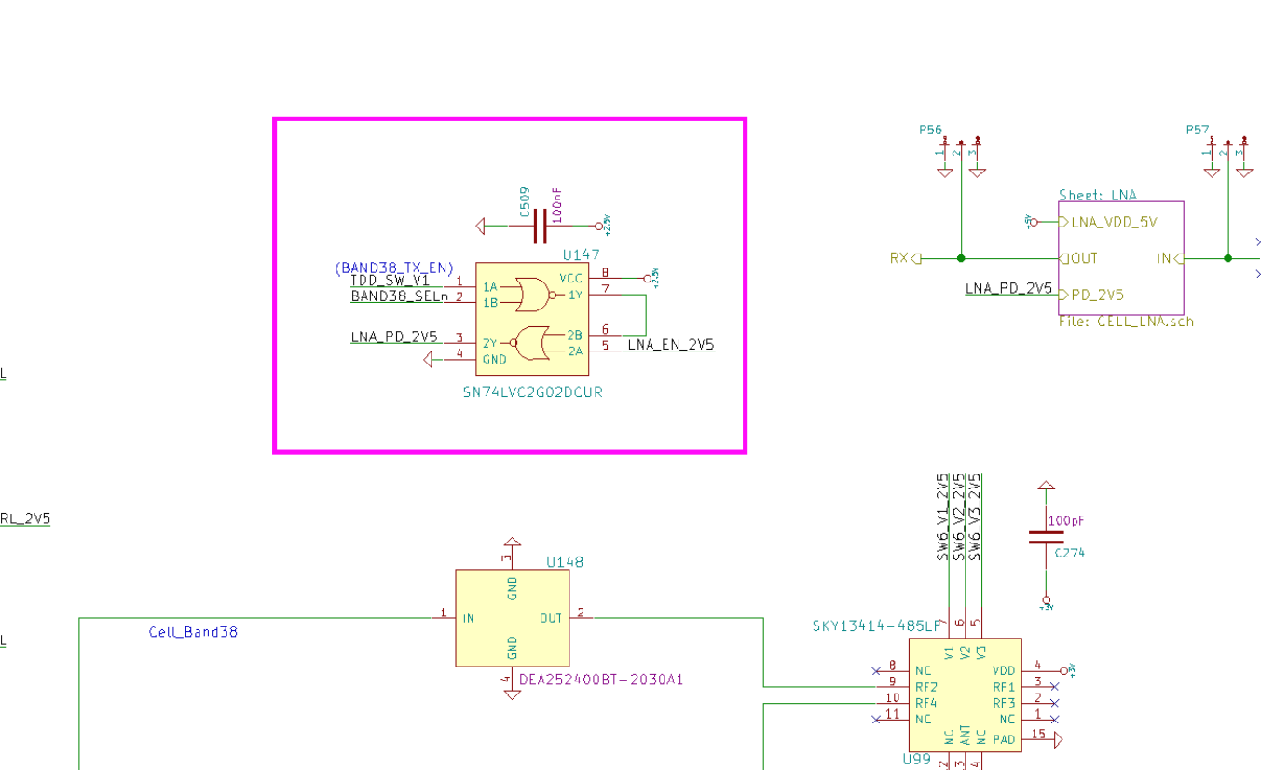
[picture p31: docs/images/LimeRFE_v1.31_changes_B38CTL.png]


  Figure 8. B38 Control

HAM RF
======

Since the PE4245 was not available on the market, it has been replaced with the HMC544AE.

Affected components: U61, U63.

Control signals for the new switches are generated by U137. These control signals are now 3 V instead of the previous 2.5 V.

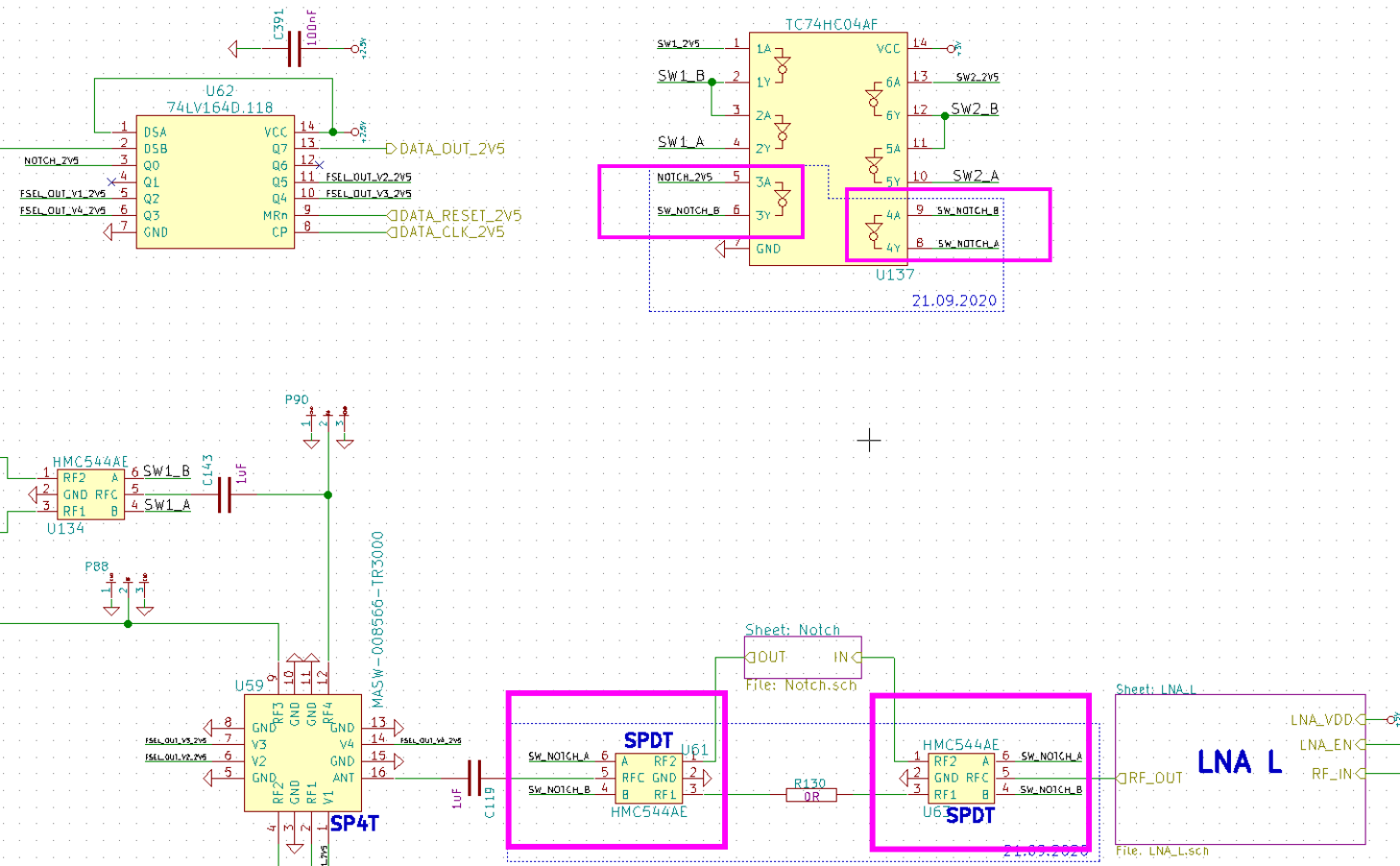
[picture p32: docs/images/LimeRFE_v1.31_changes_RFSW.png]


  Figure 9. New RF Switches

The HAM3500 PA designated as MAAM-009560 has been replaced with the MMZ38333, and the surrounding circuitry has been modified accordingly.

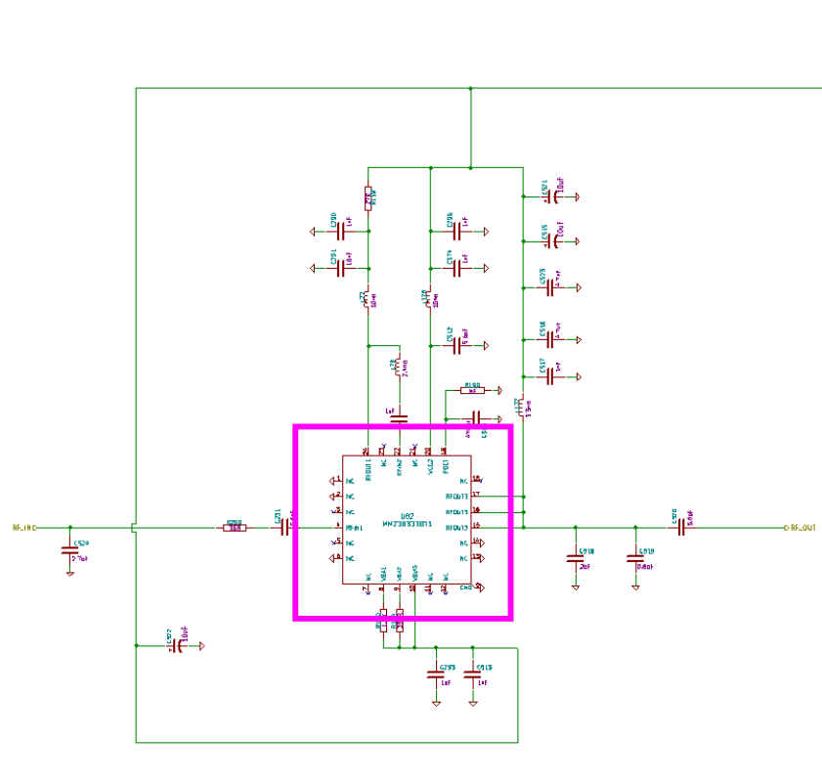
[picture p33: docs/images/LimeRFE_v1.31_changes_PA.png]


  Figure 10. New PA

Miscellaneous
=============

GPIO0, GPIO1, GPIO4 and GPIO5 have been changed, which caused additional GPIO pins remapping on several connectors and components.

GPIO remapping on Q3–Q6, U27, U28, SW2, J13, R42–R45  and U23–U26:

from GPIO0, GPIO1, GPIO2, GPIO3

to GPIO2, GPIO3, GPIO4, GPIO5.

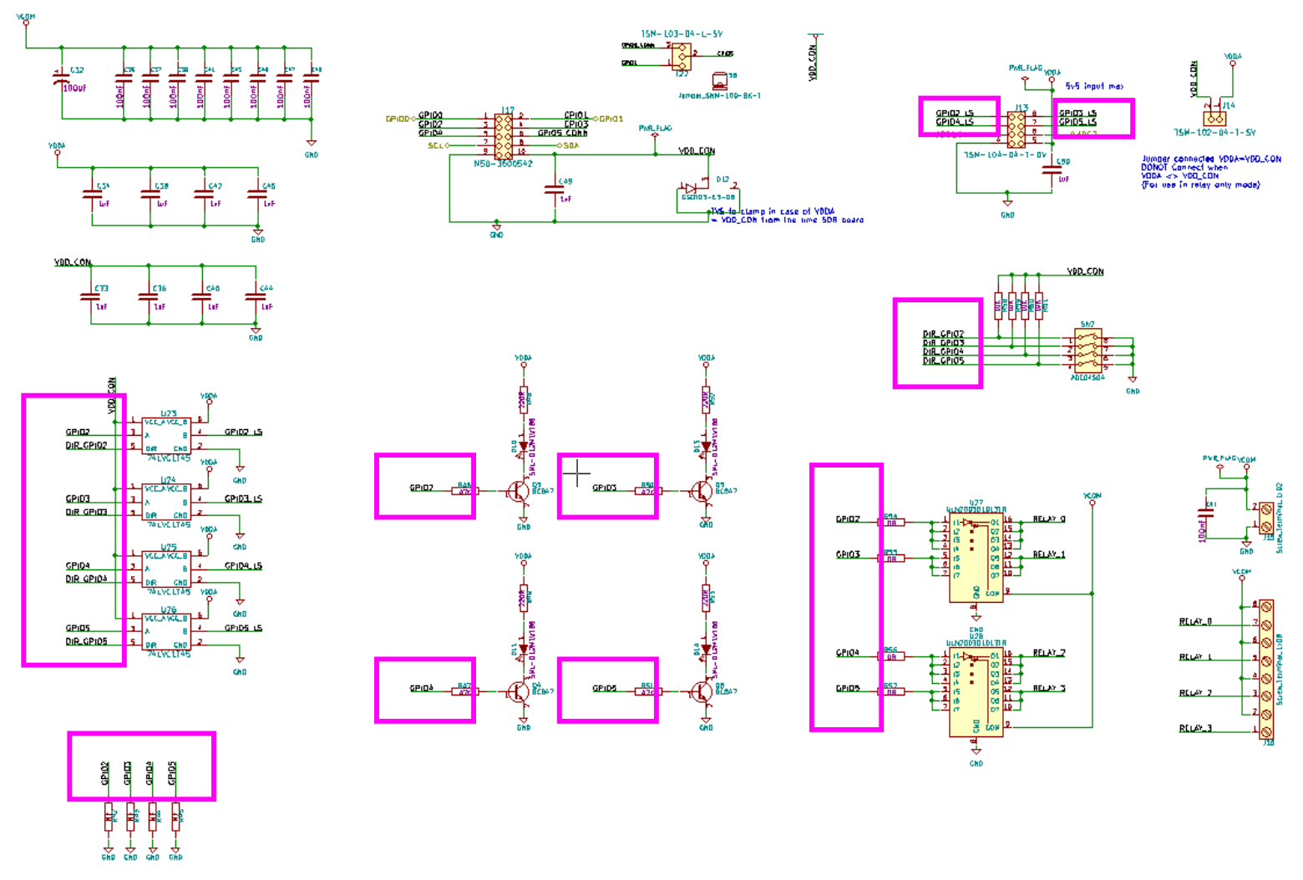
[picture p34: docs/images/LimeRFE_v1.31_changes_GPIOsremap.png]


  Figure 11. Remapped GPIOs 

This also remapped RELAY_0, RELAY_1, RELAY_2, and RELAY_3

from GPIO0, GPIO1, GPIO2, GPIO3

to GPIO2, GPIO3, GPIO4, GPIO5.

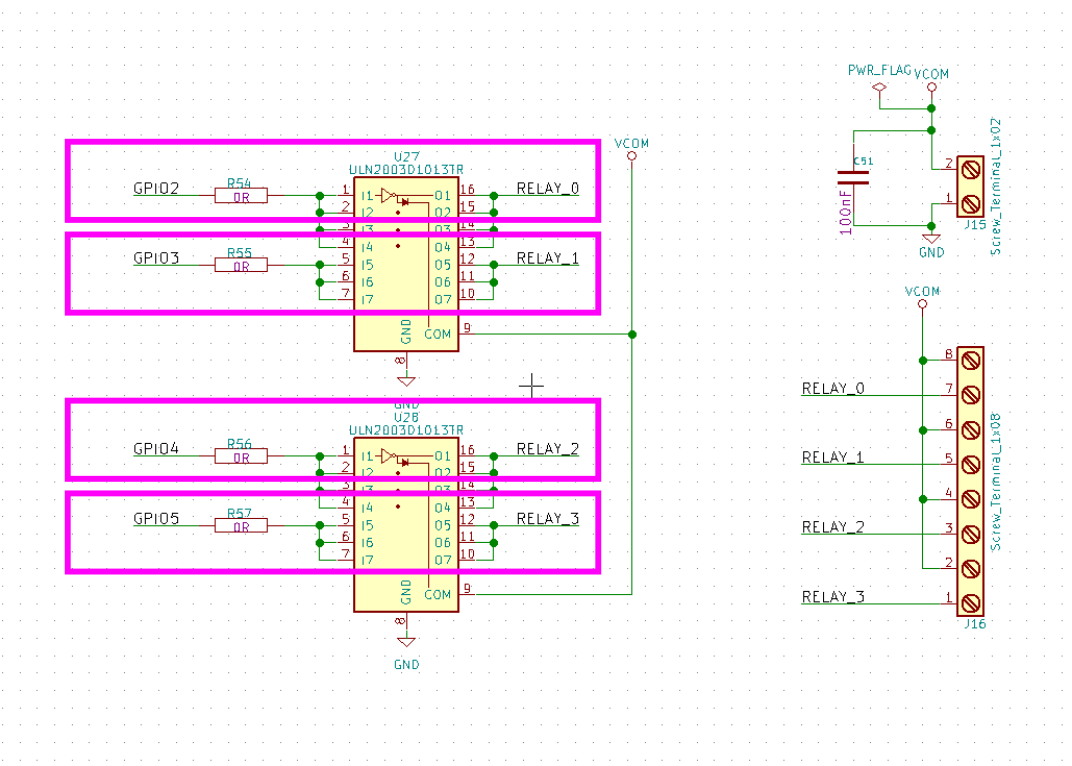
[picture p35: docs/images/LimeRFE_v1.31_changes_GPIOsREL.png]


  Figure 12. Remapped relay GPIOs 

J22 connector remapping:

GPIO5, GPIO3, GPIO3_CONN changed to GPIO1, GPIO5, GPIO5_CONN.

J12 connector remapping:

GPIO0, GPIO1, GPIO2, GPIO3_CONN, GPIO4, GPIO5 changed to GPIO0, GPIO1, GPIO2, GPIO3, GPIO4, GPIO5_CONN.

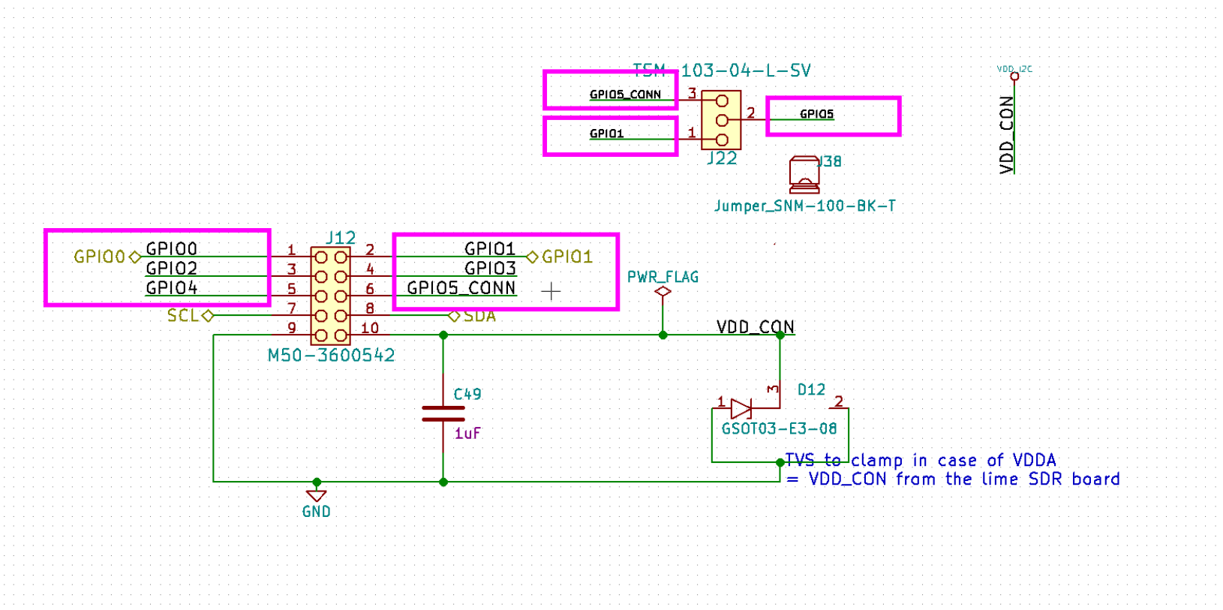
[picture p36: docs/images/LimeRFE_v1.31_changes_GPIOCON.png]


  Figure 13. Remapped GPIOs connector (J12)

v1.0
****

Initial version

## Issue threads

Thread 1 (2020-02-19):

Layout files missing

mpbraendli, 2020-02-19:
First of all, thanks a lot for making these design files public.

The Readme says `KiCAD schematic and layout files`, but there is no `.kicad_pcb` file. Is that intentional?

Closed 2020-12-01.

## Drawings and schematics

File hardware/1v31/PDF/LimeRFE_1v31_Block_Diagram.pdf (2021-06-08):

## 219 – 225 MHz

## 400 – 450 MHz

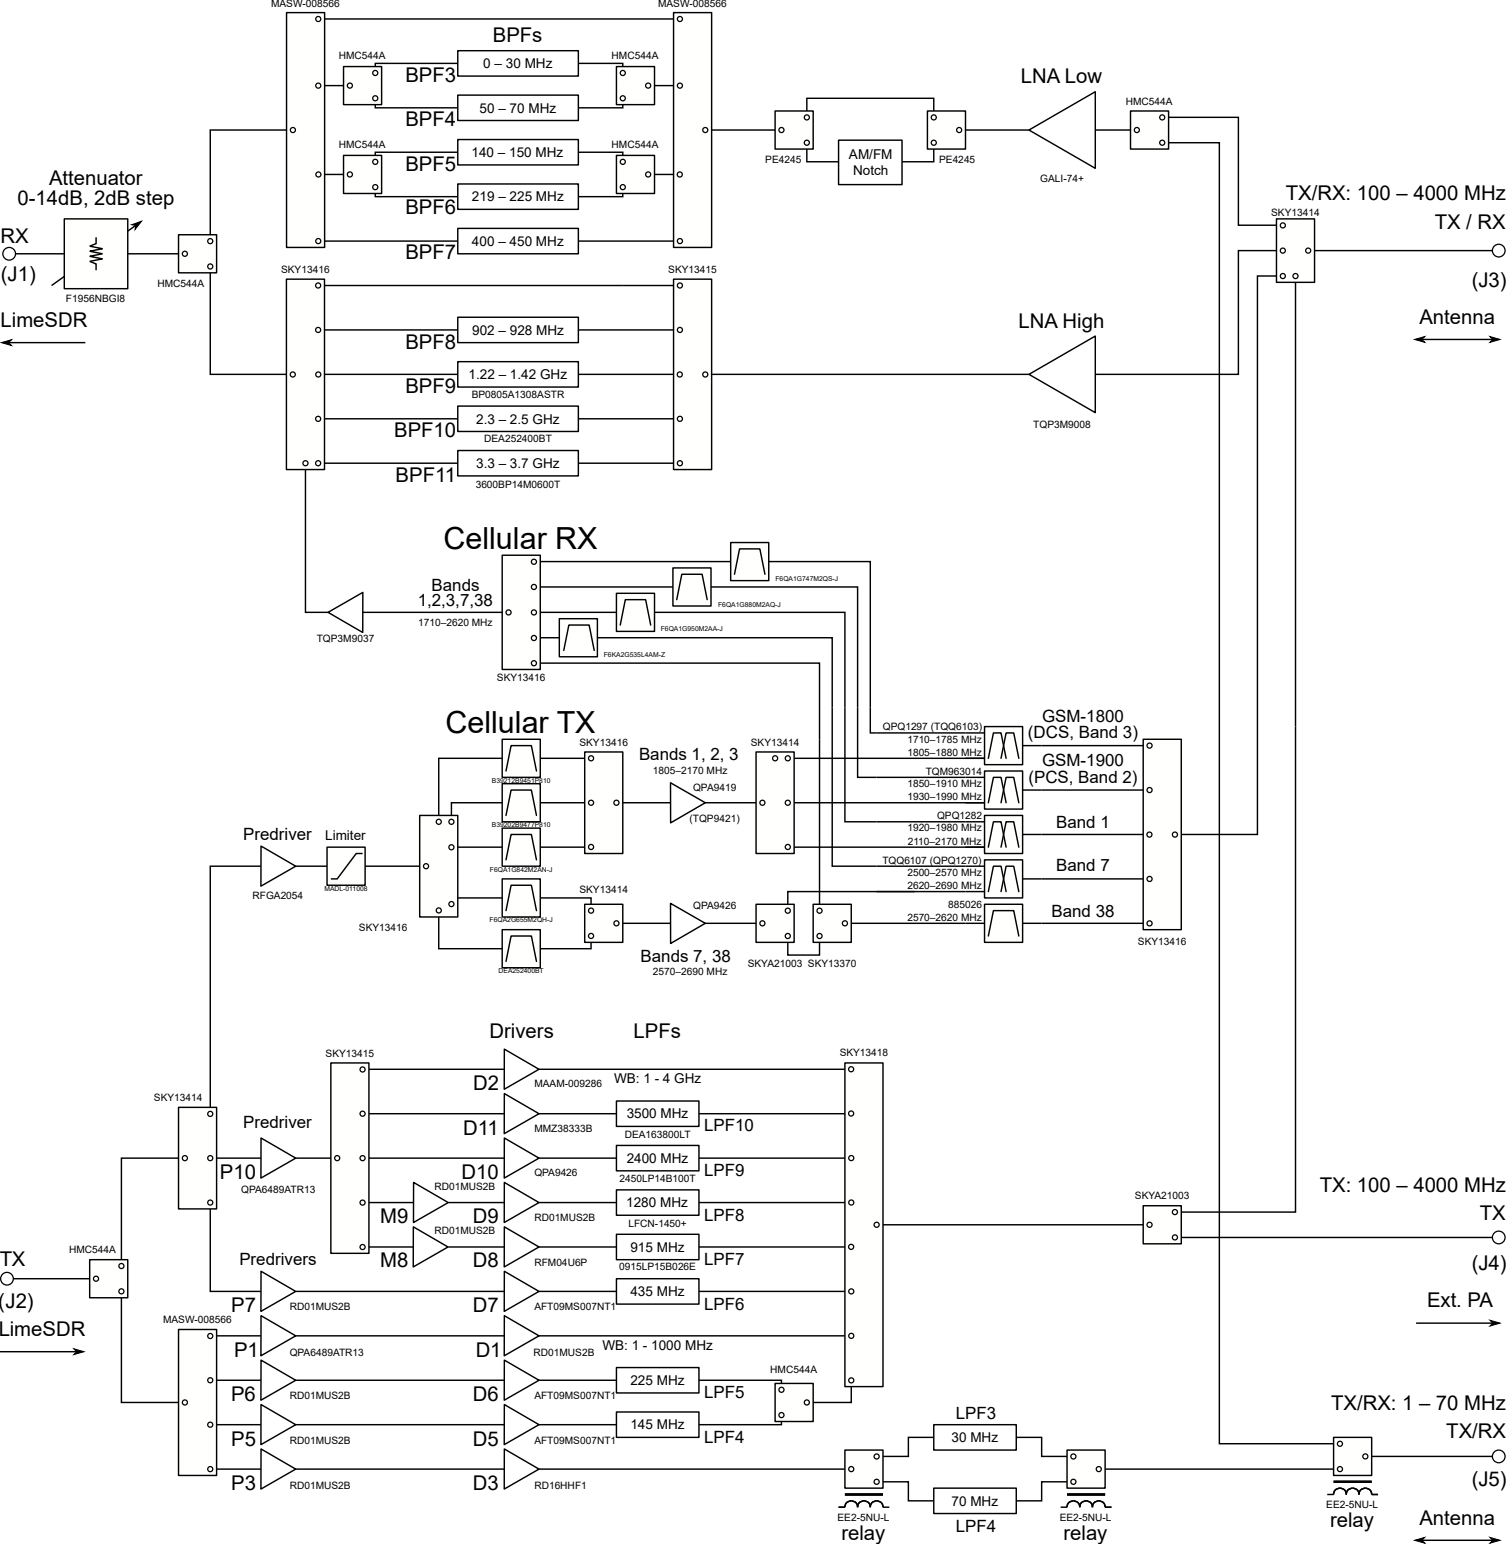
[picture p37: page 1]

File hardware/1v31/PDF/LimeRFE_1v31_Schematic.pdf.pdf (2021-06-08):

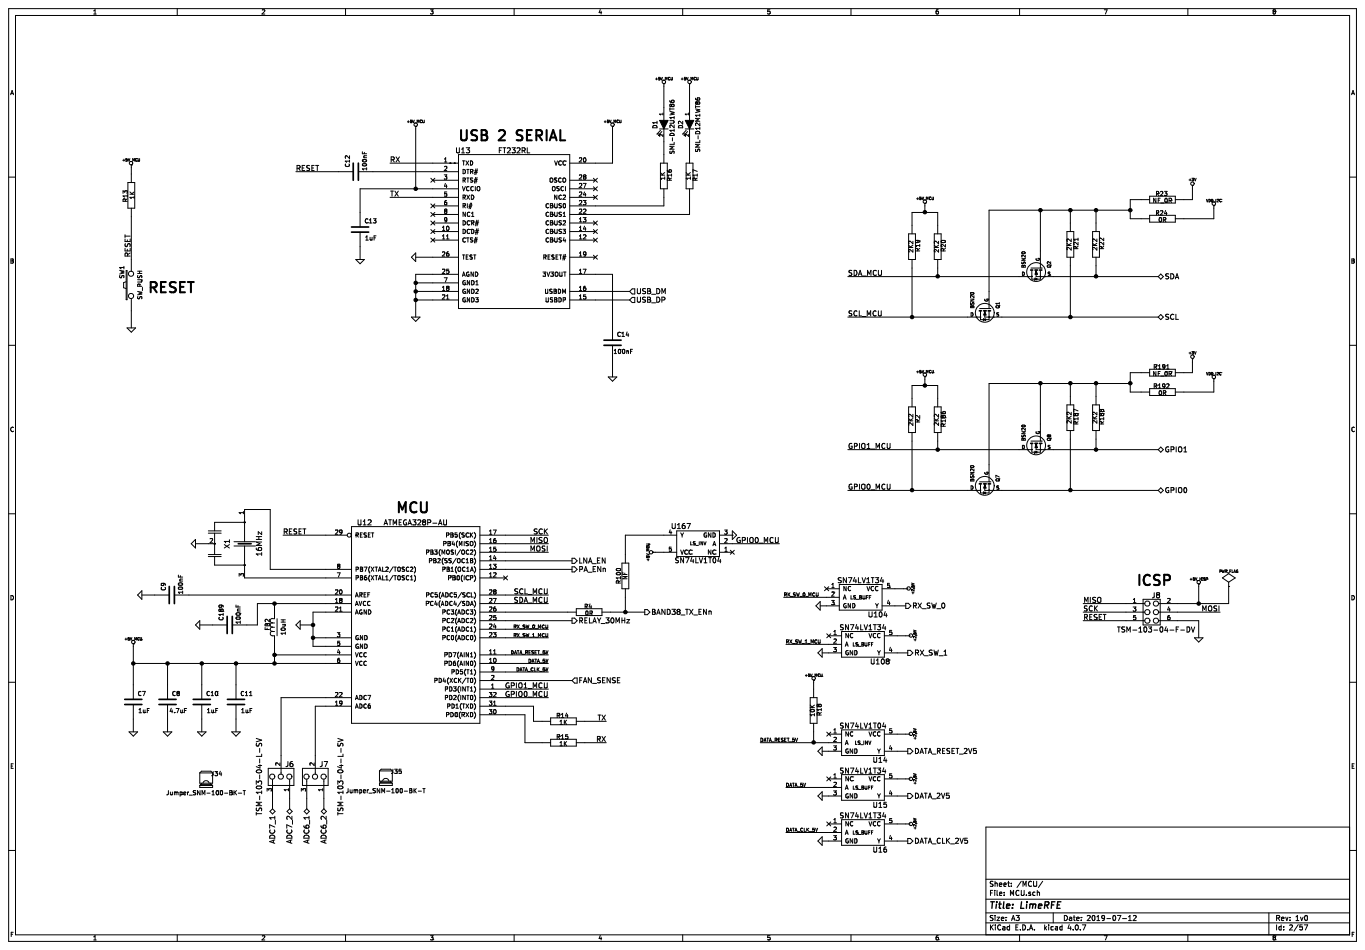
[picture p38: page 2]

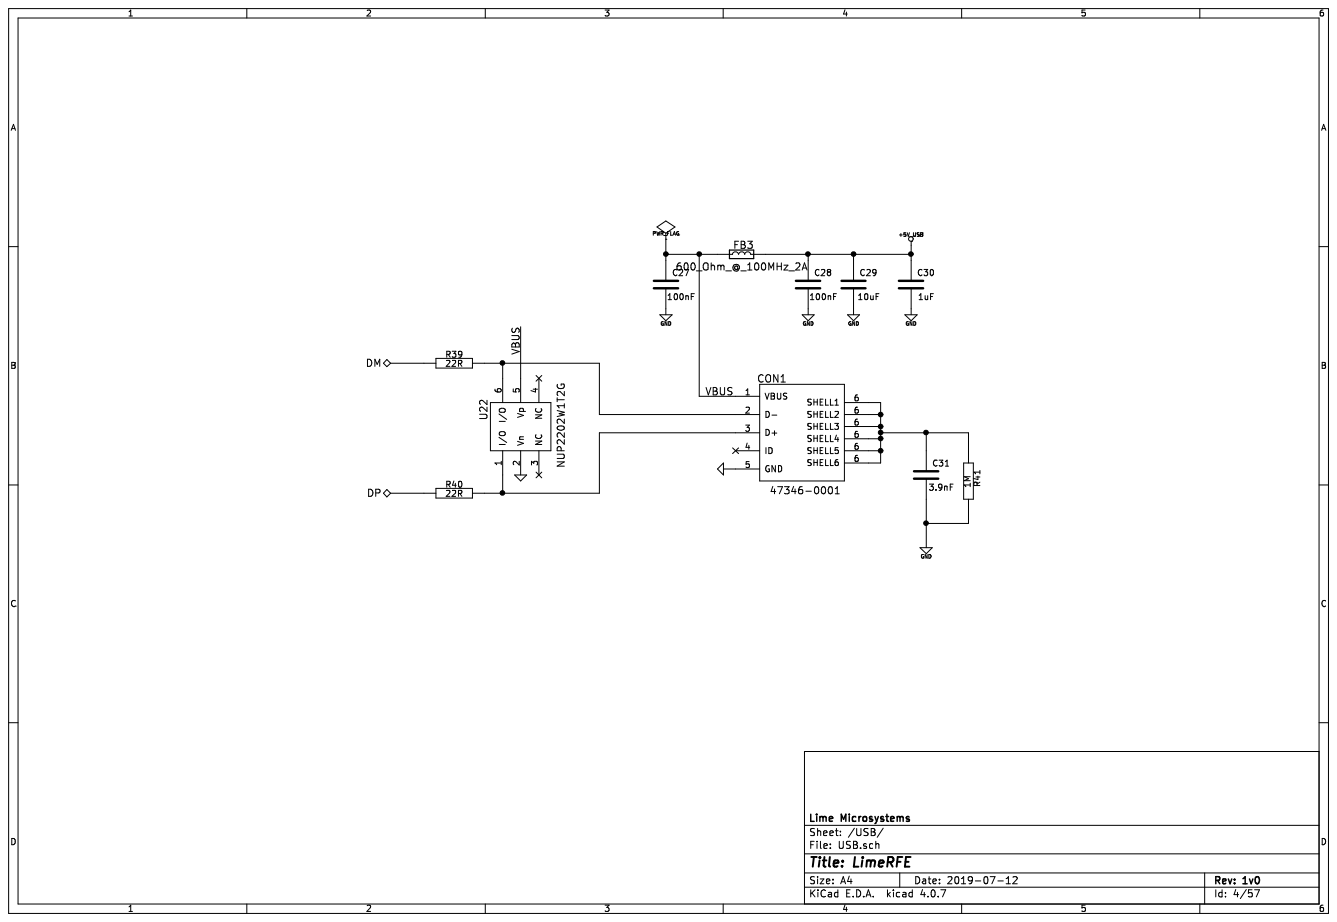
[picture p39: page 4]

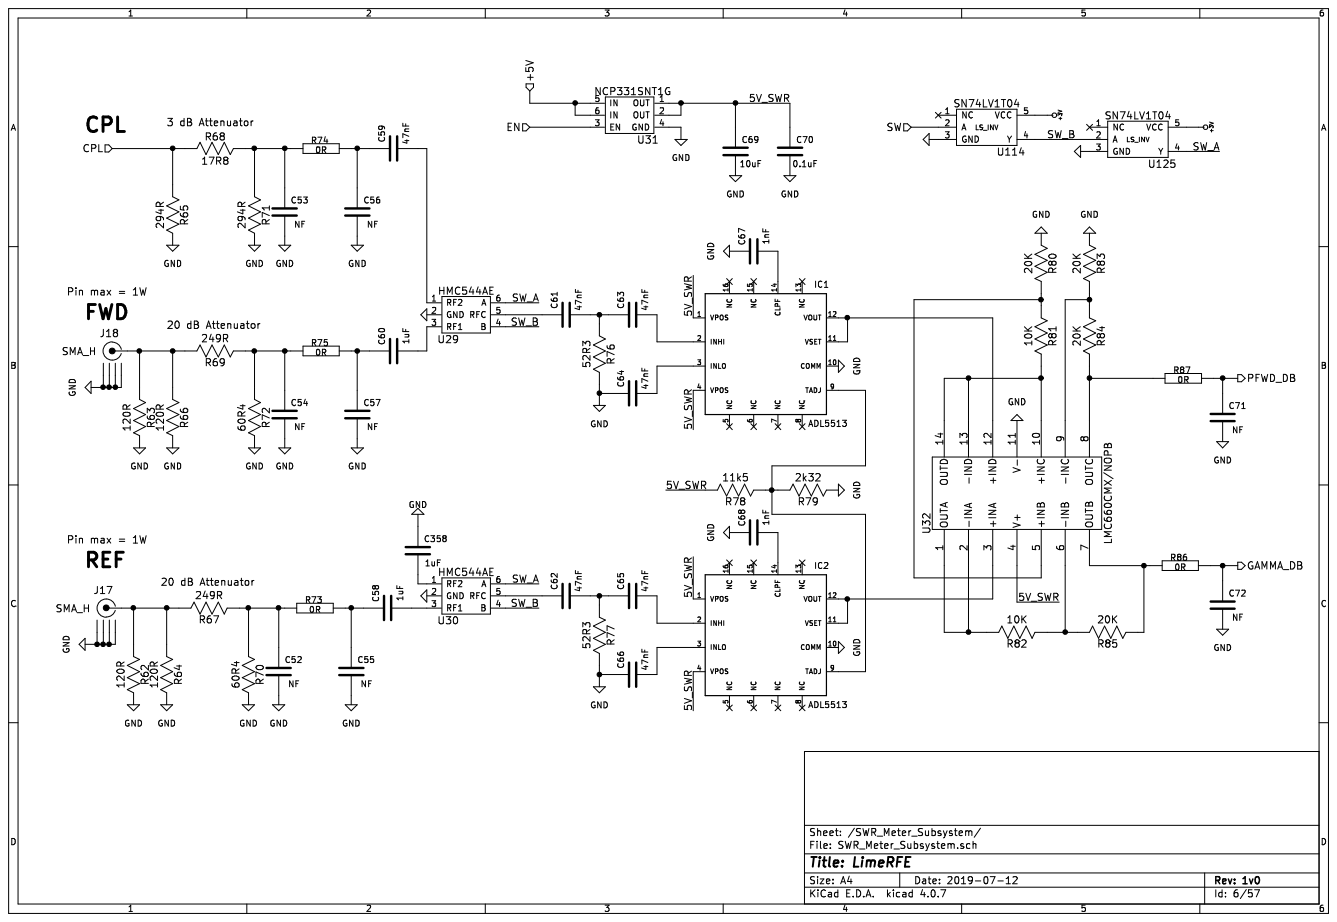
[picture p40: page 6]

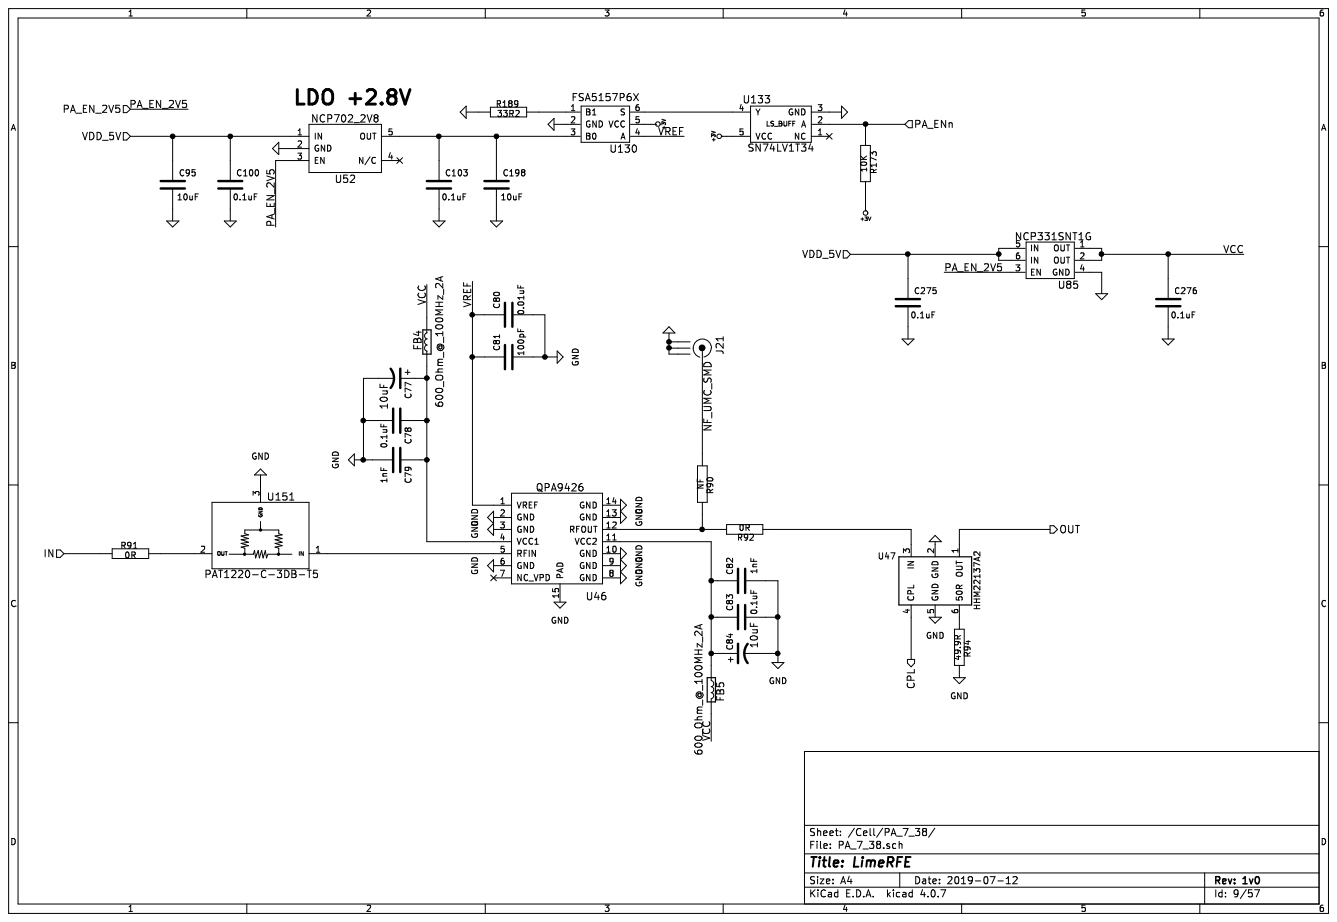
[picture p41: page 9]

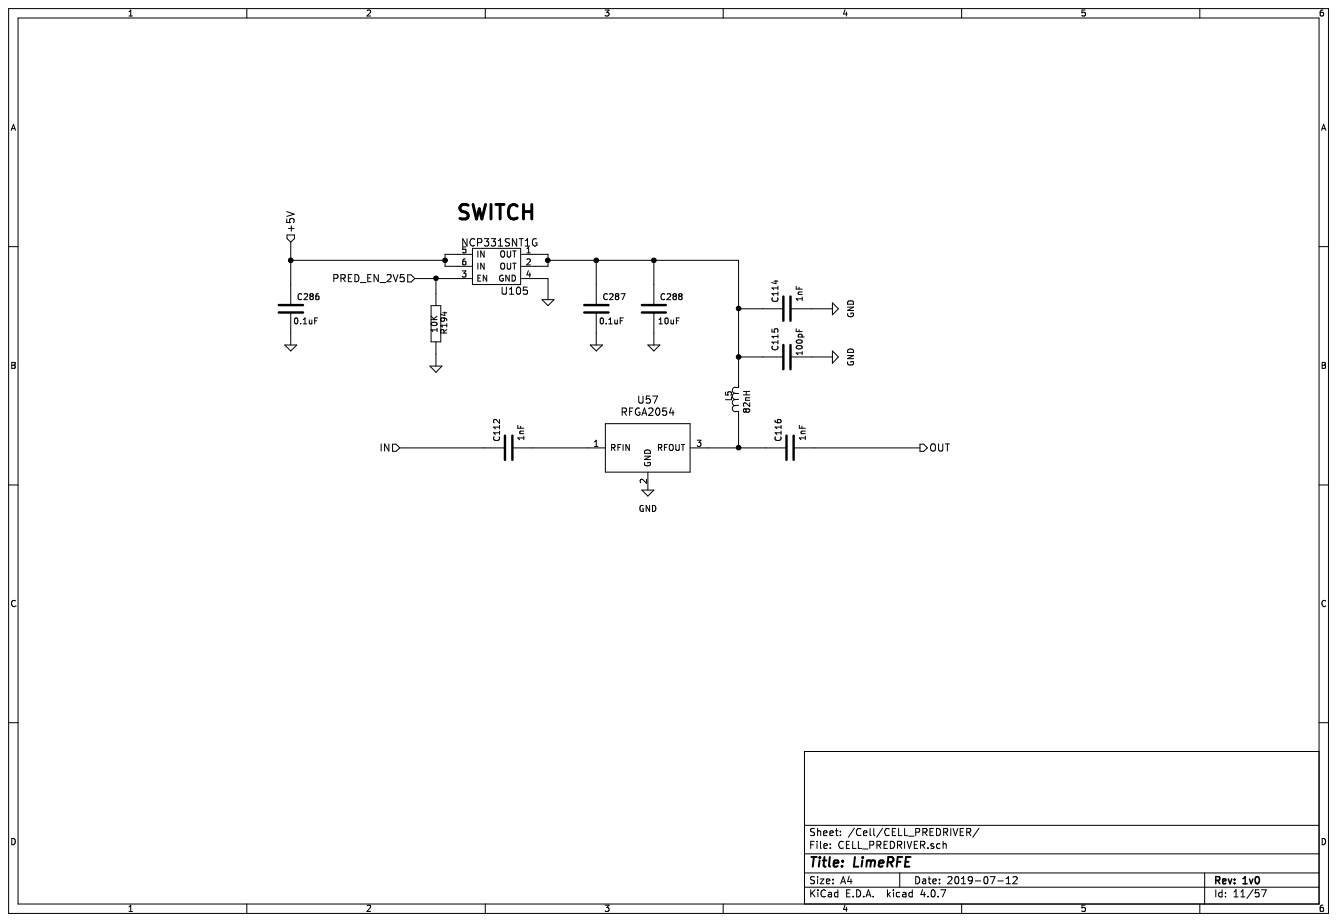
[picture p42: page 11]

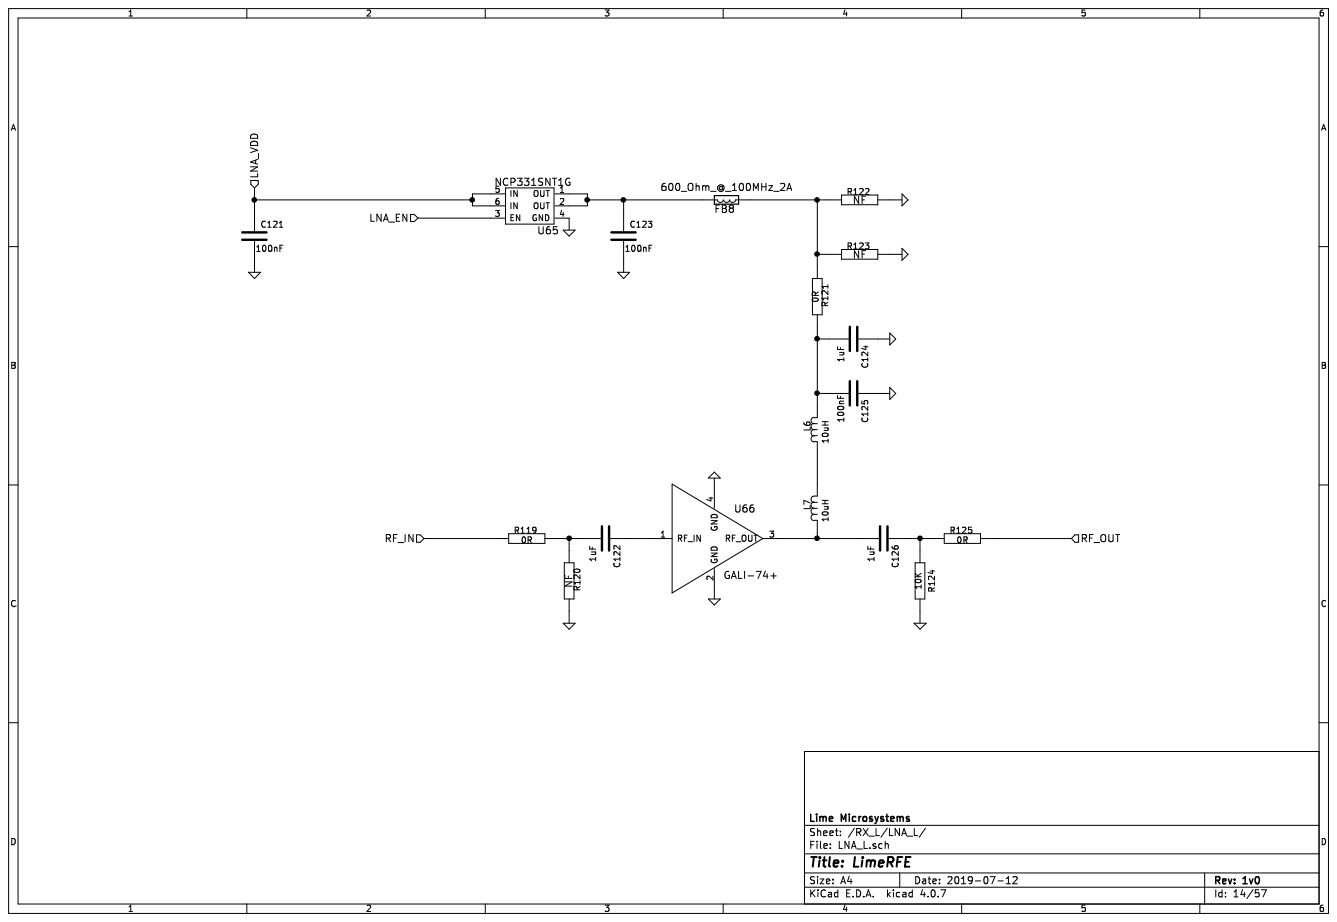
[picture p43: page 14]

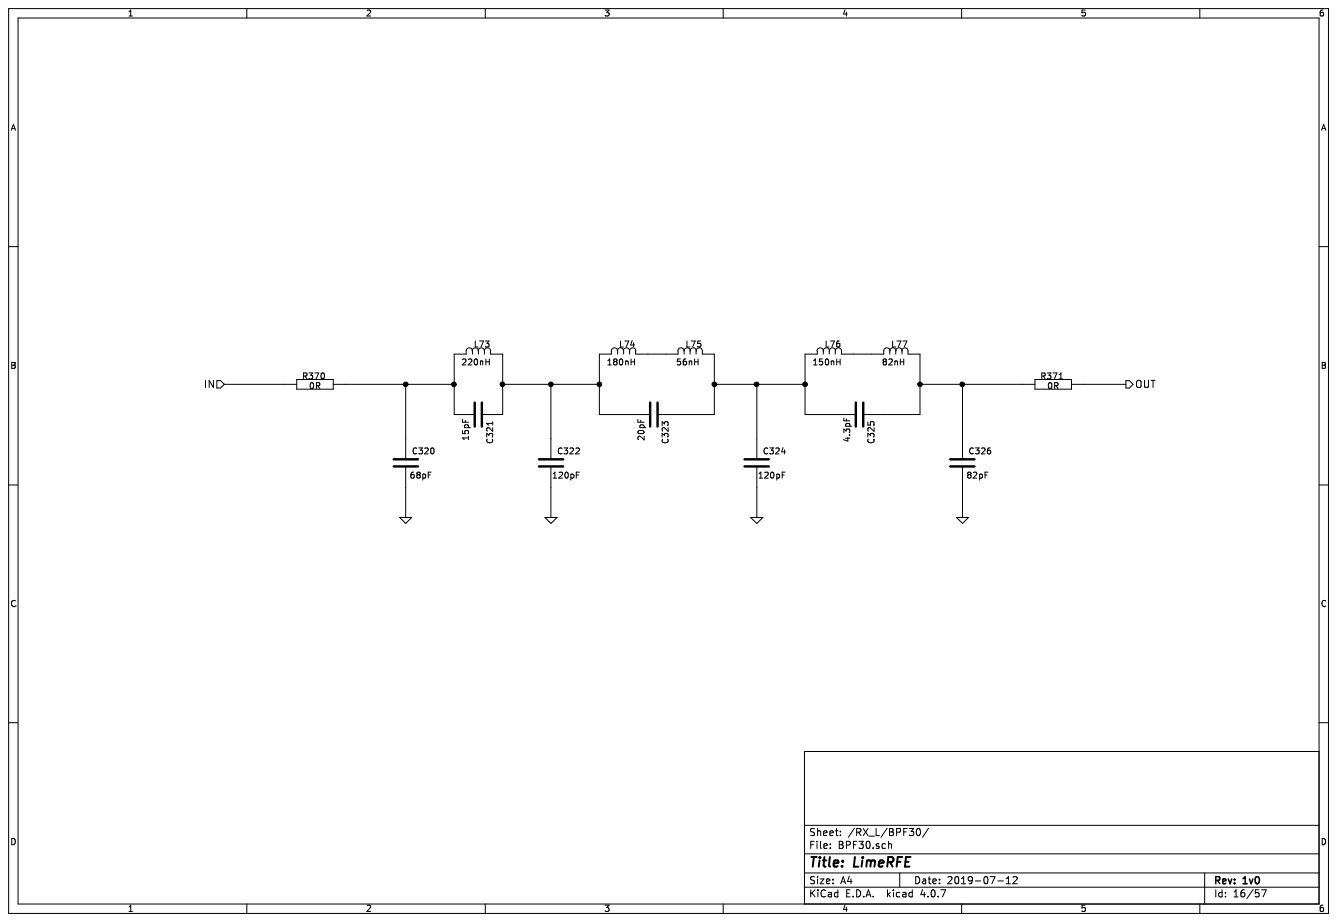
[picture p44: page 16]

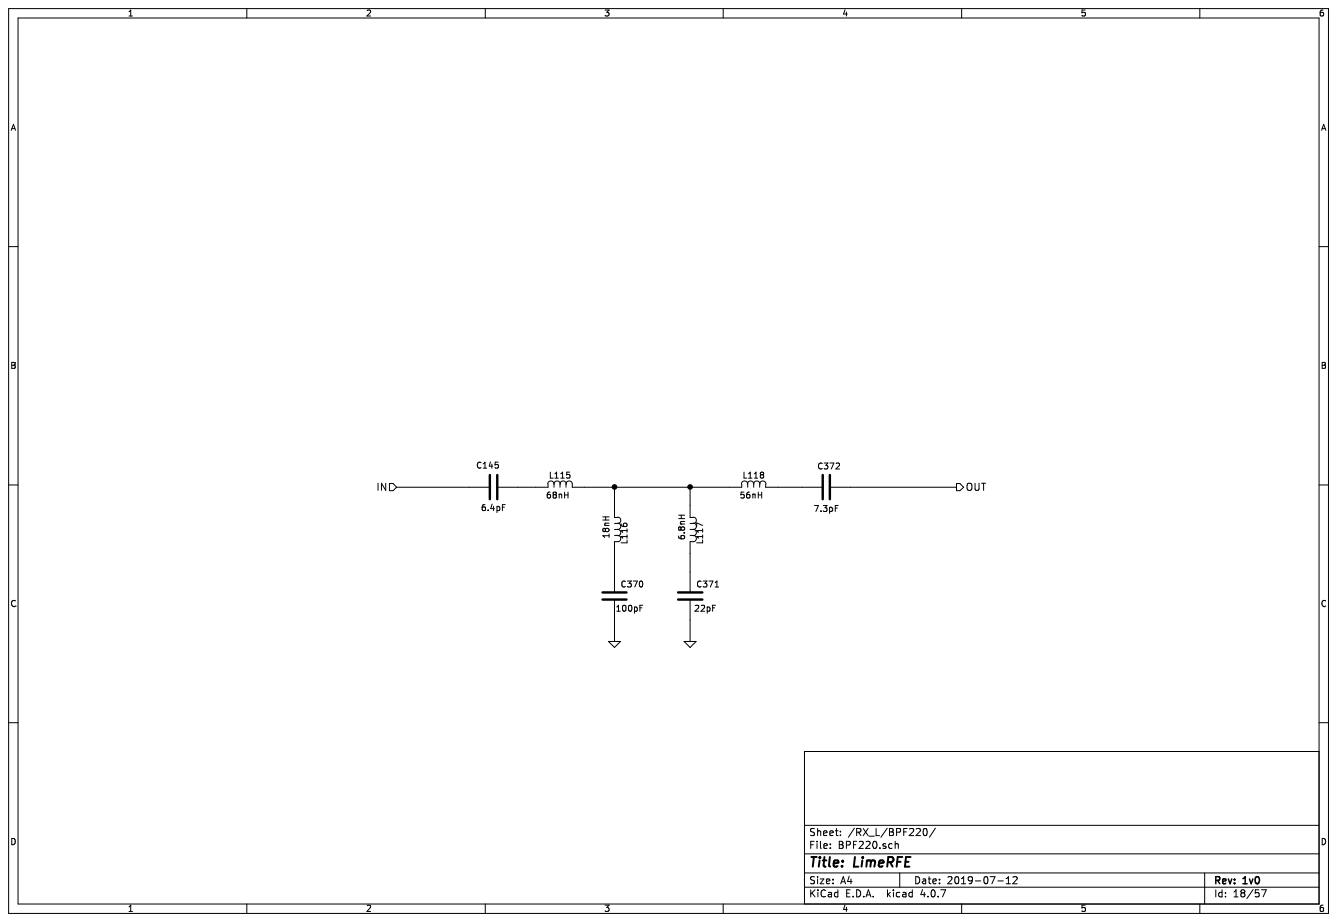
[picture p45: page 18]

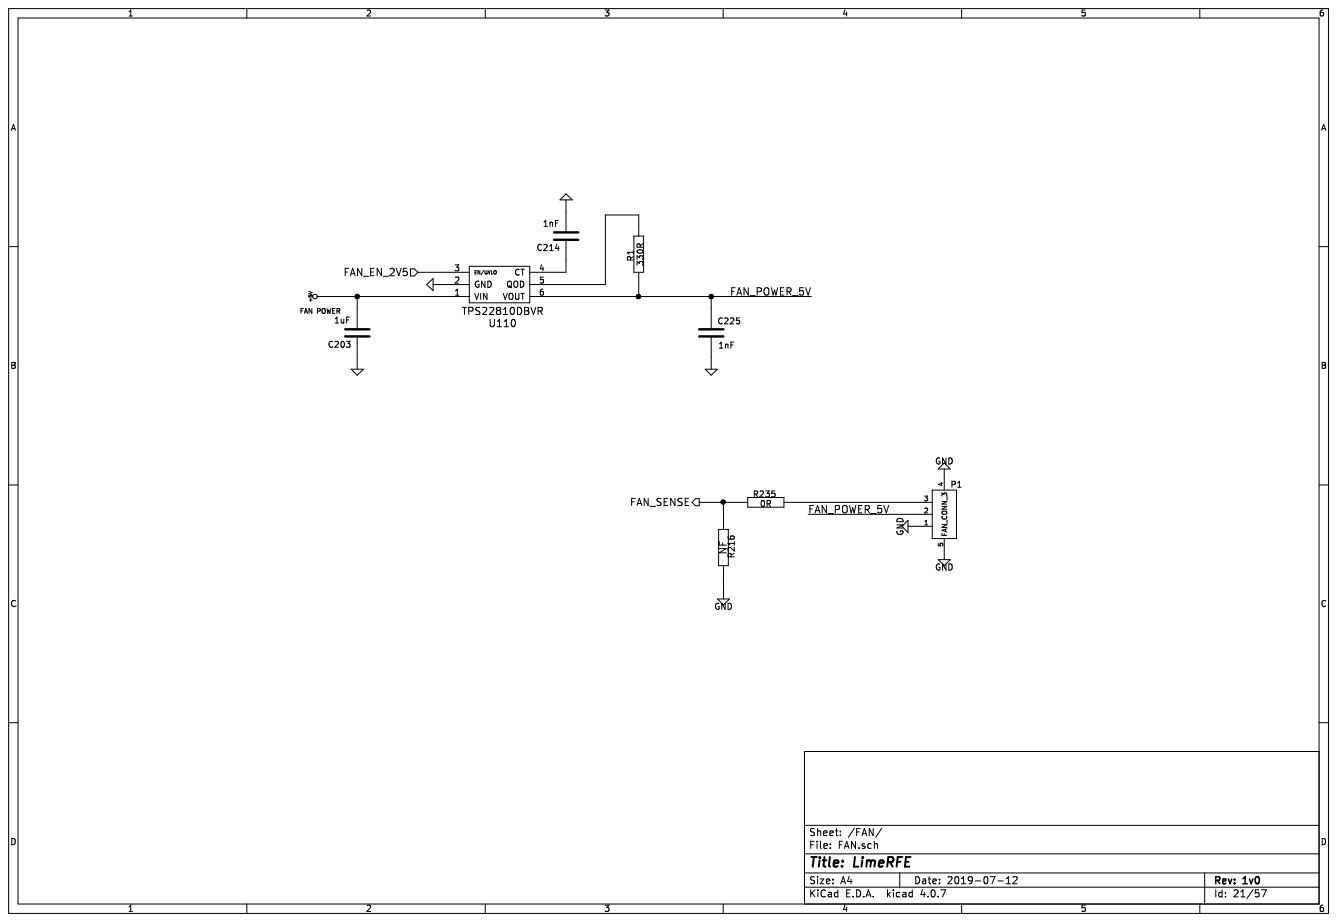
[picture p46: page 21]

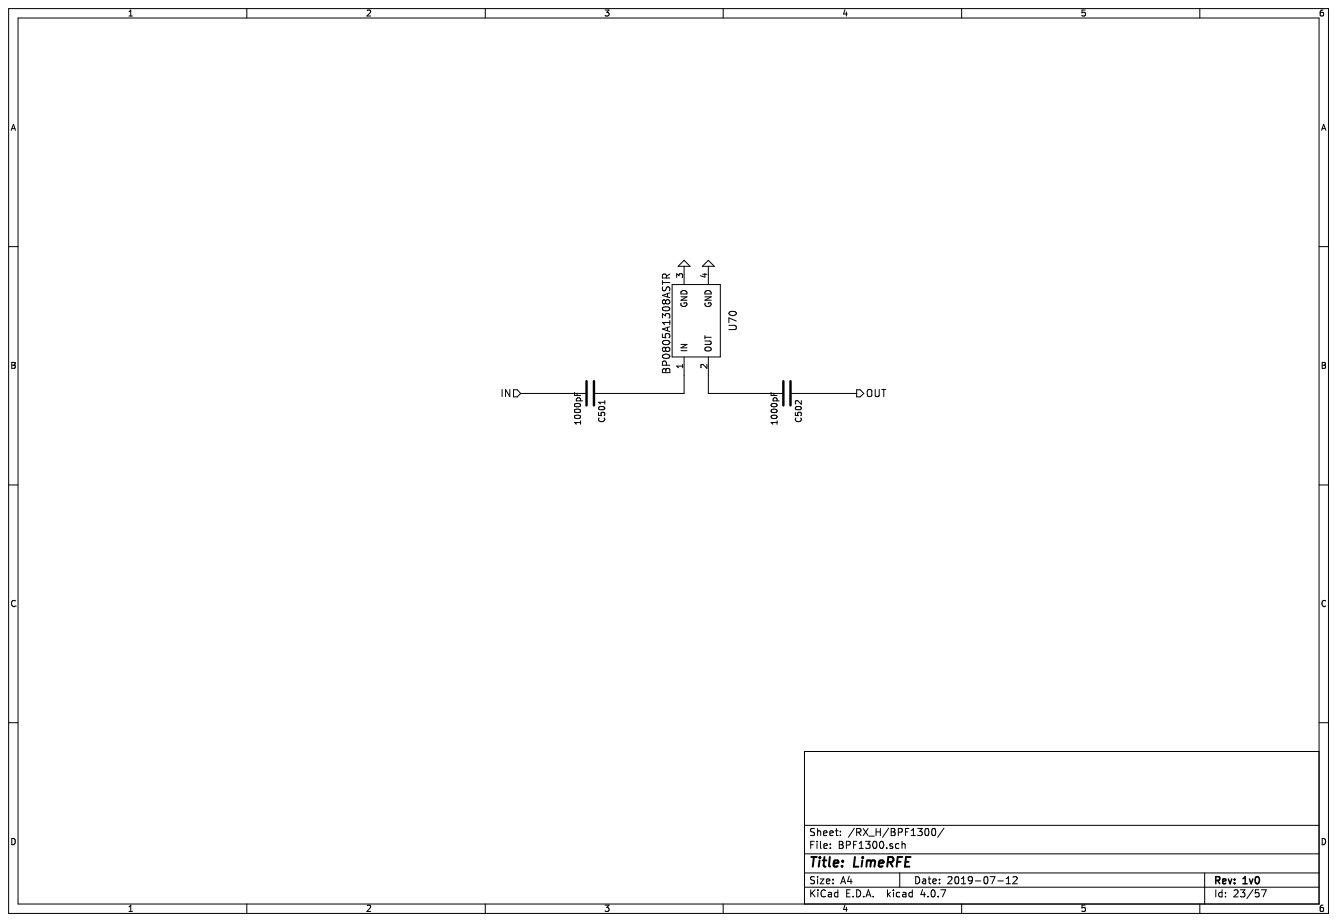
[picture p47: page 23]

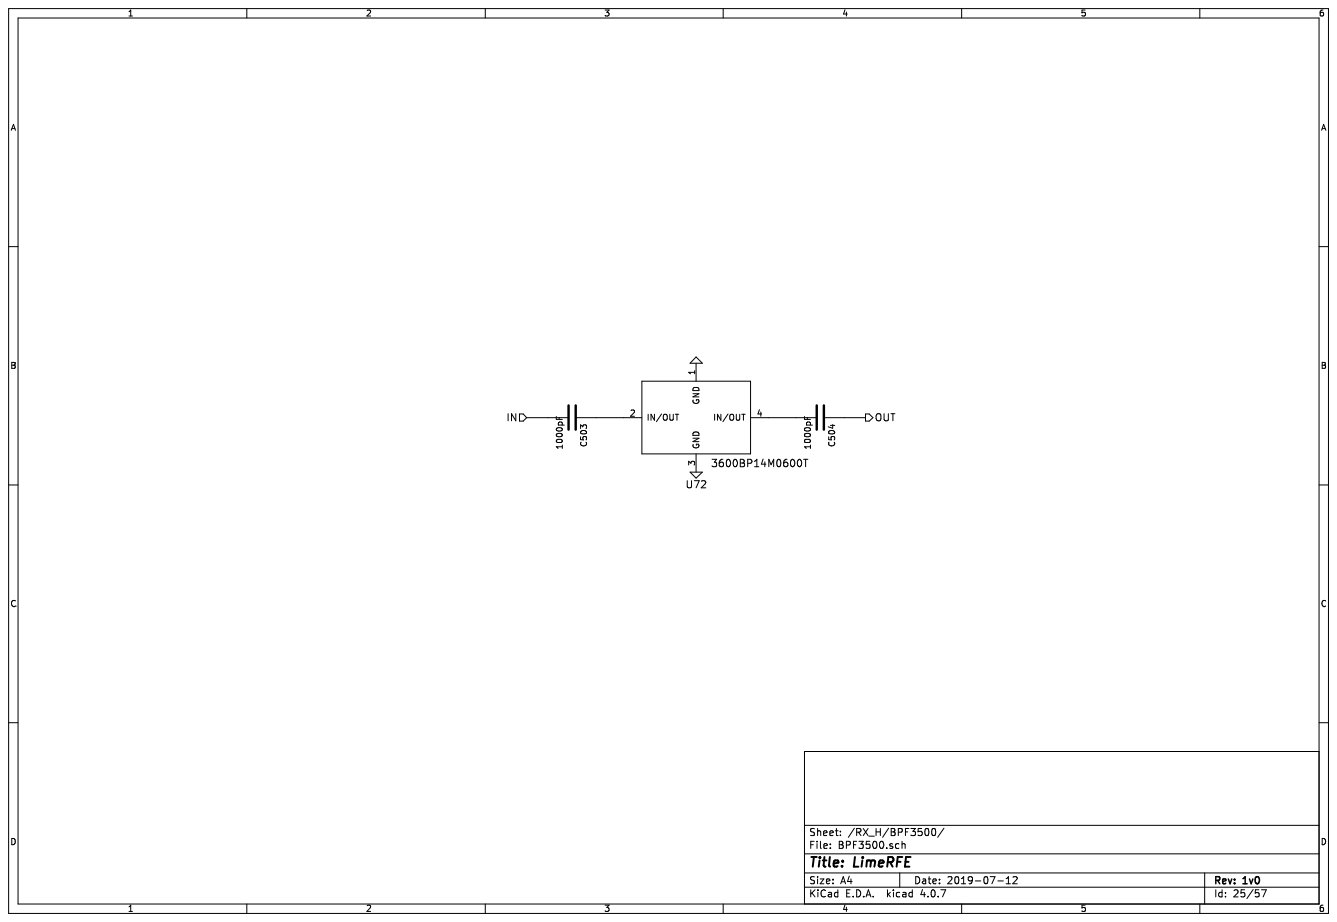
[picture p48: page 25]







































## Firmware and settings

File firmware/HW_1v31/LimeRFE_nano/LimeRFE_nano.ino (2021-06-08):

#include <Wire.h>
#include "mcu.h"
#include "chain.h"
#include "cmd.h"
#include "errorCode.h"

#define I2C_ADDRESS       0x51 // Random pick, change if needed

bool isMaster;

unsigned char activeBuffer[BUFFER_SIZE];
unsigned char activeBufferSize = BUFFER_SIZE;
unsigned char activeState[STATE_SIZE];
unsigned char nextState[STATE_SIZE];

unsigned char activeRxChannelID = CID_WB_1000;        // wb1000
unsigned char activeTxChannelID = CID_WB_1000;        // wb1000
unsigned char activeRxConn = CONN_TXRX;               // J3
unsigned char activeTxConn = CONN_TX;                 // J4
unsigned char activeAttenuation = 0x00;               // 0
unsigned char activeNotch = 0x00;                     // 0
unsigned char activeSwrEn = 0x00;                     // 0
unsigned char activeSwrSrc = 0x00;                    // 0
unsigned char activeMode = RFE_MODE_NONE;             // RFE_MODE_NONE
unsigned char activeFan = 0x00;                          // FAN_OFF

void setup() {

  isMaster = false; // Board is slave by default
  
  // initialize serial communication at 9600 bits per second:
  Serial.begin(9600);
  
  Wire.begin(I2C_ADDRESS); // join i2c bus with address #I2C_ADDRESS
  
  Wire.onReceive(receiveEvent); // register event
  Wire.onRequest(requestEvent); // register event
  
  // Configure pins
  pinMode(GPIO0_PIN, INPUT);
  pinMode(GPIO1_PIN, INPUT);
  pinMode(RELAY_PIN, OUTPUT);
  pinMode(RX_SW_PIN0, OUTPUT);
  pinMode(RX_SW_PIN1, OUTPUT);
  pinMode(DATA_RESET_PIN, OUTPUT);
  pinMode(DATA_PIN, OUTPUT);
  pinMode(DATA_CLK_PIN, OUTPUT);
  pinMode(FAN_SENSE_PIN, INPUT);
  pinMode(RX_SW_PIN1, OUTPUT);
  pinMode(LNA_EN_PIN, OUTPUT);
  pinMode(PA_ENn_PIN, OUTPUT);
  pinMode(ADC1_PIN, INPUT);
  pinMode(ADC2_PIN, INPUT);
  pinMode(BAND38_TX_ENn_PIN, OUTPUT);

  attachInterrupt(digitalPinToInterrupt(GPIO1_PIN), band38, CHANGE);
  
  setDefaults();
}

void band38() {
  digitalWrite(BAND38_TX_ENn_PIN, digitalRead(GPIO1_PIN));
}

void setDefaults(){

  digitalWrite(DATA_RESET_PIN, DATA_RESET);  // reset all shift registers
  digitalWrite(DATA_RESET_PIN, DATA_RESETn);

  configureState(CID_WB_1000, CID_WB_1000, CONN_TXRX, CONN_TX, 0x00, 0x00, 0x00, 0x00);  // set defaults
  setMode(RFE_MODE_NONE);

}

void loop() {
  if (Serial.available()) {
    Serial.readBytes(activeBuffer, 1);
    if (activeBuffer[0] == CMD_HELLO){
      while(Serial.read() >= 0){} // flush the receive buffer
      Serial.write(CMD_HELLO);
      // Blink twice if synchronized
      delay(100);
    } else {
      unsigned char command;
      command = activeBuffer[0];
      if (command == CMD_MODE || command == CMD_FAN) {       // cmd_mode and cmd_fan are shorter
          activeBufferSize = BUFFER_SIZE_MODE;
      } else {
          activeBufferSize = BUFFER_SIZE;
      }
      wait_for_bytes(activeBufferSize - 1, 1000);
      Serial.readBytes(activeBuffer + 1, activeBufferSize - 1);
      doCommand();
      activeBuffer[0] = command;
      
      Serial.write(activeBuffer,activeBufferSize);
      
    }
  }
}

void doCommand(){
  switch(activeBuffer[0]) {
    case CMD_CONFIG_FULL: {
        disableLNAs();                              // Disable LNAs
        disablePAs();                               // Disable PAs
        
        shiftData(activeBuffer + 1, CHAIN_SIZE, activeState);   // Shift Chain Data
        setupMCU(activeBuffer[CHAIN_SIZE + 1], activeState);    // 
        
        break;
      }
    case CMD_MODE_FULL: {
        setupMCU(activeBuffer[1], activeState);
        break;
      }
    case CMD_CONFIG:  {
        unsigned char err = configureState(activeBuffer[1], activeBuffer[2], activeBuffer[3], activeBuffer[4], activeBuffer[6], activeBuffer[7], activeBuffer[8], activeBuffer[9]);
        if (err == COMPLETED){
            err = setMode(activeBuffer[5]);
        }
        clearBuffer();
        activeBuffer[1] = err;
        break;
      }
    case CMD_MODE:  {
        unsigned char err = setMode(activeBuffer[1]);
        clearBuffer();
        activeBuffer[1] = err;
        break;
      }
    case CMD_FAN:  {
        activeFan = activeBuffer[1];
        memcpy(nextState, activeState, sizeof(activeState[0])*CHAIN_SIZE);
        (activeFan == 1) ? nextState[FAN_BYTE -1] |= (1 << FAN_BIT) : nextState[FAN_BYTE - 1] &= ~(1 << FAN_BIT);
        //////// shift data
        shiftData(nextState, CHAIN_SIZE, activeState);   // Shift Chain Data
        break;
      }
    case CMD_READ_ADC2: {
        clearBuffer();
        int adcValue = analogRead(ADC1_PIN);
        activeBuffer[1] = lowByte(adcValue);
        activeBuffer[2] = highByte(adcValue);
        break;
      }    
    case CMD_READ_ADC1: {
        clearBuffer();
        int adcValue = analogRead(ADC2_PIN);
        activeBuffer[1] = lowByte(adcValue);
        activeBuffer[2] = highByte(adcValue);
        break;
      }
    case CMD_READ_TEMP: {
        clearBuffer();
        int tempValue = round(conv_temp(read_temp()));
        activeBuffer[1] = highByte(tempValue);
        activeBuffer[2] = lowByte(tempValue);
        break;
      }
    case CMD_GET_CONFIG_FULL: {
        clearBuffer();
        memcpy(activeBuffer + 1, activeState, sizeof(activeState[0])*STATE_SIZE);
        break;
      }
    case CMD_GET_CONFIG:  {
        clearBuffer();
        activeBuffer[1] = activeRxChannelID;
        activeBuffer[2] = activeTxChannelID;
        activeBuffer[3] = activeRxConn;
        activeBuffer[4] = activeTxConn;
        activeBuffer[5] = activeMode;                         // mode
        activeBuffer[6] = activeNotch;
        activeBuffer[7] = activeAttenuation;
        activeBuffer[8] = activeSwrEn;
        activeBuffer[9] = activeSwrSrc;
        activeBuffer[10] = activeFan;
        break;
      }
    case CMD_CONFGPIO10:  {
        configGPIO10(activeBuffer[1], activeBuffer[2]);
        break;
      }    
    case CMD_SETGPIO10:  {
        setGPIO10(activeBuffer[1], activeBuffer[2]);
        break;
      }
    case CMD_GETGPIO10:  {
        char pin = activeBuffer[1];
        clearBuffer();
        activeBuffer[1] = getGPIO10(pin);
        break;
      }
    case CMD_GET_INFO: {
        clearBuffer();  
        activeBuffer[1] = 0x01;    // FW_VER
        activeBuffer[2] = 0x10; // HW_VER
        activeBuffer[3] = 1;    // Status
        activeBuffer[4] = 1;    // Status
        break;
      }
    case CMD_RESET: {
        setDefaults();
        break;
      }
    default:  {
        clearBuffer();
      }
  }
}

void clearBuffer(){
  for (int i=0; i<BUFFER_SIZE; i++){
      activeBuffer[i] = 0x0;
  }
}

unsigned char configureState(unsigned char rxChannelID, unsigned char txChannelId, unsigned char rxConn, unsigned char txConn, unsigned char notch, unsigned char attenuation, unsigned char swrEn, unsigned char swrSrc){
  switch(rxConn){
      case CONN_DEFAULT:{
        if (rxChannelID == CID_HAM_0030 || rxChannelID == CID_HAM_0070){
          rxConn = CONN_30;
        } else {
          rxConn = CONN_TXRX;
        }
        break;
      }
      case CONN_TXRX:{
        break;
      }
      case CONN_TX:{
          // error
          return ERROR_RX_CONN;
        break;
      }
      case CONN_30:{
        if (isRxH(rxChannelID) || isCell(rxChannelID)){
          // error
          return ERROR_RX_CONN;
        }
        break;
      }
      default: {
        // error
        return ERROR_RX_CONN;
        break;
      }
  }
  
  switch(txConn){
      case CONN_DEFAULT:{
        if (txChannelId == CID_HAM_0030 || txChannelId == CID_HAM_0070){
          txConn = CONN_30;
        } else {
          txConn = CONN_TXRX;
        }
        break;
      }
      case CONN_TXRX:{
        if (txChannelId == CID_HAM_0030 || txChannelId == CID_HAM_0070){
          // error
          return ERROR_TX_CONN;
        }
        break;
      }
      case CONN_TX:{
        if (txChannelId == CID_HAM_0030 || txChannelId == CID_HAM_0070 || isCell(txChannelId)){
          // error
          return ERROR_TX_CONN;
        }
        break;
      }
      case CONN_30:{
        if (txChannelId != CID_HAM_0030 && txChannelId != CID_HAM_0070 ){
          // error
          return ERROR_TX_CONN;
        }
        break;
      }
      default: {
        // error
        return ERROR_TX_CONN;
        break;
      }
  }
  
  switch(rxChannelID){
    case CID_WB_1000: {
        memcpy(nextState, STATE_HAMWB1, sizeof(STATE_HAMWB1[0])*CHAIN_SIZE);
        break;
      }
    case CID_WB_4000: {
        memcpy(nextState, STATE_HAMWB2, sizeof(STATE_HAMWB2[0])*CHAIN_SIZE);
        break;
      }
    case CID_HAM_0030:  {
        memcpy(nextState, STATE_HAM30, sizeof(STATE_HAM30[0])*CHAIN_SIZE);
        break;
      }    
    case CID_HAM_0070:  {
        memcpy(nextState, STATE_HAM70, sizeof(STATE_HAM70[0])*CHAIN_SIZE);
        break;
      }
    case CID_HAM_0145:  {
        memcpy(nextState, STATE_HAM145, sizeof(STATE_HAM145[0])*CHAIN_SIZE);
        break;
      }
    case CID_HAM_0220:  {
        memcpy(nextState, STATE_HAM220, sizeof(STATE_HAM220[0])*CHAIN_SIZE);
        break;
      }
    case CID_HAM_0435:  {
        memcpy(nextState, STATE_HAM435, sizeof(STATE_HAM435[0])*CHAIN_SIZE);
        break;
      }
    case CID_HAM_0920:  {
        memcpy(nextState, STATE_HAM920, sizeof(STATE_HAM920[0])*CHAIN_SIZE);
        break;
      }
    case CID_HAM_1280:  {
        memcpy(nextState, STATE_HAM1280, sizeof(STATE_HAM1280[0])*CHAIN_SIZE);
        break;
      }
    case CID_HAM_2400:  {
        memcpy(nextState, STATE_HAM2400, sizeof(STATE_HAM2400[0])*CHAIN_SIZE);
        break;
      }
    case CID_HAM_3500:  {
        memcpy(nextState, STATE_HAM3500, sizeof(STATE_HAM3500[0])*CHAIN_SIZE);
        break;
      }
    case CID_CELL_BAND01: {
        memcpy(nextState, STATE_CELLB01, sizeof(STATE_CELLB01[0])*CHAIN_SIZE);
        break;
      }
    case CID_CELL_BAND02: {
        memcpy(nextState, STATE_CELLB02, sizeof(STATE_CELLB02[0])*CHAIN_SIZE);
        break;
      }
    case CID_CELL_BAND03: {
        memcpy(nextState, STATE_CELLB03, sizeof(STATE_CELLB03[0])*CHAIN_SIZE);
        break;
      }
    case CID_CELL_BAND07: {
        memcpy(nextState, STATE_CELLB07, sizeof(STATE_CELLB07[0])*CHAIN_SIZE);
        break;
      }
    case CID_CELL_BAND38: {
        memcpy(nextState, STATE_CELLB38, sizeof(STATE_CELLB38[0])*CHAIN_SIZE);
        break;
      }
    default: {
        return ERROR_WRONG_CHANNEL_CODE;
        break;
      }
  }

  if(isCell(rxChannelID) || isCell(txChannelId)) {       
      if(txChannelId != rxChannelID){
          return ERROR_CELL_TX_NOT_EQUAL_RX;
      }
  } else {
      switch(txChannelId){
        case CID_WB_1000: {
            setTxState(nextState, STATE_HAMWB1);
            break;
          }
        case CID_WB_4000: {
            setTxState(nextState, STATE_HAMWB2);
            break;
          }
        case CID_HAM_0030:  {
            setTxState(nextState, STATE_HAM30);
            break;
          }
        case CID_HAM_0070:  {
            setTxState(nextState, STATE_HAM70);
            break;
          }
        case CID_HAM_0145:  {
            setTxState(nextState, STATE_HAM145);
            break;
          }
        case CID_HAM_0220:  {
            setTxState(nextState, STATE_HAM220);
            break;
          }
        case CID_HAM_0435:  {
            setTxState(nextState, STATE_HAM435);
            break;
          }
        case CID_HAM_0920:  {
            setTxState(nextState, STATE_HAM920);
            break;
          }
        case CID_HAM_1280:  {
            setTxState(nextState, STATE_HAM1280);
            break;
          }
        case CID_HAM_2400:  {
            setTxState(nextState, STATE_HAM2400);
            break;
          }
        case CID_HAM_3500:  {
            setTxState(nextState, STATE_HAM3500);
            break;
          }
        default: {
            return ERROR_WRONG_CHANNEL_CODE;
            break;
          }
      }
  }
  
  //////// set notch
  unsigned char notchBit;
  
  if (notch == NOTCH_VALUE_ON)
    notchBit = NOTCH_BIT_ON;
  else
    notchBit = NOTCH_BIT_OFF;
    
  (notchBit == 1) ? nextState[NOTCH_BYTE -1] |= (1 << NOTCH_BIT) : nextState[NOTCH_BYTE - 1] &= ~(1 << NOTCH_BIT);

  (swrEn == 1) ? nextState[SWR_EN_BYTE -1] |= (1 << SWR_EN_BIT) : nextState[SWR_EN_BYTE - 1] &= ~(1 << SWR_EN_BIT);

  (swrSrc == 1) ? nextState[SWR_SRC_BYTE -1] |= (1 << SWR_SRC_BIT) : nextState[SWR_SRC_BYTE - 1] &= ~(1 << SWR_SRC_BIT);
  
  //////// set attenuation
  unsigned char usatt = attenuation;
  
  for(int i=0; i<3; i++)
    ((usatt >> i) & 0x01) ? nextState[ATTEN_BYTE - 1] |= (1 << (ATTEN_BIT + i)) : nextState[ATTEN_BYTE - 1] &= ~(1 << (ATTEN_BIT + i));

  //////// set RX sw position
  (rxConn == CONN_30) ? nextState[RX2TXRX_BYTE - 1] |= (1 << RX2TXRX_BIT) : nextState[RX2TXRX_BYTE - 1] &= ~(1 << RX2TXRX_BIT);

  //////// set TX sw position
  (txConn == CONN_TXRX) ? nextState[TX2TXRX_BYTE - 1] |= (1 << TX2TXRX_BIT) : nextState[TX2TXRX_BYTE - 1] &= ~(1 << TX2TXRX_BIT);

  //////// shift data
  shiftData(nextState, CHAIN_SIZE, activeState);   // Shift Chain Data

  //////// set active values
  activeRxChannelID = rxChannelID;
  activeTxChannelID = txChannelId;
  activeRxConn = rxConn;
  activeTxConn = txConn;
  activeNotch = notch;
  activeAttenuation = attenuation;
  activeSwrEn = swrEn;
  activeSwrSrc = swrSrc;
    
  return COMPLETED;
}

void setTxState(unsigned char* state, const unsigned char* txState){
  for(int i = 0; i < CHAIN_SIZE; i++){
      state[i] = (state[i] & ~TX_MASK[i]) | (txState[i] & TX_MASK[i]);
  }
}

unsigned char setMode(unsigned char mode){
  unsigned char nextMCUSetup = 0;
  unsigned char rxChannelID;
  unsigned char txChannelID;
  
  unsigned char iTXRX0 = 0;         // V2
  unsigned char iTXRX1 = 0;         // V3
  unsigned char iLNA_EN = 0;
  unsigned char iPA_EN = 0;
  unsigned char iRELAY = 0;         // 0 - RX; 1 - TX
  unsigned char iBAND38TX = 0;      // 0 - RX; 1 - TX

  rxChannelID = getRxChannelID();
  txChannelID = getTxChannelID();

  if(rxChannelID != CID_NOT_SELECTED){
    activeMode = mode;
    
    if (isCell(rxChannelID)) {                      /////////////////// CELL ////////////////
      iTXRX0 = 0;
      iTXRX1 = 1;
      if (rxChannelID == CID_CELL_BAND38){  
        if (mode == RFE_MODE_TX){                                // TX mode Band 38
          iBAND38TX = 1;
        } else if (mode == RFE_MODE_RX) {                        // RX mode Band 38
          iBAND38TX = 0;
        } else {
          return ERROR_CELL_WRONG_MODE;                          // not TX or RX mode for Band 38
        }
      } else {
          if (mode != RFE_MODE_TXRX){
              return ERROR_CELL_WRONG_MODE;                      // not TXRX mode for (Cell - Band 38)
          }

          if (rxChannelID == CID_CELL_BAND07){
              iBAND38TX = 1;                                     // enable PA for band 7 (the same pa as for band 38)
          }
      }                                                          /////////////////// CELL /////////////////
      
    } else {                                                     /////////////////// HAM & WB /////////////
      switch(mode){
        case RFE_MODE_NONE: {
          iLNA_EN = 0;
          iPA_EN = 0;
          break;
        }
        case RFE_MODE_TX: {
          if (txChannelID == CID_HAM_0030 || txChannelID == CID_HAM_0070) {                    // 30MHz, 70MHz
            iRELAY = 1;
          } else {
            iTXRX0 = 1;
            iTXRX1 = 1;
          }
          iLNA_EN = 0;
          iPA_EN = 1;
          break;
        }
        case RFE_MODE_RX:{
          if (rxChannelID == CID_HAM_0030 || rxChannelID == CID_HAM_0070) {                    // 30MHz, 70MHz
              if (activeRxConn == CONN_TXRX){
                  iTXRX0 = 1;
                  iTXRX1 = 0;
              } else if(activeRxConn == CONN_30){
                  iRELAY = 0;
              }
          } else if ((rxChannelID == CID_HAM_0145) || 
                          (rxChannelID == CID_HAM_0435) || 
                          (rxChannelID == CID_HAM_0220) ||
                          (rxChannelID == CID_WB_1000)) {       // RX_L
            iTXRX0 = 1;
            iTXRX1 = 0;
          } else {                                              // RX_H
            iTXRX0 = 0; 
            iTXRX1 = 0;
          }
          iLNA_EN = 1;
          iPA_EN = 0;
          break;
        }
        case RFE_MODE_TXRX: {
          if(activeTxConn != activeRxConn){                                     // for RXTX rx_conn and tx_conn have to be different        
            if (rxChannelID == CID_HAM_0030 || rxChannelID == CID_HAM_0070) {   // RX_30MHz, RX_70MHz
              if (activeRxConn == CONN_TXRX){
                  iTXRX0 = 1;
                  iTXRX1 = 0;
              } else if(activeRxConn == CONN_30){
                  iRELAY = 0;
              }
            } else if ((rxChannelID == CID_HAM_0145) ||
                            (rxChannelID == CID_HAM_0220) ||
                            (rxChannelID == CID_HAM_0435) ||
                            (rxChannelID == CID_WB_1000)) {     // RX_L
              iTXRX0 = 1;
              iTXRX1 = 0;
            } else if (isRxH(rxChannelID)) {                    // RX_H
              iTXRX0 = 0;
              iTXRX1 = 0;
            }
            
            if (txChannelID == CID_HAM_0030 || txChannelID == CID_HAM_0070) {                  // TX_30MHz, TX_70MHz
              iRELAY = 1;
            } else if(activeTxConn == CONN_TXRX){
              iTXRX0 = 1;
              iTXRX1 = 1;
            }
            
            iLNA_EN = 1;                                        // turn LNAs ON
            iPA_EN = 1;                                         // turn PAs ON
            
          } else {
            iLNA_EN = 0;
            iPA_EN = 0;
            if(!isCell(rxChannelID)){
                // return error "tx_conn = tx_conn"
                return ERROR_RXTX_SAME_CONN;
            }
          }
        break;
        }
      }
    }                                                           /////////////////// HAM & WB /////////////
      
    (iTXRX0 == 1)     ? nextMCUSetup |= (1 << (MCU_BYTE_TXRX0_BIT))   : nextMCUSetup &= ~(1 << (MCU_BYTE_TXRX0_BIT));
    (iTXRX1 == 1)     ? nextMCUSetup |= (1 << (MCU_BYTE_TXRX1_BIT))   : nextMCUSetup &= ~(1 << (MCU_BYTE_TXRX1_BIT));
    (iRELAY == 1)     ? nextMCUSetup |= (1 << (MCU_BYTE_RELAY_BIT))   : nextMCUSetup &= ~(1 << (MCU_BYTE_RELAY_BIT));
    (iLNA_EN == 1)    ? nextMCUSetup |= (1 << (MCU_BYTE_LNA_EN_BIT))  : nextMCUSetup &= ~(1 << (MCU_BYTE_LNA_EN_BIT));
    (iPA_EN == 1)     ? nextMCUSetup |= (1 << (MCU_BYTE_PA_EN_BIT))   : nextMCUSetup &= ~(1 << (MCU_BYTE_PA_EN_BIT));
    (iBAND38TX == 1)  ? nextMCUSetup |= (1 << (MCU_BYTE_BAND38_BIT))  : nextMCUSetup &= ~(1 << (MCU_BYTE_BAND38_BIT));
    
    setupMCU(nextMCUSetup, activeState);
    
  }
  return COMPLETED;
}

boolean isRxH(unsigned char rxCh){
  return  (rxCh == CID_WB_4000 || 
          rxCh == CID_HAM_0920 || 
          rxCh == CID_HAM_1280 || 
          rxCh == CID_HAM_2400 || 
          rxCh == CID_HAM_3500);
}

boolean isRxL(unsigned char rxCh){
  return  (rxCh == CID_WB_1000 || 
          rxCh == CID_HAM_0030 || 
          rxCh == CID_HAM_0070 || 
          rxCh == CID_HAM_0145 || 
          rxCh == CID_HAM_0220 || 
          rxCh == CID_HAM_0435);
}

boolean isCell(unsigned char ch){
  return  (ch == CID_CELL_BAND01 || 
          ch == CID_CELL_BAND02 || 
          ch == CID_CELL_BAND03 || 
          ch == CID_CELL_BAND07 || 
          ch == CID_CELL_BAND38);
}

void wait_for_bytes(int num_bytes, unsigned long timeout){
  unsigned long startTime = millis();
  //Wait for incoming bytes or exit if timeout
  while ((Serial.available() < num_bytes) && (millis() - startTime < timeout)){}
  
}

unsigned char getRxChannelID(){
  return activeRxChannelID;
}

unsigned char getTxChannelID(){
  return activeTxChannelID;
}

void receiveEvent(int howMany) {
  int i = 0;
  while (Wire.available()) {                   // loop through all but the last
    activeBuffer[i] = Wire.read();             // receive byte as a character
    i++;
  }
  unsigned char command = activeBuffer[0];
  if (command == CMD_MODE) {       // cmd_mode is shorter
      activeBufferSize = BUFFER_SIZE_MODE;
  } else {
      activeBufferSize = BUFFER_SIZE;
  }
  if(howMany == activeBufferSize){
    doCommand();
  }
}

void requestEvent() {
  Wire.write(activeBuffer, activeBufferSize);
}

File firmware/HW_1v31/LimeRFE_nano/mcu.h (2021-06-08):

#define GPIO0_PIN               2
#define GPIO1_PIN               3
#define RELAY_PIN               A2
#define RX_SW_PIN0              A1  // sw v2
#define RX_SW_PIN1              A0  // sw v3
#define DATA_RESET_PIN          7
#define DATA_PIN                6
#define DATA_CLK_PIN            5
#define FAN_SENSE_PIN           4
#define ADC1_PIN                A6
#define ADC2_PIN                A7
#define BAND38_TX_ENn_PIN       A3

#define LNA_EN_PIN              10
#define PA_ENn_PIN              9

#define MCU_BYTE_PA_EN_BIT      0
#define MCU_BYTE_LNA_EN_BIT     1
#define MCU_BYTE_TXRX0_BIT      2
#define MCU_BYTE_TXRX1_BIT      3
#define MCU_BYTE_RELAY_BIT      4
#define MCU_BYTE_BAND38_BIT     5

void setupMCU(unsigned char value, unsigned char * currentState);
void enableLNAs();
void disableLNAs();
void enablePAs();
void disablePAs();
void setRelay(unsigned char value);
void setRXTX(unsigned char value);
void setBand38(unsigned char value);
long read_temp();
double conv_temp(long raw_temp);
char getGPIO10( char pin);
void setGPIO10( char pin, char value);
void configGPIO10( char pin, char dir);

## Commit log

2020-02-29 Initial commit - re-initialised repo!
    [30MHz_LPF.sch, BPF1300.sch, BPF145.sch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]
2020-02-29 Add firmware for pre-production boards
2021-06-08 Archive 1v2 hardware, add 1v31 hardware, reorganise the repo and switch to SHL-2.1 for hardware
    [BPF1300.sch, BPF145.sch, BPF220.sch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]
2026-05-20 docs: add RF connectors to User Guide
2026-05-20 docs: User guide updated board figures
2026-05-26 docs: added board components table to v1.0 HW ref
2026-05-26 docs: updated board versions
2026-05-28 docs: updated ref v1.0 LEDs
2026-05-28 docs: added gpios connectors pinout table templates
2026-05-28 docs: added ICSP connector pinout table template
2026-05-28 docs: added ref v1.31 LEDs table
2026-05-28 docs: added ref v1.31 ICSP connector pinout table
2026-06-30 docs: updated heatsinks information
